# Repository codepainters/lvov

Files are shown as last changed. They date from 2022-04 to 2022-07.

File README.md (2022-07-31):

# ПК-01 Львoв

This repository contains all the documentation and notes about ПК-01 Львoв personal computer - probably the ugliest computer I've ever ~~attempted to repair~~ repaired :)

Judge yourself:

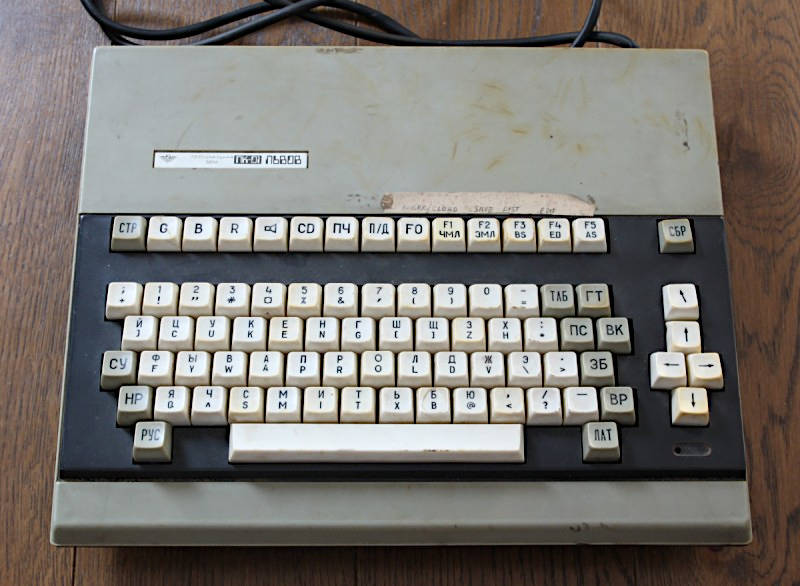
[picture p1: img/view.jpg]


Inside this repository:

* [original](orig) documentation collected from the Internet
* mainboard [schematics](sch)  redrawn into (hopefully) more readable form (KiCAD project + [PDFs](sch/pdf))
* some [datasheets](datasheets) of the chips used
* [ROM](roms) files, both from the Internet, as well as dumped from the desoldered EPROMs
* various notes and [docs](docs), including my design analysis  (look there for details)

And, last but not least, my [repair log](repair).

Enjoy!

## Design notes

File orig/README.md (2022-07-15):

# Original docs

The best quality scans of the original documentation I was able to find.

## Hardware docs

 * main PCB: [schematics](mainboard_schematics.djvu), [layout](mainboard_pcb.jpg)
 * keyboard PCB: [schematics](keyboard_schematics.djvu), [layout](keyboard_pcb.jpg)
 * power supply: [schematics](psu_schematics.djvu), [layout](psu_pcb.jpg), [overview](psu_overview.djvu)
 * [partlist](partlist.djvu)

## Manuals (russian)

* [User's manual](manual_rus.pdf)

* [BASIC reference](basic_manual_rus.pdf)

* [Programmers reference (PDF)](programmers_book_rus.pdf)

* [Programmers reference (UTF-8 TXT)](programmers_book_rus.txt)

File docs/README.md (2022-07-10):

# Docs and notes

Basic docs:

* [list of chips](chips.md) with both Russian and equivalent western symbols
* [map of the board](pcb_map.pdf) , also in [SVG](pcb_map.svg)
* [connectors pinout](connectors.md)
* [SCART cable](scart.md)

Below are my block-by-block analysis of the hardware:

* [CPU and PIO](cpu_pio.md)
* [Timing generator](timing.md)
* [RAM and ROM blocks](memories.md)
* [Video generator](video.md)

Note: I didn't bother with keyboard PCB, nothing interesting there. It's just yet another 8255...

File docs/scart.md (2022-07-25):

# Connecting to TV via SCART

It is possible to connect video output to SCART TV input, however some modifications are necessary:

* 12V rail should be connected via 330R resistor to unused pin 1 of the `X5` video output socket.
  Used to drive:

    * SCART Slow Blank (pin 8) to force the TV to switch to SCART with 4:3 aspect ratio
  
    * SCART Fast Blank (pin 16) to force the TV to switch to RGB signals (as opposed to CVBS default)

* `R`,`G` and `B` signals have to be inverted (it seems there was a different standard in the Soviet Union). This can be done by soldering `7402` quad NOR chip on top of `D62` chip (`К155ЛЛ1`/`7432`, quad 2-input OR gate) as follows.
  
  * solder pins 3, 6, 7, 8 and 14 of the `7402` chip to same numbered pins of `D62`
  * bend pins 2, 5 and 9 and solder to pins 3, 6 and 8, respectively 
  * bend pins 1, 4, 10, 11, 12 and 13 up
  * remove `C53`, `C54` and `C55` output capacitors
  * connect pins 1, 4 and 10 to "minus" pads of `C54`,  `C53` and `C55`, respectively

## Cable

Once the mod is in place, use the following cable:

| DIN-7 | SCART | Signal |
| ----- | --- | --- |
| 1 | 8 | Slow Blank |
| - | 16 | Fast Blank, connect to pin 8 via 330R resistor inside the plug |
| 2 | 20 | CVBS / Sync In |
| 3 | 7 | Blue |
| 4 | 11 | Green |
| 5 | 15 | Red |
| 6 | 4, 5, 9, 13 | GND |

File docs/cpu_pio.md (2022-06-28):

# CPU block

CPU block is a typical 8080 application:

* `D6` - CPU (`8080`)
* `D4` - clock generator and reset signal generator (`8224`)
* `D8` - data bus buffer / control signal latch (`8228`)

* `D2` and `D3` - address bus buffers (`8286`) - these buffers, controlled by `HLDA` signal, allow for DMA operation (not used by on-board hardware, exclusive bus access can be requested by external hardware connected to X1 connector, however).

Note:

* most signals are TTL level, but clock signals `Φ1` and `Φ2` go above 5V level.

* `D5B` flip-flop is used to synchronize CPU and RAM cycles

  * `~STSTB` goes low at the beginning of each CPU cycle, when CPU status is available on the data bus

  *  `ROM_OE` is high for EPROM access, as well as PIO I/O requests, thus `Q` output goes low for RAM access only

  * this in turn causes `READY` line to go low for each RAM request, CPU executes wait states

  * once RAM cycle is completed (see RAM controller description), `VIDEO_CPU` signal is pulsed low, `READY` goes high and CPU completes the RAM read/write cycle.

# PIO block

PIO block is a regular 8255 chip application.

* `D28` demux (`74155`) generates chip select signals:
  * `~CS0` (addresses `0xC0..CF`) selects `D30` PIO chip
  * `~CS1` (addresses `0xD0..DF`) selects second `8255` chip on the keyboard PCB
  * `~CS2` (addresses `0xE0..EF`) and `~CS3` (addresses `0xF0..FF`) signals are routed to `X1` connector (not used otherwise). 
  
* a little trick is used in the address decoder:
  * `~ROM_OE` goes low when `A15` and `A14` lines are high
  
  * however, during I/O cycles, 8080 CPU outputs 8-bit I/O address on both lower and higher byte of the address buss
  
  * it's therefore equivalent to decoding `A7` and `A6` lines, without any extra gates - neat! 

PIO lines are used as follows:

* Port A: `PA[7..0]` lines are routed to `X2` connector via `D31` buffer (`8286`), outputs only

* Port B:

  * `PB[7..0]` signals are routed directly to `X2`
  *  `PB[6..0]` also controls video color palette
  * `PB7` controls a speaker

* Port C:

  * `~PC0` is an output to a tape recorder

  * `~PC1` is used to alter RAM address mapping (see memory block description)

  * `PC4` is tape recorder input

  * `~PC2`, `~PC3`, `PC5`, `PC6`, `PC7` are routed to `X2` connector

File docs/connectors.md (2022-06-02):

# Connectors

## X1 - system bus

Pin 1 is bottom left, 2 is top left (as seen from the outside). 

| Signal | Bottom pin | Top pin | Signal |
| --- | --- | --- | --- |
| RESET  | 1 | 2 | ~CS3 |
| ~I/OR  | 3 | 4 | ~CS2 |
| ~INTA  | 5 | 6 | ~CS1 |
| A13 | 7 | 8 | - |
| A11 | 9 | 10 | +5V |
| A12 | 11 | 12 | - |
| ~MEMW  | 13 | 14 | - |
| A8 | 15 | 16 | - |
| A1 | 17 | 18 | GND |
| A0 | 19 | 20 | - |
| A9 | 21 | 22 | - |
| A2 | 23 | 24 | - |
| A7 | 25 | 26 | - |
| A15 | 27 | 28 | - |
| A14 | 29 | 30 | - |
| A3 | 31 | 32 | - |
| D3 | 33 | 34 | - |
| D2 | 35 | 36 | - |
| D4 | 37 | 38 | - |
| D1 | 39 | 40 | - |
| D5 | 41 | 42 | - |
| D0 | 43 | 44 | - |
| D6 | 45 | 46 | - |
| D7 | 47 | 48 | - |
| A10 | 49 | 50 | HLDA |
| ~MEMR  | 51 | 52 | A4 |
| ~I/OW  | 53 | 54 | A5 |
| INTE | 55 | 56 | A6 |
| INT | 57 | 58 | ~RESIN |
| HOLD | 59 | 60 | φ2TTL  |

## X2 - PIO

Pin 1 is bottom left, 2 is top left (as seen from the outside).

| Signal | Bottom pin | Top pin | Signal |
| --- | --- | --- | --- |
| PB2 | 1 | 2 | - |
| PB1 | 3 | 4 | - |
| PB0 | 5 | 6 | ~PC2 |
| PB3 | 7 | 8 | ~PC3 |
| PB4 | 9 | 10 | - |
| PB5 | 11 | 12 | - |
| PB6 | 13 | 14 | - |
| PB7 | 15 | 16 | - |
| - | 17 | 18 | - |
| PC5 | 19 | 20 | - |
| PC6 | 21 | 22 | - |
| PC7 | 23 | 24 | - |
| PA7 | 25 | 26 | - |
| PA6 | 27 | 28 | - |
| PA5 | 29 | 30 | - |
| PA4 | 31 | 32 | - |
| PA3 | 33 | 34 | - |
| PA2 | 35 | 36 | - |
| PA1 | 37 | 38 | - |
| PA0 | 39 | 40 | GND |

## X3 - tape recorder

| Pin  | Signal |
| ---- | --- |
| 1 | Output (to tape)  |
| 2 | GND |
| 3 | Input (from tape) |

## X4 - power supply

| Pin  | Signal |
| ---- | --- |
| 1 | +12V |
| 2 | +5V |
| 3 | GND |
| 4 | -5V |
| 5 | GND |

## X5 - video output

| Pin  | Signal |
| ---- | --- |
| 1 | - |
| 2 | VIDEO (CVBS mono) |
| 3 | B |
| 4 | G |
| 5 | R |
| 6 | GND |

## Keyboard

Keyboard is connected using wires soldered to numbered pads. Unfortunately, numbers do not match.

| Signal | Mainboard pad | Keyboard PCB pad |
| --- | --- | --- |
| D0 | 8 | 34 |
| D1 | 7 | 33 |
| D2 | 6 | 32 |
| D3 | 5 | 31 |
| D4 | 4 | 30 |
| D5 | 3 | 29 |
| D6 | 2 | 28 |
| D7 | 1 | 27 |
| A0 | 11 | 9 |
| A1 | 12 | 8 |
| ~I/OR  | 14 | 5 |
| ~I/OW  | 15 | 36 |
| RESET  | 13 | 35 |
| ~CS1 | 9 | 6 |
| ~RESIN | 10 | 10 |
| BUZZER | 16 | 16 |

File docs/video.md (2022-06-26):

# Video generator

Note:

* all video timing generation is based on `T[..]` signals from timing block
* additionally, `T_RST1` and `T_RST2` signals act as horizontal and vertical blanking, respectively
  * `T_RST1` is low for 256 horizontal pixels, it then goes 1 for 64 pixel times
  * `T_RST2` is low for 256 lines, it then goes high for 64 line periods
* `PB[0..7]` from `PIO` block is used to control color palette (see below)
* data is pulled directly from RAM data outputs - `RD[0..7]` bus

### Synchronization signals generator

Horizontal synchronization pulse (`~CCU`):

* is generated using `D38C` NAND gate (used as inverter) and `D44A` 4-input NAND gate
* pulse is active when `T[7] == 0 && T[6] == 1 && T_RST1 == 1`
* given that `T_RST1` is high for `T[10..4] == 100_xxxx`, sync pulse is high when `T[10..4] == 100_01xx`
* i.e. it goes high for `T[10..4]` in range 68..71, giving 4 cycles / 1.25 MHz = 3.2 μs width pulse

Vertical synchronization pulses (`~KCU`):

* is generated using `D41A` NAND gate (used as inverter) and `D44B` 4-input NAND gate

* pulse is active when `T[9] == 1 && T[15] == 1 && T[16] == 0 && T_RST2 == 1`

* given that `T_RST2` is high for `T[19..11] == 1_00xx_xxxx`, sync pulse is high when `T[19..11] == 1_0001_xxxx`and `T[9] == 1`

  * 16 pulses are generated for equivalent of 16 scan lines - 16 * 1/15625 Hz = 1024 μs 
  * for each scan line period `T[9]` is low for 32 clocks of modulo 80 counter, then high for 32 cycles and low again for 16 cycles. 
  * this gives 32 / 1.25 MHz = 25.6 μs low,  then 25.6 μs high, then 12.8 μs low

Horizontal and vertical sync pulses are combined using `D41B`NAND gate.

### Pixel shift register

Parallel load shift register `74198` is used to convert RAM contents into consecutive pixels. Data is loaded from RAM directly (`RD[7..0]`bus), load and shift signals are timed by the `T[3..0]` signals from the timing blocks, using `D33B` , `D37A` and `D37B` gates. 

Video SR timing

During a single RAM cycle (see RAM controller description) one byte is loaded from RAM and 4 shift operations are performed - each byte describes 4 pixels, 2 colors per pixel. Byte layout is as follows, where `P<n>.1`and `P<n>.0` denote, respectively, higher and lower color bit of `n-th` pixel in byte:

| 7 | 6 | 5 | 4 | 3 | 2 | 1 | 0 |
| ---- | ---- | ---- | ---- | ---- | ---- | ---- | ---- |
| P0.1 | P1.1 | P2.1 | P3.1 | P0.0 | P1.0 | P2.0 | P3.0 |

### Composite signal generator

Generation of the composite video signal works as follows:

* shift register outputs are converted into 4 brightness levels using `R27` and `R28` resistors
* `D62D` and `D29A` gates are responsible for blanking the output when `T_RST1` or `T_RST2` is high, i.e. during horizontal or vertical retrace, respectively.
* `D61D` and `D29B` gates, together with `R19`, `R20` and `R23` resistors generate proper synchronization levels.

Note: CVBS output is also used as synchronization signal for color monitor.

### RGB signal generation

* 2 color bits from shift register are used as `D56` demux select inputs. 
  * demultiplexer outputs are used to select one of the 4 colors
  * active-low enable inputs of the demultiplexer are controlled by `T_RST1` and `T_RST2` signals, effectively blanking the video when `T_RST1` or `T_RST2` is high
* selected color is  converted into R, G and B signals by combining with `PB[6..0]` signals (effectively limited color palette control)

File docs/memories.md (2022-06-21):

# Memories

## ROM

* 8 chips, 2716 equivalent
* `D5A` flip-flop is responsible for ROM remapping
  * at reset,  `~Q` of `D5A` is low, thus `~ROM_OE` is always low and ROM is effectively mapped 4 times in the CPU address space
  * when CPU writes any I/O port for the first time,  `~Q` goes high, and ROM is mapped into last 16 KB of CPU address space (`0xC000..0xFFFF`)
* this mapping trick is necessary for the CPU to boot from ROM at address 0, the code then perform dummy I/O write to map ROM into its target location 

## RAM

* 8 chips, 4164 DRAM equivalent, one per bit, 64kB total.
* memory refreshing done while generating video.
* RAM output data bus `RD[7..0]` is separated from CPU data bus `D[7..0]` by 8282 latch (`D27`). Latch is strobed by `RAM_RD_STB` signal from RAM controller (see below), output enable is active for every memory read that is not EPROM read (`ROM_OE == 0 && ~MEMR == 0`).
* Quad 74153 multiplexers select row / column address and address source (CPU or timing counters for video output).

### Addressing 

* for video generator access:
  * 2 MSB bits are set to 1, bits `13..0` are formed from `T[18..11]`,  `T[9..4]`
  * video is thus generated from 256 x 64 bytes = 16 kB, 4 pixels each, located at `0xC000..0xFFFF` in the CPU address space
* for CPU access `A[14..0]` signals are used as is, while most significant bit is combined with `~PC1` 
  * if `PC1 == 1`, the `A[15]` is used as MSB
  * if `PC1 == 0`, MSB is forced to 1, effectively higher 32kB of RAM are mapped twice in the CPU address space

This mapping is necessary to manipulate video buffer from ROM code, as ROM is also mapped to the last 16 kB of address space. This mapping is explained as follows in the programmer's manual:

> In normal mode, the on-screen RAM is disconnected from the MP buses and cannot be accessed by software. For the MP to work with this RAM area, it can be connected instead of the main RAM section at addresses 4000H-7FFFH ( 16384-32767 ) using bit 1 of the C2H port ( 194 ) ( 0 - Open Video RAM, 1 - Close Video RAM ). However, it should be remembered that with such a switch, the main RAM area 0000H-7FFFH ( 00000-32767 ) is disconnected from the MP buses, so procedures that work with open video memory cannot be placed below 8000H ( 32768 ). All the main ROM routines that work with the screen "do not forget" to close the video memory before returning and there is no such problem with them.

## RAM controller

RAM controller is responsible for generating all RAM-related signals - `~RAS`, `~CAS`, `~WE`, etc.

* controller is driven by `T[3..0]` signals from timing counter, i.e. the whole sequence (let's call it *RAM cycle*) takes 16 periods of 20 MHz `OSC` clock.
  * it is further divided into *video RAM cycle* (cycles 0 - 7), when video controller reads next byte from RAM, and *CPU RAM cycle* when CPU can read or write a RAM byte.
  * the *CPU RAM cycle* is optional, it happens only if the CPU actually requested memory access
* signals `K0` and `K1` control RAM address multiplexer:
  * `K0` selects row (when 0) or column (when 1) address
  * `K1` selects source of RAM address - timing/video circuitry (when 0), or CPU (when 1)

Following diagram shows a full RAM cycle.

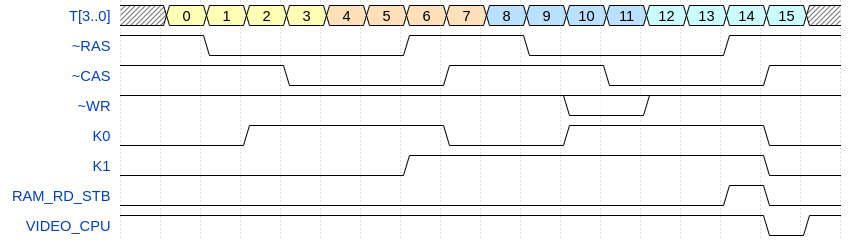
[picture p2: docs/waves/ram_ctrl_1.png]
ram_ctrl_1


Note:

* `K1` goes high only if there is actual CPU RAM cycle
  * when `~MEMR` or `~MEMW` goes low, `D42A` flip-flop catches `ROM_OE` state, which is high during EPROM access. Thus, its `~Q` output goes high only at the beginning of the RAM read or write cycle;
  * at the beginning of period 6, this state is copied to `D42B`, thus `K1` goes high if and only if the CPU requested RAM read/write;
  * `K1` them remains high until a pulse of `VIDEO_CPU` signal (which happens only if `K1` was high)
  * CPU enters wait states until `VIDEO_CPU` pulse signals end of cycle (see CPU block description)
* signals `~WR` only goes low for memory write, obviously
* signal `RAM_RD_STB` is used to control the D27, which latches the byte from RAM data bus `RD[7..0]` and outputs it to CPU data bus `D[7..0]` (data is latched on the falling edge)
* signals `~RAS`, `~CAS` remain inactive (i.e. high) for periods 8..15 when there is no CPU RAM access happening  

* the `D47C` is somewhat peculiar, my understanding: this gate ensures, that there is at least one `VIDEO_CPU` pulse during reset, to make sure CPU doesn't get stuck in wait state.

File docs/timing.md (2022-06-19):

# Timing block

The timing block consist of  3 cascaded counters, driven by `OSC` 20 MHz clock. 

### Modulo 16 counter

* uses a single `74LS193` counter (`D34`)

* it overflows with 20 / 16 = 1.25 MHz frequency

* it drives signals `t[0..3]`, which:
  * control RAM access timing
    * when `T[3] == 0` video controller reads a next byte (4 pixels) to be displayed
    * when `T[3] == 1` CPU can issue a RAM read/write
  * control pixel shift register in the video block

### Modulo 80 counter

* uses `74LS193` counter (`D35`) and `74LS93` counter (`D36`) cascade
* drives `T[4..10]` signals, which:
  * provide part of RAM address for the video generator
  * are used to generate horizontal synchronization signal in the video block
* modulo counting is done in a somewhat peculiar way:
  * `D37C` AND gate output (`T_RST1` signal) goes high when counter gets to 64 (`T[10..4] == 100_0000`)
  * when it reaches 80 (`101_0000`), `D37C` output goes low
  * this triggers `D43A` monostable multivibrator, which outputs short (~500-600 ns) pulse, resetting the counter
* `D37C` output (`T_RST1` signal) is also used by the video block (it is high for counts in `64..79` range), i.e. 16 cycles of `T[3]` which gives `12.8 µs`
* this counter block overflows with 15625 Hz frequency (which happens to be the horizontal deflection frequency)

### Modulo 320 counter

* uses `74LS93` counters (`D39` and `D40`), followed by `7474` flip-flop (`D45A`)
* drives `T[11..19]`signals (used as part of RAM address in the video block, and to generate vertical sync pulses)
* modulo counting is done in the same manner as in modulo 80 counter block
* `D37D` output (`T_RST2` signal) goes high when `T[19..11]` is `1_0000_0000` and goes back low when `1_0100_0000` is reached, triggering reset, the pulse width is `64 * 1/15625 Hz = 4.096 ms`
* this counter wraps every 15625 / 320 = ~48.82 Hz (which is the screen refresh rate) 

### Counter synchronization

Note: reset signals from both `74123` multivibrators (i.e. `D43A` and `D43B`) are combined using `D38B` NAND gate, combined signal is sued to reset modulo 80 counter.  My understanding is that this is for modulo 80 counter to start in sync with  modulo 320 counter.

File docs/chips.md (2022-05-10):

# Chip list

| Designator | Orig. type | Equivalent | Desciption |
| --- | --- | --- | --- |
| D1 | К155ЛА4 | 7410 | Triple 3-input NAND gates |
| D2 | КР580ВА86  | i8286 | Octal bus trasceiver |
| D3 | КР580ВА86  | i8286 | Octal bus trasceiver |
| D4 | КР580ГФ24  | i8224 | Clock generator/driver for 8080A CPU |
| D5 | К155ТМ2 | 7474 | Dual D-type flip-flops |
| D6 | КР580ВМ80  | i8080 | 8080A CPU |
| D7 | К155ЛИ1 | 7408 | Quadruple 2-input AND gates |
| D8 | КР580ВК28  | i8228 | System controller and bus driver for 8080A CPU |
| D9 | К555ИД7 | 74LS138 | 1-of-8 decoder/demultiplexer |
| D10-D17 | К573РФ5 | 2716 | 8x 2kB EPROM |
| D18 | К155ЛЛ1 | 7432 | Quad 2-input positive-OR gates |
| D19-D26 | КР565РУ5Д  | 4164 | 8x 64k x 1 DRAM |
| D27 | КР580ИР82  | i8282 | Octal latch |
| D28 | К155ИД4 | 74155 | Dual 2-line to 4-line decoders/demultiplexers |
| D29 | К155ЛА8 | 7401 | Quad 2-input NAND gates with open-collector outputs  |
| D30 | КР580ВВ55А | i8255 | Programmable peripheral interface |
| D31 | КР580ВА86  | i8286 | Octal bus trasceiver |
| D32 | КР589АП26  | i8226 | Bidirectional bus driver |
| D33 | КР531ЛН1 | 74S04 | Six inverters |
| D34 | К555ИЕ7 | 74LS193 | Synchronous 4-bit up/down counter |
| D35 | К555ИЕ7 | 74LS193 | Synchronous 4-bit up/down counter |
| D36 | К555ИЕ5 | 74LS93 | 4-bit binary counter |
| D37 | К155ЛИ1 | 7408 | Quadruple 2-input AND gate |
| D38 | К155ЛА3 | 7400 | Quad 2-input NAND gates |
| D39 | К555ИЕ5 | 74LS93 | 4-bit binary counter |
| D40 | К555ИЕ5 | 74LS93 | 4-bit binary counter |
| D41 | К155ЛА3 | 7400 | Quad 2-input NAND gates |
| D42 | К155ТМ2 | 7474 | Dual D-type flip-flops |
| D43 | К155АГ3 | 74121 | Monostable multivibrator with Schmitt-trigger inputs |
| D44 | К155ЛА1 | 7420 | Dual 4-Input positive-NAND gates |
| D45 | К155ТМ2 | 7474 | Dual D-type flip-flops |
| D46 | К155ТМ2 | 7474 | Dual D-type flip-flops |
| D47 | К155ЛИ1 | 7408 | Quadruple 2-input AND gates |
| D48 | К155ТМ2 | 7474 | Dual D-type flip-flops |
| D49 | К155ИД7 | 74LS138 | 3-line to 8-line decoders/demultiplexers |
| D50 | К155ИД7 | 74LS138 | 3-line to 8-line decoders/demultiplexers |
| D51 | К155КП2 | 74153 | Dual 4-line to 1-line data selectors/multiplexers |
| D52 | К155КП2 | 74153 | Dual 4-line to 1-line data selectors/multiplexers |
| D53 | К155КП2 | 74153 | Dual 4-line to 1-line data selectors/multiplexers |
| D54 | К155КП2 | 74153 | Dual 4-line to 1-line data selectors/multiplexers |
| D55 | К155ИР13 | 74198 | 8-bit shift register |
| D56 | К155ИД4 | 74155 | Dual 2-line to 4-line decoders/demultiplexers |
| D58 | УД708 | LM741 | Op-amp |
| D59 | К155ЛЛ1 | 7432 | Quad 2-input positive-OR gates |
| D60 | К155ЛИ1 | 7408 | Quadruple 2-input AND gates |
| D61 | К155ЛП5 | 7486 | Quad 2-input EX-OR gates |
| D62 | К155ЛЛ1 | 7432 | Quad 2-input positive-OR gates |

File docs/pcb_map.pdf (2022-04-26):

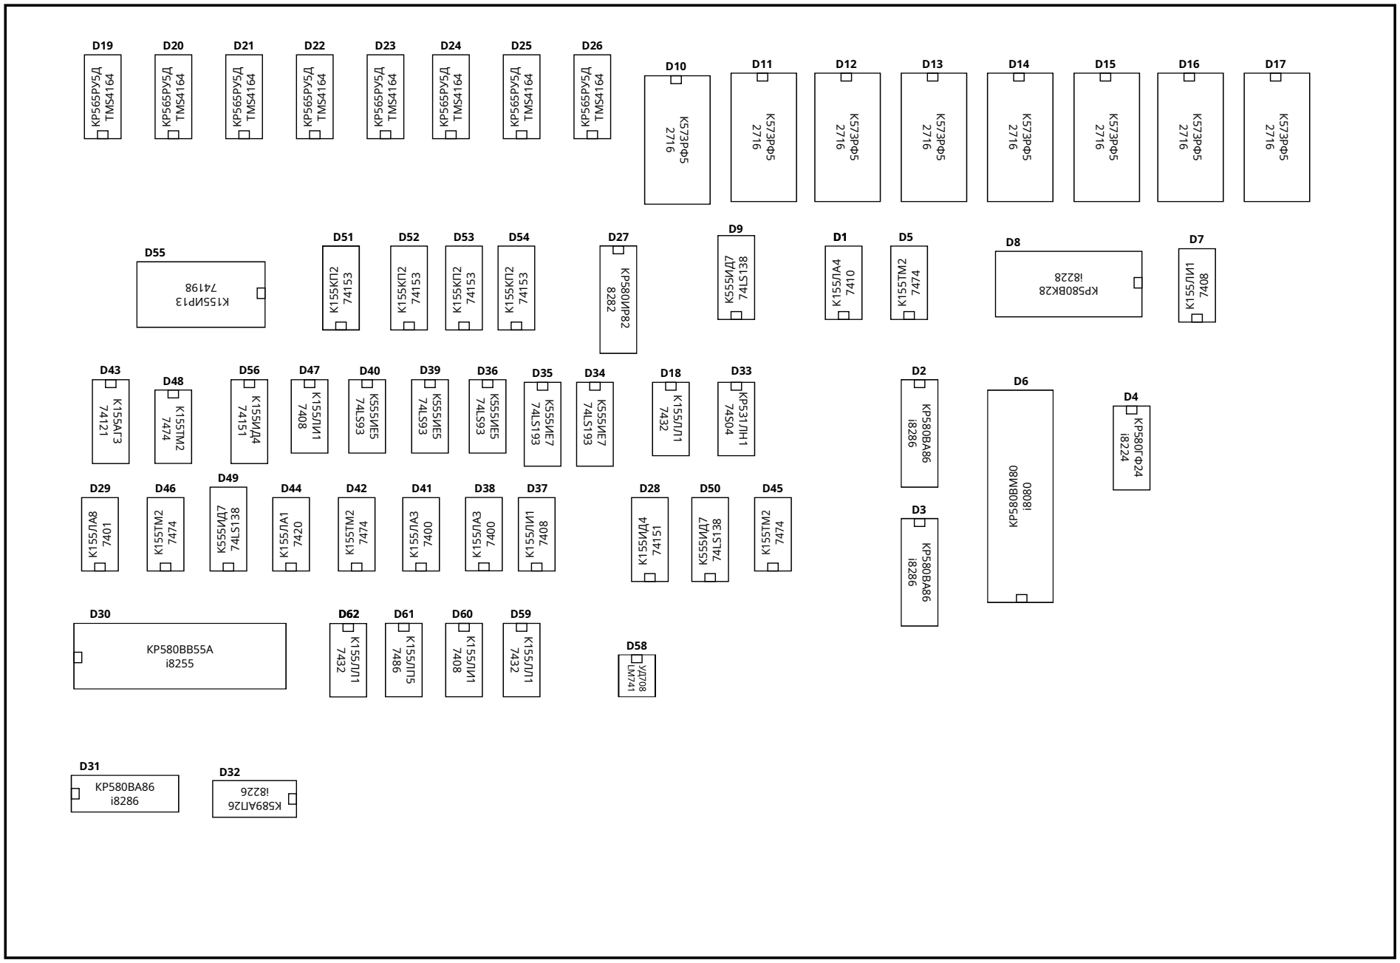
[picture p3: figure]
KP565РУ5Д TMS4164

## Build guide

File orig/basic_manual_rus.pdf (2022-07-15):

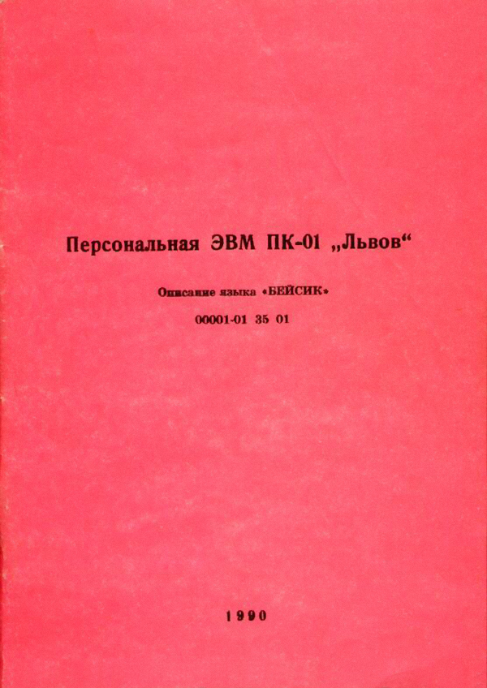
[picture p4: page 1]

ПЕРСОНАЛЬНАЯ ЭВМ ПК-01 "ЛЬВОВ" Описание языка БЕЙСИК 589.0196339.OOOO1-O1 35 01

УТВЕРЖДЕН
589.0196339.OOOO1-O1 35 O1-ДУ

ПЕРСОНАЛЬНАЯ ЭВМ ПК-01 "ЛЬВОВ"
Описание языка БЕЙСИК 589.0196339.OOOO1-O1 35 01

СОДЕРЖАНИЕ

Аннотация
1. Общие сведения и способ описания языка
1.1. Назначение языка
1.2. Способ описания языка
2. Элементы и основные конструкции языка
2.1. Набор символов
2.2. Структура программы и комментарии к программе
2.3. Стандартные функции
3. Элементы данных
3.1. Числовые и символьные данные
3.2. Переменные с индексами
4. Выражения и оператор присваивания 4 1. Арифметические выражения
4.2. Символьные функции и выражения
4.3. Логические выражения
4.4. Оператор присваивания
5. Операторы управления
5.1. Операторы перехода и оператор STOP
5.2. Условные операторы
6. Оператор цикла FOR-NEXT
7. Функции
8. Подпрограммы
8.1. Операторы GOSUB и RETURN
8.2. Оператор ON - GOSUB
9. Средства машинной графики и средства управления звуком
9.1. Формирование изображения на экране терминала
9.2. Графические операторы
9.3. Средства управления звуком
10. Средства работы на уровне машинных команд
11. Работа в режиме непосредственного исполнения
11.1. Режим калькулятора
11.2. Использование режима непосредственного исполнения при отладке программ
12. Операторы ввода - вывода
12.1. Операторы READ, DATA, RESTORE
12.2.Оператор INPUT
12.3.Оператор PRINT
12.4. Дополнительные возможности оператора PRINT
12.5. Управление курсором
13. Средства подготовки и отладки программ
13.1. Директивы интерпретатора и средства отладки программы
13.2. Диагностические сообщения интерпретатора
13.3. Средства редактирования
Приложение: Дополнительные операторы БЕЙСИКа

АННОТАЦИЯ

В настоящем документе содержится описание языке БЕЙСИК, правила составления и выполнения программ на языке бейсик.
В документе описаны основные элементы языка БЕЙСИК: константы, переменные, массивы. Представлены операторы, функции, которые содержит интерпретатор БЕЙСИК, а также способ написания функций, составленных самим пользователем.
Описаны операторы для работы с массивами. Представлены команды для отладки и запуска программных файлов.
Описана система ввода-вывода.

### 1. ОБЩИЕ СВЕДЕНИЯ И СПОСОБ ОПИСАНИЯ ЯЗЫКА

### 1.1. Назначение языка

Язык БЕЙСИК является одним из простых в изучении языков программирования.
Предназначен | для | решения | вычислительных | и | планово-экономических | задач,
проведения инженерных расчетов, разработки тестовых, игровых, учебных программ. Программа на языке БЕЙСИК представляет собой набор операторов, объединенных в логические блоки.
Диалоговый режим интерпретатора БЕЙСИК облегчает отладку программ. Возможна работа в режиме непосредственного исполнения.

### 1.2. Способ описания языка

При описании форматов предложений (синтаксиса предложений) языка применяются следующие условные обозначения: заглавные буквы, знаки пунктуации и другие специальные знаки (за исключением угловых, квадратных и фигурных скобок), изображающие конструкции, которые должны быть записаны в таком же виде, как показано в приводимом формате.
Последовательности слов, записанные строчными буквами и заключенные в угловые скобки <и>, определяют синтаксические конструкции, которые записаны где-либо в другой части данного документа. Эти слова в какой-то мере отражают природу и смысл таких конструкций. Если последовательность конструкций заключена в квадратные скобки [и], то это означает, что данная последовательность является необязательной и может быть опущена. Варианты последовательностей конструкций, заключенные в фигурные скобки {и}, являются альтернативными и должен быть выбран один из этих вариантов.

### 2. ЭЛЕМЕНТЫ И ОСНОВНЫЕ КОНСТРУКЦИИ ЯЗЫКА

### 2.1. Набор символов

В языке БЕЙСИК ПК-01 используются следующие символы:
1) 26 букв латинского алфавита (А, В, С, D, Е, F, G, Н, I, J , К, L, М, N, 0, P, Q, R, S, Т, U, V, W, X, У , Z).
2) 31 буква русского алфавита (А, Б, В, Г, Д, Е, Ж, 3, И, Й, К, Л, М, Н, О, П, Р, С, Т, У, Ф, X, Ц, Ч, Ш, Щ, Э, Ы, Ю, Я, Ь), твердый знак (Ъ) в тексте отображается символом "_".
3) 10 десятичных: цифр (0, I, 2, 3, 4, 5, 6, 7, 8, 9).
4) знаки арифметических операций:
+ - плюс;
- - минус;
* - звездочка;
/ - наклонная черта (знак деления);
^ - стрелочка (знак возведения в степень).

5) знаки операций отношения: < - знак меньше;
> - знак больше;
= - знак равенства.
6) синтаксические знаки;
( - открывающая круглая скобка; ) - закрывающая круглая скобка; , - запятая;
. - точка;
" - кавычки;
; - точка с запятой;
: - двоеточие.
7) специальные знаки:
$ - знак денежной единицы (признак символьных данных);
? - вопросительный знак;
" " - пробел.

Некоторые комбинации символов имеют специальное значение: <= - меньше или равно;
>= - больше или равно;
<> - не равно.

Употребление слов русского алфавита ограничено по сравнению с английскими буквами (как правило, буквы русского алфавита употребляются только как элементы символьных констант и в операторах комментария).

### 2.2. Структура программы и комментарии в программе

В языке программирования БЕЙСИК программа состоит из строк операторов. Каждая строка начинается с номера строки. Номер строки - это целое десятичное число в диапазоне от 0 до 65629. За номером строки располагается служебное слово, определяющее характер действия и текст оператора.
Номера строк служат метками операторов, а также указывают порядок выполнения программы.
При составлении программы рекомендуется нумеровать строки с определенным шагом (например: 10,20,30 и т.д.). Это позволит при отладке вставлять пропущенные или дополнительные строки.
Программа завершается оператором END. Программа также может выполняться без наличия оператора END.
В одной строке может быть записан один или несколько операторов. При записи в одной строке нескольких операторов их следует разделять двоеточием (:). Однако длина строки не должна превышать 254 знаков.
При вводе программы с клавиатуры терминала каждую строку заканчивают нажатием клавиши ВК (возврат каретки).
При вводе или написании программы возникает необходимость в дополнительных пояснениях к программе, предназначенных для объяснения назначения программы, описания назначения ее переменных данных, описания алгоритма и т.п. Для этих целей используется оператор REM. Формат оператора:

<номер строки> REM <сообщение>

где сообщение может содержать любые печатные знаки клавиатуры.
Сообщение, следующее за словом REM, никаких действий интерпретатора не вызывает.

### 2.3. Стандартные функции

Для вычисления наиболее встречающихся математических функций в БЕЙСИК включены следующие стандартные функции:
ABS (X) - модуль
SGN (X) - знак Х (-1 при Х<0; 1 при Х>0; 0 при Х=0)
INT (X) - наибольшее целое число, которое меньше или равно Х COS (X) - косинус Х (cos X)
SIN (X) - синус X (sin x)
TAN (X) - тангенс Х (tg X)
ATN (X) - арктангенс Х (arctg X)
SQR (X) - корень квадратный от Х (sqrt X)
ЕХР (X) - экспонента Х (e^X)
LOG (X) - натуральный логарифм (ln X)
RND (X) - выборка случайного числа в интервале (0,1) (обращение к генератору случайных чисел).
Аргументом функции может быть любое арифметическое выражение.
Аргументы тригонометрических функций SIN, COS, TAN должны задаваться в радианах. В функции RND (X) необходимо указать фиктивный аргумент, например X.

### 3. ЭЛЕМЕНТЫ ДАННЫХ

### 3.1. Числовые и символьные данные

Для того чтобы интерпретатор мог обеспечивать формирование соответствующих команд для обработки информации, ему должен быть известен тип данных, которые подлежат обработке. В языке БЕЙСИК ПК-01 используются данные двух типов:
1) числовые данные;
2) символьные данные.
Числовые | данные | представляются | десятичными | числами | - | целыми | и
действительными.
Целое число - это конечная последовательность цифр с возможным знаком плюс или минус перед ней, например: 1986, -36, +125.
Действительные | десятичные | числа | записываются | двумя | способами | - | с
использованием десятичной точки (в естественной форме) или с использованием латинской буквы E (в нормализованной форме), например: +14.6, -3.75, 2.5, 1E-10, -36.7Е5, +25Е-4.
Диапазон числовых данных от 0,94.10^-38 до 1,7.10^38. Разрядность - 6 десятичных цифр.
Символьная константа (строка) - это последовательность символов из набора символов БЕЙСИК ПК-01, заключенных в кавычки, например: "BASIC", "2+3", "ЛЬВОВ", "АТЫ БАТЫ".
Символьная строка может содержать от 0 до 255 символов. Объем памяти, выделенной под символьные константы можно определить при помощи функции FRE (см. раздел 11).

Величины, значения которых в процессе выполнения программ могут меняться, называются переменными. В БЕЙСИКе ПК-01 употребляются два типа переменных -числовые и символьные. Числовая переменная обозначает место в памяти компьютера, в которое будет записано числовое значение. Символьная переменная резервирует место для символьных значений. В БЕЙСИКе употребляются простые переменные и переменные с индексами. Переменные с индексами предназначены для обозначения элементов массивов и описываются дальше.

Числовая переменная обозначается в БЕЙСИКе ПК-01 идентификатором, который состоит из одной или двух латинских букв или латинской буквы и последующей цифры, например: X, P1, RD, A2.
Переменным присваиваются значения с помощью оператора присваивания LET, операторов INPUT, READ, которые будут описаны далее. Перед выполнением всем переменным присваивается значение 0.

Наряду с числовыми переменными в языке БЕЙСИК ПК-01 используются символьные переменные, которые могут принимать значения символьных констант. Любое имя переменной, за которой следует знак $ (знак денежной единицы), указывает символьную переменную, например: A$, A2$, DM$, RG$.
Над символьными переменными и (или) константами могут выполняться следующие операции отношения: =, <>, <, <=, >, >=.
При выполнении перечисленных операций сравнения каждая символьная строка представляется в виде целых чисел. Каждому символу отвечает целое число (в соответствии с кодом КОИ-7). При сравнении строк их длины предварительно выравниваются путем приписывания справа к более короткой недостающего числа пробелов.

### 3.2. Переменные с индексами

Массивом называется конечная совокупность величин, обозначенных одним и тем же идентификатором и поставленных в соответствие упорядоченным набором значений некоторой системы целочисленных параметров, каждый из которых может принимать любое значение, начиная с нуля и кончая некоторым своим наибольшим значением. Элемент массива называется переменной с индексами. В одном массиве могут содержаться величины только одного типа. Поэтому различают массивы числовых данных и массивы символьных данных.
Общий идентификатор всех величин, входящих в состав массива, называется идентификатором массива. Им может быть любое принятое в БЕЙСИКе ПК-01 имя переменной. При этом идентификаторы массивов символьных величин оканчиваются знаком денежной единицы ($).
Индексная переменная обозначается записью, состоящей из идентификатора массива и следующего за ним в круглых скобках списка индексов. Число индексов не должно превышать два и в списке они разделяются запятой. Индекс в общем случае является арифметическим выражением. В момент использования индекс должен иметь положительное целое значение. Индексы элементов массивов принимают значения целых чисел, начиная с 0, т.е. для одномерного массива элементы нумеруются A(0), А(1), А(2) и т.д.; соответственно элементы двумерного массива - В(0,0), В(0,1), В(0,2) ... В(1,0), В(1,2) и т.д.
Для каждого массива в программе должен быть указан его максимальный размер, т.е. максимальные значения, которые могут принимать индексы. Это нужно для того, чтобы интерпретатор мог зарезервировать соответствующий объем памяти. Информацию об идентификаторах массивов и их размерностях указывают в операторе DIM, который имеет следующий формат:

<номер строки> DIM V1(M1), V2(M2) ... Vn(Mn)

где V1 - идентификатор массива;
M1 - размерность массивов V1 (одно или два целых числа, разделенных запятыми).
Пример:
10 DIMA(10),MT(3,4),S$(6)
Под массив A отводится 11 элементов, под матрицу MT - 4х5 = 20 элементов и под символьный массив S$ - 7 элементов. Описание массивов должно предшествовать использованию их элементов в других операторах.
Если в программе размерность индексной переменной не указывается с помощью оператора DIM, то по умолчанию принимается размерность 10 в каждом измерении. Оператор DIM относится к невыполняемым операторам.
Первоначально все элементы описанных массивов имеют нулевые значения. Для изменения значений индексных переменных используют те же операторы БЕЙСИК ПК-01, что и в случае простых переменных: оператор присваивания READ и INPUT.

### 4. ВЫРАЖЕНИЯ И ОПЕРАТОР ПРИСВАИВАНИЯ

### 4.1. Арифметические выражения

Арифметические | выражения | представляют | собой | произвольную | комбинацию
идентификаторов, констант и функций, разделенных знаками операций и круглым скобками так, чтобы образовать имеющее смысл математическое выражение. Допустимы следующие знаки операций:
+ - сложение;
- - вычитание;
* - умножение;
/ - деление;
^ - возведение в степень.

Если в выражении отсутствуют круглые скобки, определяющие порядок выполнения операций, то они выполняются в следующей последовательности:
- вычисление функций;
- возведение в степень;
- умножение и деление;
- сложение и вычитание.

Операции одного ранга выполняются последовательно слева направо (включая и операции возведения в степень).
Над целыми числами могут выполняться логические операции AND, OR, NOT. Эти операции выполняются поразрядно над двоичными представлениями целых чисел в дополнительном коде. Результатом логической операции является целое число, состоящее из последовательности битов, образованных в результате применения данной логической операции к битам заданных операндов.
Пример:
2OR3=3
2AND3=2
NOT3=-4

Чтобы понять эти результаты, необходимо помнить, что целые десятичные числа в ПК-01 представляются как двоичные числа в дополнительном коде (при этом старший разряд отводится под знак числа).
Если в арифметических выражениях употребляется и арифметические, и логические операции, то при отсутствии скобок логические операции выполняются после арифметических, причем в таком порядке старшинства между собой: NOT, AND, OR. Логические операнды одного ранга выполняются слева направо.

### 4.2. Символьные функции и выражения

Под символьным выражением понимается любая последовательность символьных констант, переменных и функций, соединенных с помощью операции конкатенации (+). Операция конкатенации определяет, что два операнда соединяются вместе и образуют новую строку символов, где за последним символом левого операнда сразу же следует первый символ правого операнда. Длина строки, полученной в результате, равна сумме длин операндов, например: "ТРАМ" + "ТАРАРАМ" = "ТРАМТАРАРАМ".
В БЕЙСИКе ПК-01 могут использоваться следующие функции над символьными строками:
LEFT$(<строка>, N) - выделяет из "строки" подстроку с первого до N-го знака. Здесь и далее над аргументом <строка> будем понимать символьное выражение, а аргумент N (в других функциях N1, N2) должен быть целым числом или выражением, принимающим целочисленное значение. Если N равно или больше длины отроки, выдается вся строка. Если N=0, выдается пустая строка. Например: функция LEFT$("ABCD", 3) дает результат "АВС".
RIGHT$(<строка>, N) - выделяет наиболее правые символы "строки". Если N равно или превышает длину строки, выдается вся строка. Если N=0, выдается пустая строка. Например: функция RIGHT$("ABODE", 2) дает строку "DE".

MID$(<строка>, N1, N2) - проверяет "строку" и возвращает N2 символов, начиная с позиции N1. Если N1 больше, чем строка, MID$ возвращает пустую строку. Например: функция MID$("ABCDE", 2, 3) дает результат "BCD".
LEN(<строка>) - функция определяет длину строки, то есть возвращает целое число, равное количеству символов в строке. Например: функция LEN("ABCDE") дает результат 5.
VAL(<строка>) - функция преобразует цифровую строку в числовое значение. Строка может включать цифры, знаки "+", "-", "." и "Е". Если строка содержит другие знаки, то значение функции равно нулю. Например: функция VAL("1E3") дает числовое значение 1000.
STR$(<выражение>) - действие функции противоположно действию функции VAL -
она | преобразует | числовое | значение | в | цифровую | строку. | Например: | функция
STR$(9372) дает строку "9372".
ASC(<строка>) - функция возвращает код КОИ-7 первого символа указанной строки. Например: функция ASG("ABCD") дает значение 65.
CHR$(<выражение>) - функция возвращает символ КОИ-7, код которого равен значению выражения. Выражение должно приводиться к целому числу между 0 и 255. Например: функция CHR$(65) дает символ "А".
HEX$(<выражение>) - функция возвращает строку, значение которой эквивалентно шестнадцатеричному представлению выражения. Например: функция HEX$(32) дает строку "20".
INKEY$ - функция (без аргумента), предназначенная для опроса клавиатуры. Функция возвращает пустую строку, если не нажата ни одна клавиша, или строку с символом, соответствующим нажатой клавише.

### 4.3. Логические выражения

Логическим выражением называют некоторую комбинацию констант и переменных (числовых или символьных), соединенных знаками операции отношения, логических и арифметических операций и скобками, и принимающие только два значения - "истина" или "ложь" (0 или 1).
Для логических выражений установлен следующий порядок выполнения действий:
1) сначала действует правило скобок;
2) вычисляются значения функций;
3) выполняются арифметические операции в следующем порядке:
- возведение в степень;
- умножение и деление;
- сложение и вычитание.
4) выполняются операции отношения: = - равно;
< - меньше;
<= - меньше или равно;
> - больше;
>= - больше или равно;
<> - не равно.
5) логические операции в следующем порядке: NOT - логическое отрицание;
AND - конъюнкция;
OR - дизъюнкция.

Операция отношения устанавливает определенные отношения между числовыми или символьными величинами. Отношение имеет формат:

<выражение 1 (арифметическое или символьное)> <знак операции отношения> <выражение 2 (арифметическое или символьное>

Символьное отношение означает последовательное попарное сравнение слева направо символов строк операндов в соответствии с упорядоченностью символов кода КОИ-7.
Результат выполнения операций отношения есть "истина", если выражения удовлетворяют отношению, и "ложь" в противном случае.

### 4.4. Оператор присваивания

Оператор присваивания LET имеет формат:

< номер строки> LET <переменная> = <выражение>

Действие этого оператора состоит в вычислении значения выражения, записанного справа от знака равенства, и присвоении этого значения переменной, указанной слева от знака равенства.
Пример:
10 LETA=6.3
20 LETB=B+2
30 LETA$="BASIC"
В | операторе | присваивания | могут | употребляться | переменные | числового | и
символьного типа, простые и с индексами. Необходимо, чтобы тип переменной совпадал с типом выражения (т.е. числовая переменная и арифметическое выражение, символьная переменная и символьное выражение).
БЕЙСИК ПК-01 позволяет опускать слово LET в операторе.
Пример:
10 A=6.3
20 B=B+2
30 A$="BASIC"

### 5. ОПЕРАТОРЫ УПРАВЛЕНИЯ

### 5.1. Операторы перехода и оператор STOP

В программе на языке БЕЙСИК ПК-01 операторы выполняются в порядке возрастания номеров строк. Изменение порядка выполнения оператора производятся с помощью операторов управления. К этой группе операторов относятся операторы перехода, оператор STOP, условные операторы и оператор цикла.
В языке БЕЙСИК ПК-01 существует два вида операторов перехода - оператор безусловного перехода GOTO и оператор перехода по вычислению ON - GOTO. Оператор безусловного перехода GOTO используется в том случае, когда в программе требуется осуществить безусловный переход к какой-либо другой строке с нарушением естественного порядка выполнения операторов программы, задаваемого номерами строк. Формат оператора GOTO:

<номер строки> GOTO <номер строки 1>

где <номер строки> - это номер строки, к которой осуществляется переход. Номер строки, к которой осуществляется переход в программе, может быть либо больше, либо меньше текущего номера строки.

Оператор ON - GOTO позволяет осуществить переход к одной из нескольких указанных строк в зависимости от того, какое значение имеет выражение во время выполнения оператора. Этот оператор имеет следующий формат:

<номер строки> ON <арифметическое выражение> GOTO <список номеров строк>

Во время выполнения оператора вычисляется выражение, и целая часть его используется в качестве указателя перехода на один из перечисленных номеров строк.
Пример:
50 ONPGOTO100,140,180
Здесь оператор передает управление строке 100, если P=1, строке 140, если P=2, или строке 180, если P=3. Любые другие значения P (не выходящие за пределы 0-255) приводят к передаче управления на следующий оператор.

Оператор | STOP | вызывает | прекращение | вычислений | по | программе | (останов
программы) и выдачу об этом сообщения на терминал. Формат оператора STOP:

<номер строки> STOP

### 5.2. Условные операторы

Условные операторы позволяют, в зависимости от результата проверки некоторого условия, выполнить или не выполнить некоторый оператор, а также передать управление другой строке. Формат оператора следующий:

<номер строки> IF <условие> THEN <номер строки>
<номер строки> IF <условие> THEN <оператор>

Условие представляет собой логическое выражение. В случае выполнения условия, т.е., когда оно принимает истинное значение, управление передается на оператор с указанным номером строки (варианты "ТНЕN <номер строки>") или выполняется
оператор, | записанный | после | THEN | (вариант | "THEN | <оператор>"); | в | случае
невыполнения условия управление передается оператору с последующим номером строки.
Поскольку любой оператор может следовать за словом THEN, то возможно вложение условных операторов до любого требуемого уровня.
Пример:
20 IF Х>Y THEN IF Y>Z THEN PRINT "X>Y>Z"
Этот оператор эквивалентен следующему:
20 IF Х>Y AND Y>Z THEN PRINT "X>Y>Z"

### 6. ОПЕРАТОР ЦИКЛА FOR-NEXT

Циклические | программы | (участки | программ) | можно | записывать, | используя
операторы IF и GOТО. Но для упрощения процедуры составления циклов и с целью их четкого выделения в программе могут быть использованы специальные операторы FOR
и | NEXT. | Оператор | FOR, | называемый | заголовком | цикла, | всегда | предшествует
повторяющейся группе операторов, составляющих так называемое тело цикла. Формат оператора FOR:

<номер строка> FOR <имя переменной>=<выражение 1> ТО <выражение 2> [STEP <выражение 3>]

Имя переменной в операторе FOR называют управляющей переменной или параметром цикла, а <выражение 1>, <выражение 2> и <выражение 3> представляют собой начальное значение параметра цикла, конечное значение параметра цикла и шаг изменения параметра цикла соответственно. Если "STEP <выражение 3>" опущено, то шаг изменения параметра цикла полагается равным 1.
Во время выполнения оператора FOR вычисляются параметры цикла (начальное и
конечное | значения | управляющей | переменной, | величина | шага | изменения) | и
присваивается начальное значение управляющей переменной. Тело цикла начинается вслед за оператором FOR и завершается оператором NEXT, который имеет следующий формат:

<номер строки> NEXT [имя переменной]

Здесь [имя переменной] соответствует управляющей переменной в заголовке цикла. При выполнении оператора NEXT производится изменение значения управляющей переменной на величину шага и производится анализ на конец цикла. Цикл повторяется до тех пор, пока значение управляющей переменной не станет строго больше (при положительном шаге изменения) или строго меньше (при отрицательное шаге изменения) конечного значения. Можно выйти из цикла и в том случае, если параметр цикла не достигает конечного значения. Для этого используют операторы условного и безусловного перехода.

При использовании вложенных циклов (циклов в цикле) требуется, чтобы область действия внутреннего цикла полностью находилась в области действия внешнего цикла.
Операторы FOR и NEXT не могут выполняться в операторе IF.

### 7. ФУНКЦИИ

Кроме стандартных функций, предназначенных для вычисления математических выражений, в языке БЕЙСИК ПК-01 допускается употребление функций, определяемых пользователем. Если в программе необходимо несколько раз вычислить одно и то же выражение при различных значениях некоторого параметра, то целесообразно создать "свою" функцию.
Описать функцию можно с помощью определяющего оператора DEF, формат которого следующий:

<номер строки> DEF FN<переменная> (<аргумент>)=<выражение>

где FN<переменная> - имя функции, состоящее из обязательных букв FN и имени произвольной переменной.
Пример:
10 DEFFNA(X)=SIN(X)^2-COS(X)^2
Аргумент, употребляемый в описании функции (в операторе DEF), называют
формальным | параметром | функции. | Выражение, | записываемое | в | правой | части
определения | функции, | может | быть | произвольным | арифметическим | выражением,
зависящим, как правило, от формального параметра. Однако оно не обязательно должно зависеть от аргумента и может содержать также другие переменные, определенные в программе, которые не являются аргументом.
Пример:
30 DEFFNA(Х)=(X-A)*В+TAN(C/X)
Если в программе введено описание функции, то можно обращаться к нему, т.е. употреблять обозначение этой функции (иначе – указатель функции) в различных операторах, выражениях и т.п. В указателе функции все формальные параметры должны быть заменены на фактические.
Пример:
10 DEFFNA(Х)=Х^2+SIN(Х)
20 A=FNA(2.5)+2*FNA(3)
Формальный параметр вначале заменяется на 2.5, а затем на 3. Фактические параметры могут быть любыми арифметическими выражениями. При обращении к функции сначала вычисляется значение фактического параметра, далее он подставляется вместо формального параметра в описание функции, и вычисляется значение выражения, записанного в правой части определения функции. Это значение является значением указателя функции при данных фактических параметрах.
Наконец, отметим, что оператор DEF является неисполнимым оператором и поэтому может размещаться в любой части программы, например, в начале.

### 8. ПОДПРОГРАММЫ

### 8.1. Операторы GOSUB и RETURN

Последовательность повторяющихся в программе операторов может быть оформлена в виде подпрограммы. Подпрограмма на языке БЕЙСИК ПК-01 - это часть программы, которая реализует операции, выполнения которых требуется в нескольких точках программы.
Для перехода к подпрограмме используется оператор GOSUB, имеющий следующий формат:

<номер строки> GOSUB <номер строки подпрограммы>

где <номер строки подпрограммы> - номер строки подпрограммы, содержащий оператор подпрограммы, с которого начинается ее выполнение (точка входа). При выполнении оператора GOSUB управление передается в точку входа в подпрограмму.

Первая | строка | подпрограммы | может | начинаться | оператором | комментария
(оператором REM) или любым выполняемым оператором.
Подпрограмма обрабатывается интерпретатором до тех пор, пока не встретится оператор RETURN, формат которого следующий:

<номер строки> RETURN

Оператор RETURN обуславливает возврат управления на оператор, следующий за оператором GOSUB.
БЕЙСИК | ПК-01 | допускает | использование | в | одной | программе | нескольких
подпрограмм. Подпрограммы могут быть вложенными, то есть одна подпрограмма может
осуществить | вызов | другой | подпрограммы. | Если | при | выполнении | подпрограммы
встречается оператор RETURN, то он вызывает передачу управления тому оператору,
который | следует | после | операторе | GOSUB, | произведшего | обращение | к | этой
подпрограмме (в точку возврата).
Программа может содержать несколько точек входа, кроме того, подпрограмма может иметь более одного оператора RETURN, причем, как только встречается первый из них, осуществляется выход из подпрограммы.

### 8.2. Оператор ON - GOSUB

Оператор ON - GOSUB используется (аналогично оператору ON - GOTO) для условной передачи управления одной из нескольких подпрограмм или к одной из нескольких входных точек одной (или нескольких) подпрограмм. Формат оператора:

<номер строки> ON <арифметическое выражение> GOSUB <список номеров строк подпрограммы>

Во время выполнения оператора ON - GOSUB вычисляется значение арифметического выражения (N), целая часть которого используется в качестве указателя на один из
перечисленных | номеров | строк | в | списке. | В | результате | происходит | передача
управления подпрограмме, которая начинается номером строки, находящимся в списке на N-ом месте. Оператор RETURN возвращает управление оператору, следующему за оператором ON - GOSUB.

### 9. СРЕДСТВА МАШИННОЙ ГРАФИКИ И УПРАВЛЕНИЯ ЗВУКОМ

### 9.1. Формирование изображения на экране терминала

Используя средства машинной графики языка БЕЙСИК версии 2.0 ПK-01, на экране
терминала | можно | создавать | произвольные | цветные | графические | изображения,
элементами которых являются точки, линии и прямоугольники. Выводимое на экран изображение обрамлено рамкой (окантовкой), которая, как правило, включает часть телевизионной развертки со значительными нелинейными искажениями. Внутри этой рамки находится поле изображения размеров 200х222 элемента (пикселя).
После очистки экрана это поле окрашено в цвет фона. Элементы изображения выводятся одним из трех цветов переднего плана из палитры 8 цветов.
Очистка экрана, т.е. закрашивание всех пикселей поля изображения в цвет фона, осуществляется оператором CLS. Его формат:

<номер строки> CLS

Задание конкретного цвета переднего плана, цвета фона и необходимой палитры цветов осуществляется оператором COLOR. Формат этого оператора:

<номер строки> COLOR [<цвет>] [,<фон>] [,<палитра>]

где <цвет> - номер цвета переднего плана. Параметр должен принимать значения от 0 до 3 (значение 0 задает цвет фона). Этот параметр задает цвет, которым будет выводиться текстовая информация, а также графическая информация, если в графических операторах цвет переднего плана не был установлен;

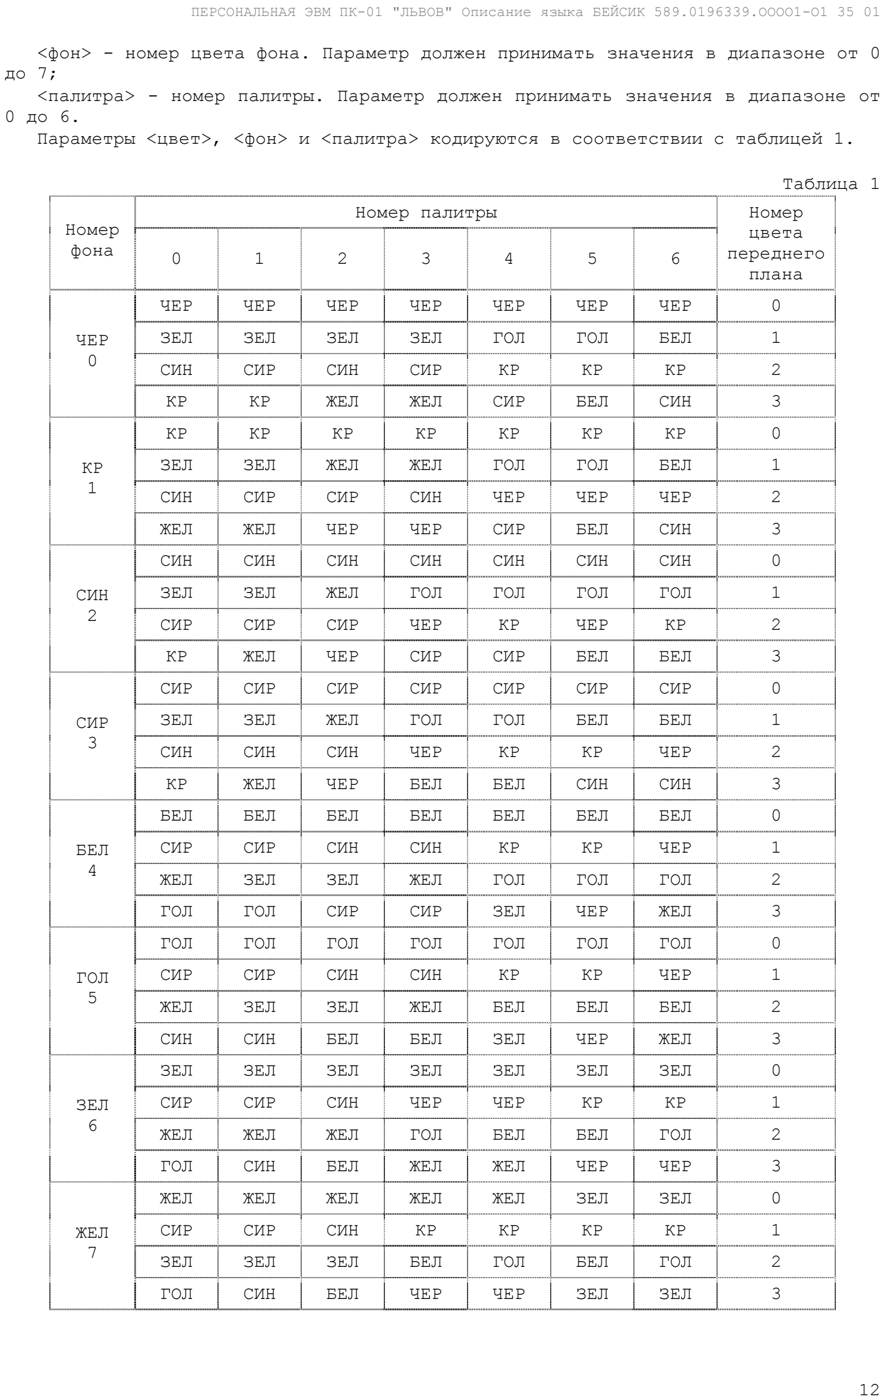
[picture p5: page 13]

<фон> - номер цвета фона. Параметр должен принимать значения в диапазоне от 0 до 7;
<палитра> - номер палитры. Параметр должен принимать значения в диапазоне от 0 до 6.
Параметры <цвет>, <фон> и <палитра> кодируются в соответствии с таблицей 1.

Таблица 1
Номер палитры
Номер
фона | 0 | 1 | 2 | 3 | 4 | 5 | 6

Номер
цвета
переднего
плана
ЧЕР | ЧЕР | ЧЕР | ЧЕР | ЧЕР | ЧЕР | ЧЕР | 0
ЗЕЛ | ЗЕЛ | ЗЕЛ | ЗЕЛ | ГОЛ | ГОЛ | БЕЛ | 1
СИН | СИР | СИН | СИР | КР | КР | КР | 2

ЧЕР
0
КР | КР | ЖЕЛ | ЖЕЛ | СИР | БЕЛ | СИН | 3
КР | КР | КР | КР | КР | КР | КР | 0
ЗЕЛ | ЗЕЛ | ЖЕЛ | ЖЕЛ | ГОЛ | ГОЛ | БЕЛ | 1
СИН | СИР | СИР | СИН | ЧЕР | ЧЕР | ЧЕР | 2

КР
1
ЖЕЛ | ЖЕЛ | ЧЕР | ЧЕР | СИР | БЕЛ | СИН | 3
СИН | СИН | СИН | СИН | СИН | СИН | СИН | 0
ЗЕЛ | ЗЕЛ | ЖЕЛ | ГОЛ | ГОЛ | ГОЛ | ГОЛ | 1
СИР | СИР | СИР | ЧЕР | КР | ЧЕР | КР | 2

СИН
2
КР | ЖЕЛ | ЧЕР | СИР | СИР | БЕЛ | БЕЛ | 3
СИР | СИР | СИР | СИР | СИР | СИР | СИР | 0
ЗЕЛ | ЗЕЛ | ЖЕЛ | ГОЛ | ГОЛ | БЕЛ | БЕЛ | 1
СИН | СИН | СИН | ЧЕР | КР | КР | ЧЕР | 2

СИР
3
КР | ЖЕЛ | ЧЕР | БЕЛ | БЕЛ | СИН | СИН | 3
БЕЛ | БЕЛ | БЕЛ | БЕЛ | БЕЛ | БЕЛ | БЕЛ | 0
СИР | СИР | СИН | СИН | КР | КР | ЧЕР | 1
ЖЕЛ | ЗЕЛ | ЗЕЛ | ЖЕЛ | ГОЛ | ГОЛ | ГОЛ | 2

БЕЛ
4
ГОЛ | ГОЛ | СИР | СИР | ЗЕЛ | ЧЕР | ЖЕЛ | 3
ГОЛ | ГОЛ | ГОЛ | ГОЛ | ГОЛ | ГОЛ | ГОЛ | 0
СИР | СИР | СИН | СИН | КР | КР | ЧЕР | 1
ЖЕЛ | ЗЕЛ | ЗЕЛ | ЖЕЛ | БЕЛ | БЕЛ | БЕЛ | 2

ГОЛ
5
СИН | СИН | БЕЛ | БЕЛ | ЗЕЛ | ЧЕР | ЖЕЛ | 3
ЗЕЛ | ЗЕЛ | ЗЕЛ | ЗЕЛ | ЗЕЛ | ЗЕЛ | ЗЕЛ | 0
СИР | СИР | СИН | ЧЕР | ЧЕР | КР | КР | 1
ЖЕЛ | ЖЕЛ | ЖЕЛ | ГОЛ | БЕЛ | БЕЛ | ГОЛ | 2

ЗЕЛ
6
ГОЛ | СИН | БЕЛ | ЖЕЛ | ЖЕЛ | ЧЕР | ЧЕР | 3
ЖЕЛ | ЖЕЛ | ЖЕЛ | ЖЕЛ | ЖЕЛ | ЗЕЛ | ЗЕЛ | 0
СИР | СИР | СИН | КР | КР | КР | КР | 1
ЗЕЛ | ЗЕЛ | ЗЕЛ | БЕЛ | ГОЛ | БЕЛ | ГОЛ | 2

ЖЕЛ
7
ГОЛ | СИН | БЕЛ | ЧЕР | ЧЕР | ЗЕЛ | ЗЕЛ | 3

Примечания:
1. Для фона номер 7 и палитр 5 и 6 фон будет зеленого цвета.
2. Цвет окантовки назначается по умолчанию для каждой конкретной комбинации цвета фона и номера палитры и соответствует второму номеру цвета переднего плана.
3. В таблице применяются такие сокращения:
ЧЕР - черный
БЕЛ - белый
КР - красный
ГОЛ - голубой
СИН - синий
ЗЕЛ - зеленый
СИР - сиреневый
ЖЕЛ - желтый

Все параметры должны быть выражениями числового типа, если значение выражения нецелое, то используется только целая часть значения. Неуказанные параметры по умолчанию принимают ранее заданные значения. Если значения параметров выходят за указанные пределы, то для задания параметров используются младшие разряды их двоичных представлений.
Цвет окантовки экрана соответствует второму номеру цвета переднего плана. Примеры:
10 COLOR1,0,0 - устанавливает зеленый цвет переднего плана для вывода текстовой и графической информация, черный цвет фона и синий цвет окантовки.
50 COLOR3,2,4 - задает сиреневый цвет переднего плана, синий цвет фона и красный цвет окантовки.
95 COLOR1 - меняет только номер цвета переднего плана фона, цвет фона и номер палитры остаются прежними.

### 9.2. Графические операторы

Графические операторы языка БЕЙСИК-2.0 ПК-01 включают операторы PSET, PRESET, LINE. При выводе изображений с помощью этих операторов адреса пикселей задаются координатами Х и Y. Пиксель, находящийся в левом верхнем углу поля изображения, имеет координаты (0, 0), в левом нижнем углу координаты (0, 221), в правом верхнем углу координаты (199, 0) и т.д.
Оператор PSET позволяет вывести точку определенного цвета в заданную точку экрана. Формат оператора:

<номер строки> PSET (<X - координата>, <Y - координата>) [,<цвет>]

где <X - координата> и <Y - координата> - соответственно координата X и координата Y выводимой точки;
<цвет> - номер цвета переднего плана, который в совокупности с ранее определенными номером фона и номером палитры определяет цвет выводимой точки. Все параметры - это выражения числового типа. Если параметр <цвет> опущен, то
принимается | значение, | заданное | оператором | COLOR | или | заданное | одним | из
графических операторов, выполненных раньше.
Примеры:
100 PSET(50,100),1
250 PSET(X,Y+1)

Оператор PRESET закрашивает заданную точку экрана в цвет фона, т.е. стирает точку. Формат оператора:

<номер строки> PRESET (<Х – координата>, <Y - координата>)

Назначение и формат параметров <Х - координата> , <Y - координата> такое же, как и у оператора PSET.

Оператор LINE дает возможность выводить на экран отрезки прямых линий. С его помощью можно чертить и закрашивать прямоугольники, стороны которых параллельны сторонам рамки экрана. Формат оператора:

<номер строки> LINE [(<Х - нач>, <Y - нач>)] - (<X - кон>, <Y - кон>) [,<цвет>] [,B][F]

где <Х - нач>, <Y - нач> - соответственно координата Х и координата Y начала отрезка;
<Х - кон>, <Y - кон> - соответственно координата Х и координата Y конца отрезка;
<цвет> - номер цвета переднего плана, которым чертится линия,
B - необязательный параметр, позволяющий вывести на экран не отрезок прямой линии, а прямоугольник, стороны которого параллельны сторонам окантовки экрана, а координаты крайних точек любой из диагоналей равны <Х - нач>, <Y - нач> и <Х -кон>, <Y - кон>.
F | - | необязательный | параметр, | предписывающий | вывод | закрашенного
прямоугольника.
Формат параметров <Х - нач>, <Y - нач>, <X - кон>, <Y - кон> и цвета такой же, как и в операторе PSET.
Если параметр (<X - нач>, <Y - нач>) опущен, то в качестве координат
начальной | точки | берутся | координаты | последней, | выведенной | предыдущими
графическими операторами, точки.
Примеры:
100 LINE(10,10)-(30,30),3
110 LINE-(10,30)
200 LINE(50,10)-(70,20),,В
210 LINE(X1,Y1)-(X2,Y2),2,ВF

Если понадобится какая-либо обработка графического изображения, то номер цвета конкретной точки можно узнать при помощи функции POINT. Формат функции:

POINT (<Х - координата>, <Y - координата>)

Здесь параметры <Х - координата> и <Y - координата> имеют то же назначение и формат, что и в операторах описанных выше.
Для | обеспечения | преемственности | с | ранее | написанными | программами, | в
интерпретатор БЕЙСИК 2.0 ПК-01 включены также операторы PLOT и DRAW предыдущей версии интерпретатора. Для этих операторов точка начала координат расположена в левом нижнем углу и расположение осей координат соответствует первому квадранту декартовой системы координат.
Оператор PLOT позволяет вывести точку определенного цвета в заданную точку экрана. Формат оператора:

<номер строки> PLOT <X - координата>, <Y - координата>, <цвет>

Назначение и формат параметров оператора PLOT такой же, как и у оператора PSET.
Оператор DRAW позволяет вывести на экран отрезок прямой линии, который соединяет последний, выведенный предыдущим оператором PLOT или DRAW, пиксель и точку с координатами Х и Y, заданными в данном операторе. Цвет пикселей этого отрезка такой же, как и у пикселя, являющегося началом отрезка. Формат оператора:

<номер строки> DRAW <X - координата>, <Y - координата>

Операторы PLOT и DRAW не рекомендуется применять при разработке новых программ, так как из последующих версий они будут исключены.

### 9.3. Средства управления звуком

Средства воспроизведения звука включают операторы ВЕЕР и SOUND.
Оператор ВЕЕР позволяет выдать короткий звуковой сигнал из динамика или капсуля. Формат оператора:

<номер отроки> ВЕЕР

Оператор | SOUND | позволяет | воспроизвести | при | помощи | динамика | (капсуля)
несложную мелодию. Формат оператора для воспроизводства отдельного звука:

<номер строки> SOUND <код частоты>, <код длительности>

Формат для последовательности звуков:

<номер строки> SOUND <код частоты>, <код длительности>; ... ; <код частоты>, <код длительности>

где <код частоты> и <код длительности> - числовые выражения. Коды частоты для нот гармонического звукоряда приведены в таблице 2.
Длительность одной единицы значения параметра <код длительности> равна приблизительно 7 мс. Если код частоты равен 0, то задается пауза.
Пример: В ниже приведенных операторах закодированы первые два такта мелодии популярной детской песни "Пусть всегда будет солнце".

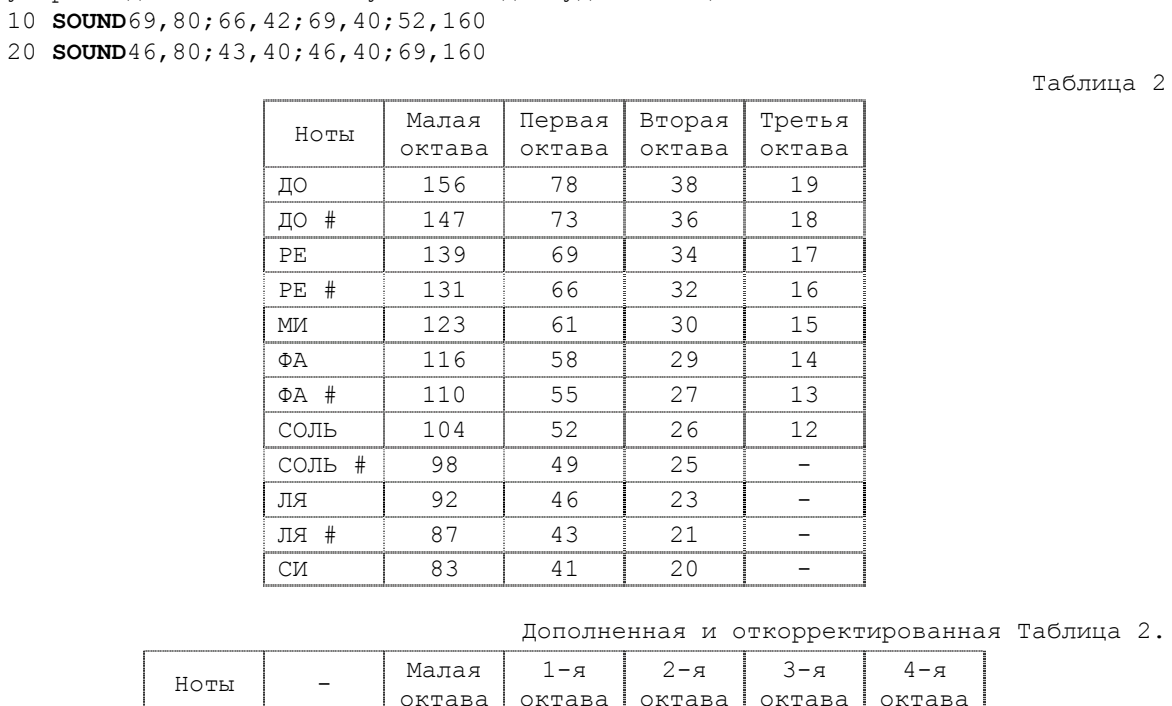
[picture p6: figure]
10 SOUND69,80;66,42;69,40;52,160 20 SOUND46,80;43,40;46,40;69,160; Таблица 2; Ноты; Малая; октава; Первая октава; Вторая октава; Третья октава; СОЛЬ; СОЛЬ #; Дополненная и откорректированная Таблица 2.
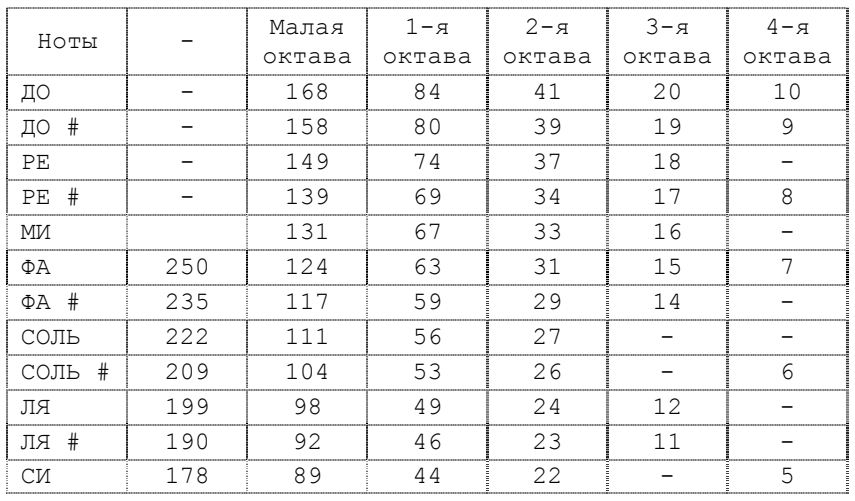
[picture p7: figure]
октава; СОЛЬ; СОЛЬ #

### 10. СРЕДСТВА РАБОТЫ НА УРОВНЕ МАШИННЫХ КОМАНД

Для квалифицированных пользователей, знакомых с программированием в кодах микропроцессора К580ИК80, в состав интерпретатора включены средства, позволяющие из БЕЙСИК-программы вызывать подпрограммы, составленные в кодах машины, читать и записывать информацию в конкретные ячейки памяти. К этим средствам относятся операторы POKE, VPOKE, OUT, WAIT и функции PEEK; VPEEK, INP, USR и VARPTR. Оператор POKE помещает указанное значение в указанную ячейку памяти. Формат оператора:

<номер строки> POKE <адрес памяти>, <значение>

где <адрес памяти> - это арифметическое выражение, целая часть которого определяет адрес ячейки памяти, в которую производится запись;
<значение> - арифметическое выражение в диапазоне от 0 до
255, целая часть которого записывается в указанную ячейку.
Пример:
10 POKE12247,35

Функция PEEK читает 1 байт из указанной ячейки памяти. Формат функции:

PEEK (<адрес памяти>)

где <адрес памяти> - это арифметическое выражение, целая часть которого определяет адрес ячейки памяти, из которой производится чтение информации. Пример:
20 PRINT PEEK(12247)

Функция USR вызывает подпрограмму, написанную в кодах машины. Адрес точки входа в программу в кодах машины должен быть перед использованием функции USR помещен в фиксированные ячейки памяти. В ячейку с адресом 73 помещается младший байт адреса подпрограммы, в ячейку с адресом 74 - старший байт. Если выполнение подпрограммы в кодах машины завершается командой возврат (RET, RZ и т.п.), то происходит возврат в интерпретатор и возобновится выполнение БЕЙСИК-программы. Формат функции USR:

USR (фиктивный аргумент)

где фиктивный аргумент - это произвольная числовая переменная.
Функция USR возвращает значение 0.
Пример: Пусть необходимо выполнить подпрограмму в кодах машины, размещенную в памяти, начиная с адреса 12288. Число 12288 в шестнадцатеричной системе счисления представляется как 3000. Старший байт адреса равен 30 (48 в десятеричной), младший байт - 00. Вызов этой подпрограммы можно осуществить при помощи следующих операторов:
10 POKE73,00
20 POKE74,48
30 X=USR(X)

Оператор VPOKE помещает указанное значение в указанную ячейку видеопамяти. Формат оператора:

<номер строки> VPOKE <адрес>, <значение>

где <адрес> - это арифметическое выражение, целая часть которого определяет адрес ячейки видеопамяти, в которую производится запись. Значение адреса должно находиться в пределах от 0 до 16383;
<значение> - арифметическое выражение в диапазоне от 0 до 255, целая часть которого записывается в указанную ячейку и кодирует цвет 4-х рядом расположенных пикселей экрана.

Функция VPEEK читает один байт из указанной ячейки видеопамяти. Формат функции:

VPEEK (<адрес>)

Параметр <адрес> задается так же, как и в операторе VPOKE.

Функция VARPTR возвращает адрес памяти, по которому хранится значение указанной переменной. Формат функции:

VARPTR (<переменная>)

где <переменная> - идентификатор переменной.

Оператор OUT позволяет вывести байт данных на заданный порт вывода. Формат оператора:

<номер строки> OUT <порт>, <данные>

где <порт> - это адрес порта вывода, на которые выводятся данные. Параметры <порт> и <данные> - это выражение, которое должно находиться в пределах от 192 до 255.

Оператор WAIT устанавливает состояние ожидания до тех пор, пока вводимые с порта данные не достигнут определенного значения. Формат оператора:

<номер строки> WAIT <порт>, <маска AND>, [<маска XOR>]

где <порт> - см. оператор OUT;
<маска AND> и <маска XOR> - выражения, значения которых должно находиться в пределах от 0 до 255. Этот оператор вводит байт данных из указанного порта ввода. С введенными данными и параметром <маска AND> выполняется поразрядная операция "И", а с полученным результатом и параметром <маска XOR> поразрядная операция "исключающее ИЛИ" Процесс ввода и обработки байта данных повторяется до тех пор, пока полученное значение не станет нулевым.

Функция INP позволяет вводить данные с заданного порта ввода. Формат Функции:

INP (<порт>)

где <порт> см. оператор OUT.

### 11. РАБОТА В РЕЖИМЕ НЕПОСРЕДСТВЕННОГО ИСПОЛНЕНИЯ

### 11.1. Режим калькулятора

Если в операторе БЕЙСИК ПК-01 опустить номер строки, то такой оператор выполняется немедленно. Это свойство можно использовать для выполнения несложных вычислений.
Пример: Ввод с терминала строки PRINT 2.5*LOG(3.5) вызовет вывод на экран числа 3.13191
Вместо служебного слова PRINT разрешается использовать вопросительный знак (?). В режиме непосредственного исполнения можно также использовать ряд других операторов (LET, POKE, PLOT, DRAW и др.). Например, при непосредственном выполнении операторов:
Х=25
Y=SQR(X)
PRINT Y
будет напечатано: "5"

Логически не имеет смысла непосредственное исполнение операторов DIM, DATA, RESTORE, FOR, NEXT, END, REM, RETURN, STOP; недопустимо использование в режиме непосредственного использования операторов DEF, INPUT, DATA.

### 11.2. Использование режима непосредственного исполнения при отладке программ

Для облегчения отладки программ программист может разместить в программе операторы STOP. Каждый оператор STOP вызывает останов в выполнении программы, печать номера строки, на которой произошла остановка. В это время программист
может | проверить | различные | значения, | возможно, | изменить | их | в | режиме
непосредственного исполнения.
Для продолжения выполнения программы следует ввести директиву CONT (см. раздел 13).
Во время отладки, используя функцию FRE, можно определить объём свободной памяти, не занятой программой или объём свободной памяти, отведенной под размещение строковых данных. Формат функции:

FRE (<фиктивный аргумент>)

Если задан фиктивный аргумент числового типа, то выдаётся оставшееся количество байт памяти, отводящейся под программу, а если строкового, то под размещение строк.
Пример:
PRINT FRE(X)

### 12. ОПЕРАТОРЫ ВВОДА – ВЫВОДА

### 12.1. Операторы READ, DATA и RESTORE

Для ввода данных в программу используются операторы READ и DATA. Оператор DATA содержит значения, которые присваиваются переменным, записанным в операторе READ. Формат оператора DATA:

<номер строки> DATA <список значений>

Список значений может включать в себя числовые и символьные данные. Элементы данных в списке должны разделяться запятыми.
Пример:
10 DATA1,-2,63,1.5E-6
20 DATAABCDE,3.5,-26
Элементы символьных данных необходимо заключить в кавычки тогда, когда символьная строка включает запятую или пробел.
Пример:
10 DATA"АAB, CD"
В одной программе может быть один или несколько операторов DATA. Списки всех операторов рассматриваются как один блок данных. За время выполнения программы информация из блока данных извлекается для присвоения значения переменным с помощью оператора READ. Оператор READ имеет следующий формат:

<номер строки> READ <список переменных>

Список переменных представляет собой перечень имен переменных (числовых и символьных, простых и с индексом). Имена переменных в списке разделяются запятыми.
Пример:
30 READM,A,K,BK,S$,A2
Если при выполнении программы встречается оператор READ, то первой переменной списка оператора READ присваивается первое значение из блока данных, второй переменной - второе значение и т.д.

При этом интерпретатор запоминает последнее значение, присвоенное переменкой из списка операторе READ. Поэтому, когда в программе встречается ещё один оператор READ, то переменной присваивается следующее имеющееся значение из блока данных.
Если список значений в блоке данных исчерпался раньше списка переменных в операторе READ, то происходит программное прерывание, а на печать выдается сообщение об ошибке.
Если одни и те же данные необходимо использовать несколько раз, то используется оператор RESTORE (восстановить). Оператор RESTORE в программе должен размещаться перед каждым следующем считыванием данных. Формат оператора RESTORE:

<номер строки> RESTORE
<номер строки> RESTORE <номер строки 1>

После его выполнения выборка значений операторами READ начнётся повторно с самого первого значения элемента блока данных, в случае первого формата оператора RESTORE, или со значения элемента блока данных, помещенного в операторе DATA с <номером строки>, во втором случае. Оператор RESTORE можно употреблять в любой момент рабочей программы, не дожидаясь полного исчерпания блока данных.

### 12.2. Оператор INPUT

При выполнении некоторых задач исследовательского или игрового характера
возникает | необходимость | корректировать | входные | данные | по | ходу | счета | в
зависимости от получающихся результатов. Для этой цели используют оператор INPUT, формат которого следующий:

<номер строки> INPUT <список>

Список включает в себя имена переменных (численных и символьных). Выполняя оператор INPUT, компьютер делает паузу во время выполнения программы, печатает на терминале знак вопроса "?". Пользователь должен набрать на клавиатуре значения переменных, разделяя их запятыми. Количество и тип значений должны соответствовать количеству и типу переменных в списке. Для ввода набранных значений следует нажать клавишу ВК. Если вводимые символьные данные содержат запятую, то их нужно заключить в кавычки.
Выдача на терминал вопросительного знака (?), при наличии в программе нескольких операторов INPUT, не даёт возможности определить, значения каких именно переменных должен ввести пользователь. Для устранения этого недостатка используют оператор INPUT следующего формата:

<номер строки> INPUT "<сообщение>"; <список>

где <сообщение> - произвольная последовательность печатных символов. Пример:
10 INPUT"МАССА";M
При выполнении этого оператора на терминал выводится:
МАССА ?
Пользователь должен набрать значение переменной М и нажать клавишу ВК.

### 12.3. Оператор PRINT

Вывод | на | терминал | результатов | вычислений | и | пояснительных | текстов
осуществляется с помощью оператора PRINT. Формат оператора:

<номер строки> PRINT [<список>]

Элементами списка могут быть числа, переменные, выражения и символьные строки. Оператор PRINT без списка используется для перевода строки.

Длина строки терминала ПК-01 составляет 32 позиции. Эта строка разбита на 2 зоны по 16 позиций. При выводе на печатающее устройство печатная строка разбивается на соответствующее число зон по 16 позиций (5 зон при длине 80 позиций, 8 зон при длине 128 позиций и т.п.). Если за элементом из списка оператора PRINT следует запятая (,), то значение следующего элемента списка будет напечатано в первой свободной зоне данной или следующей строки.
Если за последним элементом оператора PRINT следует запятая, следующее значение которого должно выводиться на печать последующим оператором PRINT, будет печататься в следующей зоне печати. Две запятые, стоящие рядом в операторе PRINT, обуславливают пропуск зоны печати.
При необходимости более тесного размещения напечатанных значений, вместо запятой следует использовать точку с запятой (;). При наличии точки с запятой следующее значение печатается через одну позицию справа от предыдущего. Если за последним элементом оператора PRINT следует точка с запятой, следующее значение, которое должно выводиться на печать последующим оператором PRINT, будет печататься через одну позицию справа от предыдущей - на той же строке (если в строке есть место для печати).

### 12.4. Дополнительные возможности оператора PRINT

Дополнительные возможности для размещения выводимой информации могут быть получены при использовании в операторе PRINT функций ТАВ(Х) и SPC(X). Функция ТАВ(Х) вызывает перемещение курсора (указывающего позицию вывода очередных данных) к позиции с номером X. Позиции в строке нумеруются, начиная с 0. Формат функции TAB:

TAB (<выражение>)

Пример:
10 PRINT TAB(5);X;TAB(25);Y
Функция | SPC(X) | возвращает | строку | пробелов | длиной | INT(X), | которая
"вставляется" в выводимую строку. Формат функции SPC:

SPC (<выражение>)

Пример:
10 PRINT TAB(5);X;SPC(11);Y

Иногда при выводе некоторых результатов на печать возникает необходимость в уточнении положения курсора в выводимой строке. Для этого можно воспользоваться функцией POS(X), где Х - фиктивный аргумент. Эта функция возвращает позицию курсора после последнего оператора PRINT.
Пример:
10 PRINT"####";
15 P=POS(0)
Переменная P примет значение, равное 4.

Номер строки, в которой находится курсор, можно определить при помощи функции CSRLIN. Эта функция не имеет аргумента и возвращает значение текущей строки курсора в пределах от 0 до 23 (0 - для верхней строки, 23 - для нижней строки экрана).

### 12.5. Управление курсором

Для позиционирования выводимого на экран терминала текста в БЕЙСИКе 2.0 ПК-01 используется оператор LOCATE, позволяющий переместить курсор в определенное место экрана. Формат оператора LOCATE:

<номер строки> LOCАТЕ [<номер столбца>], [<номер строки>] [, <видимость>]

где <номер столбца> - указывает номер позиции в строке, в которую помещается курсор (может принимать значение от 0 до 31);
<номер строки> - указывает номер строки, в которую помещается курсор (может принимать значение от 0 до 23);
<видимость> - указывает режим вывода курсора. Значение 1 указывает, что курсор выводится, 0 - не выводится.
Если какой-либо параметр не указан, то по умолчанию принимается его предыдущее значение.

### 13. СРЕДСТВА ПОДГОТОВКИ И ОТЛАДКИ ПРОГРАММ

### 13.1. Директивы интерпретатора и средства отладки программы

Директивы интерпретатора предназначены для управления его работой. При вводе директивы, в отличие от оператора, номер строки не ставится (исключение составляют случаи отладки программы). Все директивы выполняются немедленно. Директива NEW используется перед вводом новой программы. Если в памяти находится старая программа, то она стирается. При выполнении директивы NEW инициализируется ряд системных переменных интерпретатора. Формат директивы:

NEW

Директива LIST предназначена для вывода на экран терминала текста всей длины программы, находящейся в оперативной памяти. Формат директивы:

LIST [N1] [-N2]

где N1 - номер строки с меньшим номером;
N2 - номер строки с большим номером.
При вводе директивы LIST без параметров, выдается листинг всей программы; с параметром N1 - текст от оператора с номером N1 до конца программы; а в случае указания N1 и N2 - текст программы от оператора с номером строки N1 до оператора с номером строки N2.
При выдаче на экран листинга программы возможна его приостановка, для этого необходимо нажать функциональную клавишу <F5/AS>. Повторное начатие на клавишу <F5/AS> вызывает выдачу следующей строки программы.
После этого возможно либо продолжение выдачи листинга в автоматическом режиме (путем наития на клавишу "пробел"), либо прекращение выдачи листинга и выход в режим диалога (путем нажатия функциональной клавиши <F0> - клавиши в верхнем ряду).

Директива RUN предназначена для запуска программы на выполнение. Формат директивы:

RUN [N]

где N - номер строки оператора, с которого начинается интерпретация программы. При отсутствии параметра N интерпретация начинается с оператора с наименьшим номером строки.
После запуска программы на выполнение возможна ее приостановка путем нажатия на клавишу <F5/AS>. Повторное нажатие на клавишу <F5/AS> вызывает выполнение
очередного | оператора | БЕЙСИК-программы, | т.е. | пошаговое | ее | выполнение.
Возобновление выполнения программы осуществляется путем нажатия на клавишу "пробел". После приостановки программы возможно также прекращение ее выполнения и выход в режим диалога. Такой останов осуществляется путем нажатия на функциональную клавишу F0 (в верхнем ряду клавиш).

Директива CONT предназначена для возобновления программы, остановленной при выполнении оператора STOP, оператора END или при нажатии на функциональную клавишу F0. Выполнение программы возобновляется с оператора, следующего за оператором, в котором произошел останов. Формат директивы:

CONT

Директива CLEAR предназначена для очистки всех переменных и массивов в БЕЙСИК-программе и для изменения размеров памяти, предназначенной для хранения строковых переменных. Формат директивы:

CLEAR [N]

где N - целое число, определяющее количество байт памяти, отводимое под переменные символьного типа (строковые переменные).

Для записи информации на магнитную ленту в интерпретаторе БЕЙСИК 2.0 ПК-01 используются директивы CSAVE, BSAVE, SAVE, а для ввода информации с магнитной
ленты-директивы | CLOAD, | BLOAD, | LOAD, | MERGE. | Способ | записи | информации,
использующийся | указанными | директивами, | совместим | со | способом | записи
применяющимися в персональных компьютерах серии MSX.
Директива CSAVE позволяет сохранить на магнитной ленте БЕЙСИК-программу во внутреннем представлении. Формат директивы:

CSAVE "<имя файла>"

где <имя файла> - это последовательность от одного до шести символов. Не рекомендуется в качестве имени файла использовать все пробелы (см. директиву CLOAD).

Директива CLOAD дает возможность загрузить с ленты в память ЭВМ программу, записанную при помощи директивы CSAVE. Формат директивы:

CLOAD ["<имя файла>"]

Параметр <имя файла> записывается так же, как и в директиве CSAVE.
Если <имя файла> в директиве присутствует, то поиск на ленте будет вестись до тех пор, пока не будет обнаружен файл с указанным именем. Если же параметр в директиве CLOAD отсутствует, или заданы только кавычки, или в качестве имени файла используются пробелы, то будет прочитан первый по порядку файл, записанный с помощью директивы CSAVE. Прекратить поиск файла можно путем нажатия на клавишу "стрелка вниз". Сказанное выше относится и к поиску файлов в директивах BLOAD, LOAD и MERGE за исключением того, что ведется поиск BSAVE-файлов или SAVE-файлов.

По директиве SAVE текст БЕЙСИК-программы записывается на магнитную ленту во внешнем представлении (в коде КОИ-7). Запись ведется блоками по 256 байт. Такую программу можно ввести и выполнить (если совпадут форматы операторов и функций) на других компьютерах, использующих формат записи MSX ("Корвет", "Ямаха" и др.). Формат директивы:

SAVE "<имя файла>"

Правила записи параметра <имя файла> такие же, как и в директиве CSAVE.

Директива | LOAD | предписывает | загрузить | в | память | программу, | записанную
директивой SAVE. Формат директивы:

LOAD ["[<имя файла>]"]

Директива MERGE дает возможность объединять две программы: программу в памяти с программой, вводимой с магнитной ленты, причем вторая должна быть записана на ленту директивой SAVE. Если в программе, находящейся в памяти, и в программе, вводимой с магнитной ленты, будут встречаться операторы с одинаковыми номерами строки, то они будут замещаться теми операторами, что вводятся с ленты. Формат директивы:

MERGE ["[<имя файла>]"]

Директива BSAVE позволяет записать на магнитную ленту двоичный образ памяти. Это может быть программа в машинном коде или какие-либо данные. Формат директивы:

BSAVE "<имя файла>", <нач.адрес>, <кон.адрес> [, <адрес запуска>]

где <имя файла> - см. директиву CSAVE;
<нач.адрес> и <кон.адрес> - это адреса соответственно начала и конца области памяти, которая выводится на ленту;
<адрес запуска> - точка входа в программу в машинном коде. Если этот параметр опущен, то точка запуска устанавливается равной параметру <нач.адрес>. Параметры <нач.адрес>, <кон.адрес> и <адрес запуска> должны быть числовыми выражениями.

Директива BLOAD предназначена для загрузки в память информации записанной директивой BSAVE. Формат директивы:

BLOAD "[<имя файла>]" [, R] [,<смещение>]

где <имя файла> - см. директиву CLOAD;
R - необязательный параметр указывающий, что после загрузки управление долено
быть | передано | на | пусковой | адрес | загруженной | программы | в | кодах | машины
(автозапуск). Если эта программа завершается командой возврата (RET), то управление возвращается интерпретатору;
<смещение> - необязательный параметр, который позволяет загрузить данные в область памяти, отличающуюся от той, из которой они записывались на ленту. Значение параметра <смещение> прибавляется (по модулю 2^16) к адресам начала и конца области данных, которые были заданы в директиве BSAVE и сохранены на ленте вместе с данными.
Директивы BSAVE и BLOAD, так же, как и директива RUN, могут использоваться в качестве операторов.

Для загрузки с ленты БЕЙСИК - программы, созданной в предыдущей версии интерпретатора предусмотрена директива SLOAD. Ее формат:

SLOAD

### 13.2. Диагностические сообщения интерпретатора

В состав интерпретатора включена система контроля, позволяющая выявить большинство ошибок, связанных с недопустимым использованием конструкций БЕЙСИКА. При обнаружении ошибки интерпретатор выдает диагностическое сообщение, которое в случае интерпретации директивы и в режиме непосредственного исполнения содержит код ошибки, а при выполнении БЕЙСИК-программы содержит код ошибки и номер строки оператора, в котором произошла ошибка. Коды ошибок, выдаваемых интерпретатором, приведены в таблице 3.

Таблица 3
Код
ошибки | Значение | Пояснение
NF | NEXT без FOR | Программа не содержит соответствующего FOR для
| | NEXT.
SN | Синтаксис | Неправильное использование ограничителей, символов
| | и т.д.
RG | RETURN без GOSUB | Оператор RETURN встретился прежде, чем был
| | использован оператор GOSUB.
OD | Выход за пределы
| DATA | В программе исчерпаны все элементы списка DATA, а
| | оператор READ пытается еще прочитать данные.
FC | Недопустимый
| вызов | Параметры, передаваемые функции, не соответствуют
| | их пределам. Возможные причины:
1. Отрицательный индекс в элементе массива.
2. А^В, где A - отрицательное, а B не является
| | целым.
3. Недопустимый аргумент при обращении к функциям
| | LOG, SQR, MID$, LEFT$, RIGHT$, TAB, SPC.
4. Недопустимые аргументы операторов POKE, PLOT,
| | DRAW, ON.
OV | Переполнение | Значение выражения превышает 1,7.10^38
OM | Превышение памяти | Программа слишком большая, содержит очень много
| | циклов, подпрограмм, переменных или сложных
| | выражений.
US | Неопределенный
| номер | Не существует строки, указанной в ссылке.
BS | Превышение границ | Обращение к переменной с индексами, которая вне
| | описанной размерности массива, или в операторе ON
| | выход за пределы списка меток, или неправильное
| | число размерностей в переменной с индексами.
DD | Повторное
| определение | Повторное описание массива.
/0 | Деление на 0 | Была предпринята попытка деления на 0.
ID | Недопустимое
| непосредственное
| исполнение | В режиме непосредственного исполнения оператор
| | использован неправильно.
TM | Смешивание типов | Для функции был задан неправильный тип данных;
| | любое неправильное смешивание типов данных.
OS | Превышение памяти
| для строк | Для переменных символьного типа требуется больше
| | памяти, чем назначено. Можно увеличить память с
| | помощью директивы CLEAR.
LS | Недопустимая
| длина строки | Длина строки больше 255 символов.
ST | Сложная строка | Строка очень длинная или сложная; ее следует
| | разделить на две части.
CN | Не может быть
| CONT | Была произведена попытка продолжить программу,
| | которая не допускает продолжения (ни после
| | останова по STOP, ни после останова по END, ни
| | после останова по функциональной клавиши F0, или
| | при отсутствии следующих операторов программы).
VF | Неопределенная
| функция
| пользователя | Ссылка на неопределенную функцию пользователя.

### 13.3. Средства редактирования

Средства редактирования интерпретатора позволяют модифицировать программу, исправлять ошибки, допущенные при наборе программы.
Если при выводе строки последний набранный символ неверный, то его можно уничтожить путем нажатия на клавишу ЗБ; для уничтожения двух последних символов необходимо дважды нажать на клавишу ЗБ и т.д.

Для уничтожения всей набранной строки необходимо нажать на функциональную клавишу <F5/AS>
Указанными средствами можно пользоваться до окончания ввода строки, т.е. до нажатия на клавишу ВК.
С целью облегчения ввода наиболее часто встречающихся ключевых слов БЕЙСИКа в интерпретаторе версии 2.0 предусмотрено использование некоторых функциональных клавиш, специальных клавиш и комбинации клавиш СУ и алфавитно-цифровых клавиш. Так, нажатие функциональной клавиши <F1/ЧМЛ> вызывает ввод ключевого слова CLOAD, функциональной клавиши <F2/ЗМЛ> - CSAVE; функциональной клавиши <F3/BS> -LIST; функциональной клавиши <F4/ED> - EDIT; путем нажатая на клавишу TAB инициируем ввод символов TAB (, а нажатием на клавишу ПС - ввод директивы RUN и символа ВК, т.е. запуск программы на выполнение. Одновременное нажатие на клавишу СУ и одну из алфавитно-цифровых клавиш вызывает ввод еще одного из 32 ключевых слов БЕЙСИКа (см. табл. 4). Например, комбинация клавиш СУ и C дает слово COLOR, СУ и P - PRINT, СУ и L - LOCATE, СУ и Т - THEN и т.д. В ряде случаев первая буква ключевого слова и алфавитно-цифровой символ не совпадают, однако можно составить некоторые мнемонические правила: СУ и Z - SOUND (звук), СУ и Х - PSET, CУ и Y - LINE (графика, которая связана с системой координат XY) и т.д.

Таблица 4 "Ключевые слова"

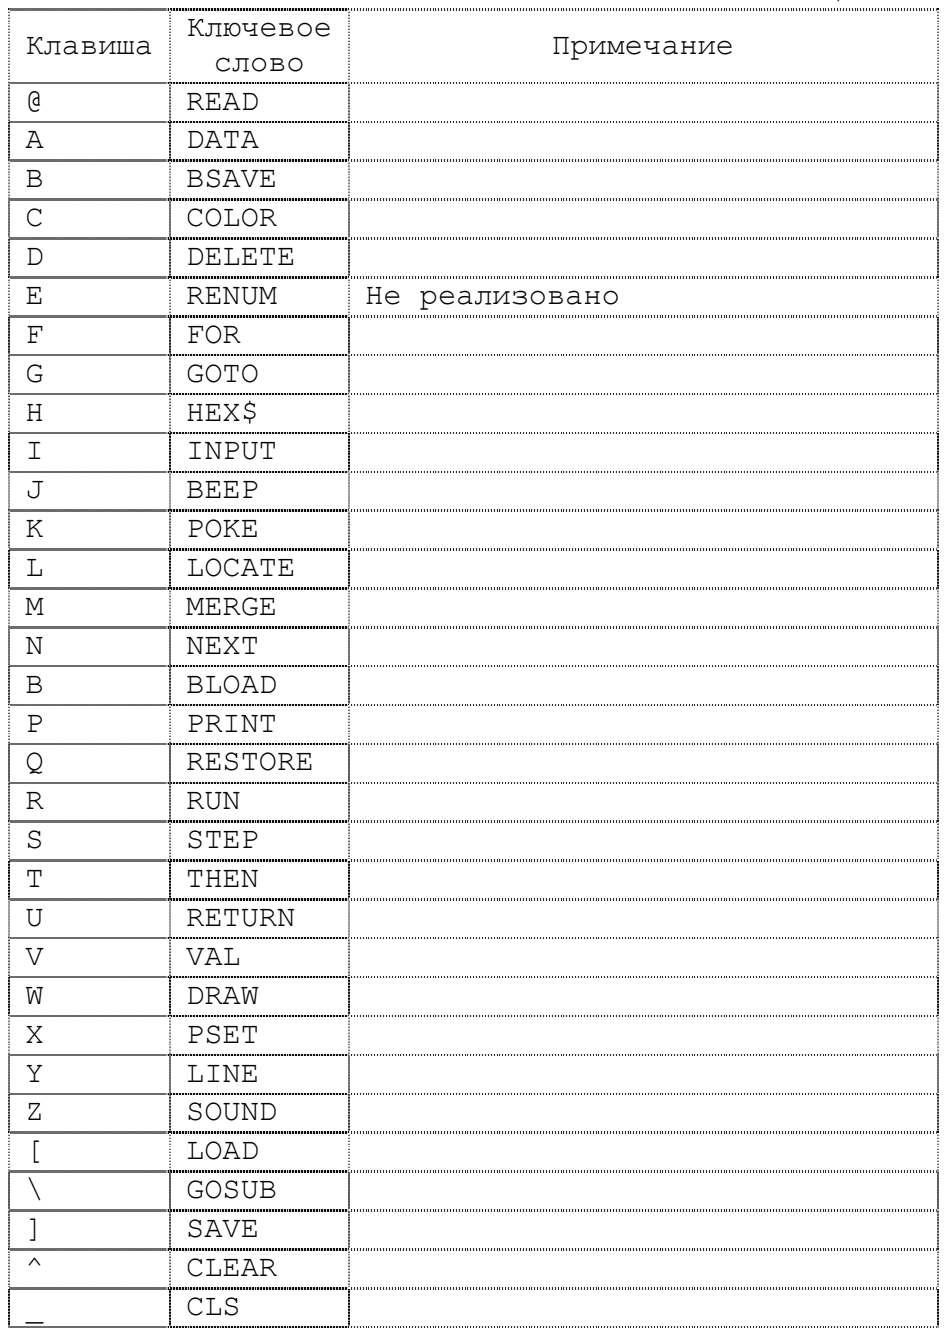
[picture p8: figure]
Клавиша Ключевое; слово; Примечание; READ; DATA; BSAVE; COLOR; DELETE; RENUM; Не реализовано; FOR; GOTO; HEX$; INPUT; ВЕЕР; POKE; LOCATE; MERGE; NEXT; BLOAD; PRINT; RESTORE; RUN; STEP; THEN; RETURN; VAL; DRAW; PSET; LINE; SOUND; LOAD; GOSUB; SAVE; CLEAR; CLS

Для корректировки (замены или исправления) ранее введенной строки необходимо набрать номер корректируемой строки и ее новое содержание, старое содержимое заменяется новым.

Более мощными средствами редактирования являются средства, предоставляемые директивной EDIT. Формат директивы:

EDIT <номер строки>

После ввода этой директивы оператор (операторы) с указанным номером строки
выводятся | в | специальный | буфер | редактирования, | содержимое | которого
"высвечивается" в нижней части экрана. При помощи клавиш управления курсором, курсор устанавливается в нужное место буфера, путем нажатия на алфавитно-цифровые клавиши осуществляется замена (исправление) текста редактируемого оператора, клавишей ГТ освобождается место для вставки, клавишей ЗБ уничтожаются ненужные символы. Выход из режима редактирования осуществляется путем нажатия на клавишу ВК; при этом курсор может находиться в произвольной части буфера.
Для удаления какой либо из ранее набранных строк, достаточно набрать номер удаляемой строки и нажать клавишу ВК, - строка с указанным номером удаляется. Для удаления группы строк программы можно использовать директиву:

DELETE <начальная строка>-<конечная строка>

где <начальная строка> и <конечная строка> - это номера строк операторов того участка программы, который подлежит удалению.

ПРИЛОЖЕНИЕ: ДОПОЛНИТЕЛЬНЫЕ ОПЕРАТОРЫ БЕЙСИКА

К дополнительным операторам БЕЙСИКа версии 2.0 относятся операторы CIRCLE, PAINT и оператор DEF USR.
В графических операторах CIRCLE, PAINT координаты точек задаются так же, как и в операторах PSET, PRESET и LINE, т.е. точка с координатами (0,0) находится в левом верхнем углу экрана.
Оператор CIRCLE позволяет выводить на экран видеотерминала окружности, овалы, сектор круга, дуги. Формат оператора:

<номер строки> CIRCLE (<Х - координата>, <Y - координата>), <радиус> [,<цвет>] [,<нач.угол>] [,<кон.угол>] [,<отношение>]

где Х - координата и Y - координата - выражения, задающие значения соответственно координаты Х и Y центра окружности;
<радиус> - значение радиуса окружности (дуги окружности);
<цвет> - номер цвета переднего плана, которым чертится окружность (дуга); <нач.угол>- начало дуги (в радианах), по умолчанию равно нулю;
<кон.угол>- конец дуги (в радианах), по умолчанию равно 2pr;
<отношение> | - | характеристический | коэффициент, | задающий | отношение
горизонтальной и вертикальной осей и позволяющий рисовать овалы, по умолчанию равен 1.
Если заданы параметры <нач.угол>, <кон.угол>, то рисуется дуга окружности. Если любой из этих параметров отрицательный, то используется его абсолютное значение, при этом соответствующий конец дуги соединяется с центром линии радиуса. Значение углов должно находиться в пределах от 0 до 6.28318.
При указании параметра <отношение> рисуется овал, у которого отношение вертикальной оси к горизонтальной равно значению параметра.
Если значение параметра меньше 1, то размер горизонтальной оси равен диаметру (двум значениям параметра <радиус>), а при значении большем 1 - вертикальная ось равна диаметру.

Оператор PAINT используется для закрашивания области экрана видеотерминала сплошным цветом. Формат оператора:

<номер строки> PAINT (<Х - координата>, <Y - координата> ), <цвет> [,<граница>]

где <Х - координата>, <Y - координата> - выражения, значения которых равны соответственно координате Х и координате Y - точки, с которой начинается закрашивание области;
<цвет> - выражение, задающее значение номера цвета закраски (если опущено, то используется цвет переднего плана, определенный ранее);
<граница> - выражение, определяющее номер цвета границы области закраски (если опущено, то номер цвета границы совпадает с номером цвета закраски). Параметр <граница> указывается в том случае, если цвет закрашивания не совпадает с цветом границы закрашиваемой области. Точка начала закраски области может быть любой точкой внутри области (но не на границе). Оператор PAINT проверяет наличие границ только по вертикали и горизонтали - и объект признается ограниченным, если ограничены вертикаль и горизонталь. Но малейшая прореха в границе позволяет оператору PAINT "пролезть" наружу и там закрасить область экрана (в том числе и всего).
Следующий пример иллюстрирует применение операторов CIRCLE и PAINT:
10 CLS
20 CIRCLE(100,100),90,1,,,3
30 CIRCLE(100,100),70,,,0.5
40 LINE(100,40)-(100,160),0
50 LINE(40,100)-(160,100)
60 PAINT(100,100),3,1

Оператор DEF USR определяет адрес точки входа в определенную пользователем подпрограмму в машинном коде. Формат оператора:

<номер строки> DEF USR = <выражение>

где <выражение> - это арифметическое выражение, определяющее адрес точки входа в подпрограмму.
Параметр <выражение> должен иметь положительное значение в диапазоне от 0 до 65535; при нецелом значении дробная часть отбрасывается, а при значении большем, чем 65535 берется остаток от деления на 65556. Полученное значение адреса (2 байта) заносится в ячейки памяти с адресом 73 или 74. Определенный оператором DEF USR адрес действителен только во время выполнения БЕЙСИК-программы (или программой строки в режиме непосредственного исполнения) и при выходе в режим диалога стирается.
Напомним, | что | запуск | подпрограммы | в | машинном | коде | на | выполнение,
осуществляется с помощью функции USR.

Тип. ЛПО им. В.И. Ленина. Зак. 2077-1500

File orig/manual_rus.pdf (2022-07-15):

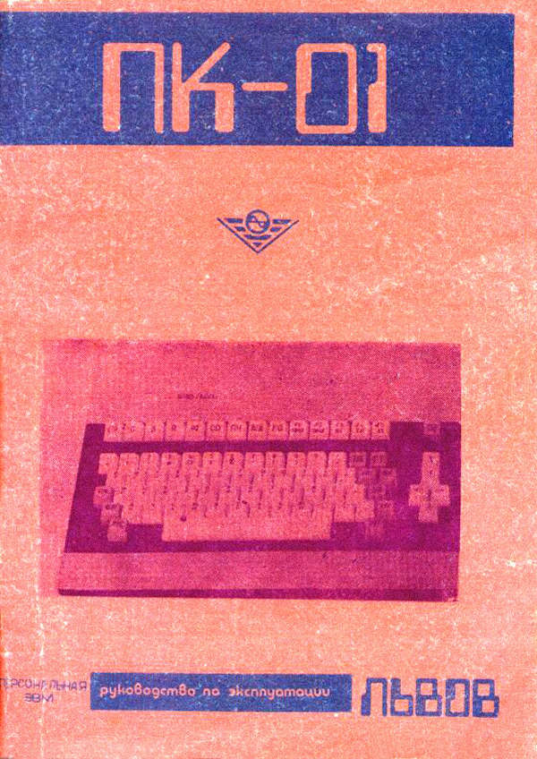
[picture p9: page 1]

## ПЕРСОНАЛЬНАЯ ЭВМ ПК-01 "Львов" Руководство по эксплуатации ЯП1.790.002 РЭ

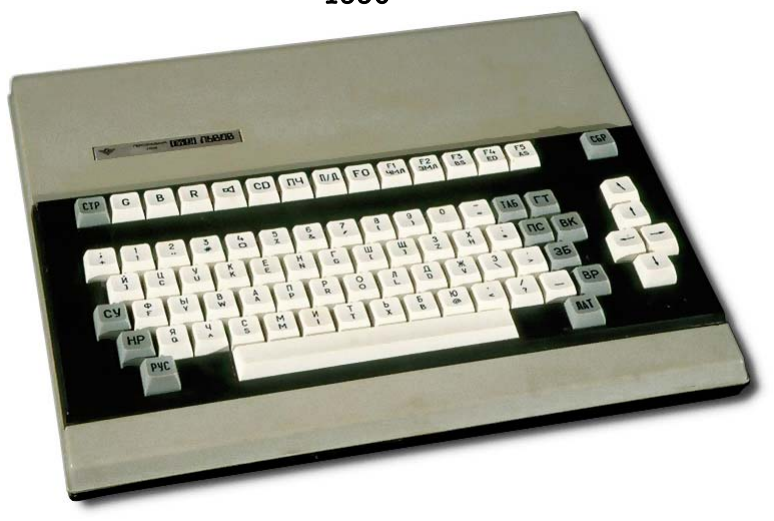
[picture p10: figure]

1990

СОДЕРЖАНИЕ
1. ОБЩИЕ УКАЗАНИЯ
2. КОМПЛЕКТ ПОСТАВКИ
3. ОСНОВНЫЕ ТЕХНИЧЕСКИЕ ХАРАКТЕРИСТИКИ
4. УКАЗАНИЯ ПО ТЕХНИКЕ БЕЗОПАСНОСТИ
5. КРАТКОЕ ОПИСАНИЕ ПЭВМ
5.1. Назначение
5.2. Конструкция
5.3. Подключение магнитофона к ПК-01 "Львов"
5.4. Подключение ПК-01 "Львов" к телевизору
5.4.1. Доработка телевизоров "Электрон 280". "Электрон 380" и их модификаций
5.5. Программное обеспечение
5.6. Функционирование ПЭВМ
6. ПОДГОТОВКА К РАБОТЕ И ПОРЯДОК РАБОТЫ С ПЭВМ
6.1. Подготовка к работе
6.1.1. Порядок установки
6.1.2. Порядок включения
6.1.3. Начальная установка
6.1.4. Проверка ввода информации с клавиатуры
6.1.5. Проверка количества символов в строке, количества строк
6.1.6. Тестирование ОЗУ, ПЗУ
6.1.7. Проверка вызова интерпретатора БЕЙСИК
6.1.8. Проверка обеспечения чтения информации с магнитофона
6.1.9. Проверка обеспечения записи информации с ПК-01 на магнитофон
6.1.10. Проверка вывода графической информации и размера поля
6.2. Порядок работы с ПЭВМ
6.2.1. Основные положения
6.2.2. Режим работы
6.2.3. Порядок работы
6.2.4. Выполнение работ по подготовке, вводу и выполнению программ на языке БЕЙСИК
6.2.5. Работа ПЭВМ в режиме калькулятора
6.2.6. Работа с устройствами пользователя
6.3. Порядок выключения ПЭВМ
7. ТЕХНИЧЕСКОЕ ОБСЛУЖИВАНИЕ ПЭВМ
7.1. Перечень и содержание работ по техническому обслуживанию
7.2. Периодичность и порядок работ по техническому обслуживанию
7.3. Порядок замены предохранителей
7.4. Возможные неисправности и методы их устранения
8. ГАРАНТИЙНЫЕ ОБЯЗАТЕЛЬСТВА
9. ГАРАНТИЙНЫЙ ТАЛОН
10. ОТРЫВНОЙ ТАЛОН
ПРИЛОЖЕНИЕ 1. Перечень применяемых в тексте сокращений, условных обозначений, терминов и определений
ПРИЛОЖЕНИЕ 2. Адреса ремонтных предприятий
ПРИЛОЖЕНИЕ 3. Схемы электрические принципиальные
ПРИЛОЖЕНИЕ 4. Электромонтажные чертежи печатных плат

1. ОБЩИЕ УКАЗАНИЯ
При покупке персональной ЭВМ ПК-01 "Львов" (далее по тексту ПЭВМ) требуйте проверки ее работоспособности совместно с бытовым магнитофоном и телевизором согласно разделу 6.1 настоящей инструкции.
Проверьте комплектность ПЭВМ и сохранность пломб (на системном блоке и блоке питания (БП)). Убедитесь в наличии гарантийного и отрывного талонов в руководстве по эксплуатации и простановки на талонах разборчивой подписи, даты продали и штампа магазина. Помните, что при утрате гарантийного талона и нарушения пломб Вы лишаетесь права на гарантийный ремонт. Устранение неисправностей в ПЭВМ производится только специалистами ремонтных организаций (см. приложение 2).
Отрывной талон (талоны) на гарантийный ремонт отрезается работниками обслуживающей организации только после фактического выполнения работ.
Прежде, чем приступить к установке ПЭВМ на рабочее место и включению ПЭВМ в сеть, необходимо ознакомиться с настоящим руководством по эксплуатации (РЭ), органами включения, клавиатурой и надписями на ней, схемой соединения с бытовым магнитофоном и телевизором.
После хранения ПЭВМ в холодном помещении или ее перевозки в зимних условиях необходимо перед включением в сеть дать ей прогреться при комнатной температуре в течение 2-3 часов.
ПЭВМ эксплуатируется в помещениях при температуре воздуха от 5°С до 40°С, относительной влажности воздуха от 40 % до 80 % при температуре 25°С, атмосферном давлении от 630 мм рт.ст. до 800 мм рт.ст.
2. КОМПЛЕКТ ПОСТАВКИ
В комплект поставки ПЭВМ входят:
1. Системный блок | 1 шт.
2. Блок питания | 1 шт.
3. Кабель для подключения телевизора | 1 шт.
4. Кабель для подключения магнитофона | 1 шт.
5. Кассета МК-60-2 (МК-60-5) с программами: | 1 шт.
- тестовой;
- учебной;
- игровой.
6. Персональная ЭВМ ПК-01 "Львов"
Руководство по эксплуатации ЯП1.790.002 РЭ | 1 шт.
7. Персональная ЭВМ ПК-01 "Львов" Описание языка БЕЙСИК
589.0196339.OOOO1-O1 35 01 | 1 шт.
8. Комплект запасных частей:
- вставка плавкая ВП1-1 1A 250 В | 2 шт.
- вилка ЯПЗ.645.057 | 1 шт.
- вилка ЯПЗ.645.058 | 1 шт.
- лампа СMH9-60 | 4 шт.
- переключатель ПКН41-1-2 | 1 шт.
- соединитель ОНЦ-ВГ-11-7/16-Р | 1 шт.
9. Упаковочная тара:
- коробка верхняя | 1 шт.
- коробка нижняя | 1 шт.

3. ОСНОВНЫЕ ТЕХНИЧЕСКИЕ ХАРАКТЕРИСТИКИ
Элементная база | микросхемы серий KP155 КР580 в др.
Объем памяти, кБайт | 80
в том числе 03У, кБайт | 64
видеопамять, кБайт | 16
ПЗУ. КБайт | 16
Быстродействие тыс.oп./с типа "регистр-регистр" | 500
Максимальное количество символов в строке на экране телевизора | 32
Максимальное количество информационных строк | 24
Количество программно-адресуемых точек 256х256
Количество цветов одновременно отображаемых на экране | 4
Количество цветов палитр | 7
Количество цветов фона | 8
Программное обеспечение:
встроенное | БЕЙСИК
на кассете | три программы
Потребляемая мощность, Вт | не более 30
Габаритные размеры, мм.
системного блока | 338х268х65
блок питания | 200х157х94
Масса, кг, не более
системного блока | 1,9
блока питания | 3,0

Питание осуществляется от сети переменного тока напряжением 220 В частотой 50 Гц.

Содержание цветных металлов:
алюминий и его сплавы | 0,026633 кг
медь и ее сплавы | 0,04549 кг
Содержание драгоценных металлов:
золота | 2,059583 г
серебра | 1,1855 г
палладия | 0,00000589 г

4. УКАЗАНИЯ ПО ТЕХНИКЕ БЕЗОПАСНОСТИ ПЭВМ устанавливается в месте, удобном для работы, на расстоянии не менее 1 м от отопительной системы.
Запрещается устанавливать ПЭВМ в сырых помещениях, закрывать вентиляционные отверстия блока питания и системного блока, использование других источников питания, кроме блока питания, входящего в комплект поставки.
Во избежание несчастных случаев и выхода из строя ПЭВМ запрещается:
включать в сеть блок питания со снятой крышкой;
производить замену предохранителя при включенном в сеть шнуре;
применять самодельные предохранители;
оставлять ПЭВМ во включенном состоянии без наблюдения.
При длительных перерывах в работе ПЭВМ рекомендуется вынимать вилку шнура питания из розетки электросети.
Для соблюдения мер пожарной безопасности запрещается установка ПЭВМ вблизи нагревательных приборов или других нагревательных систем, способных вызвать возгорание пластмассового корпуса ПЭВМ.
5. КРАТКОЕ ОПИСАНИЕ ПЭВМ
5.1. Назначение
Персональная ЭВМ ПК-01 "Львов" соответствует требованиям ГОСТ 21552-84 и техническим условиям ЯП1.790.002 ТУ и предназначена для индивидуального пользования в домашних условиях с целью:
- обучения программированию на алгоритмическом или машиноориентированном языках;
- выполнения научно-технических расчетов малой и средней сложности, решения вычислительных задач в режиме программируемого калькулятора;
- использования различных обучающих программ для самостоятельного изучения;
- организации досуга с помощью игровых программ и других применений, определяемых пользователем.
ПЭВМ может использоваться для создания индивидуальных информационно-поисковых и советующих систем типа каталогов фонотеки и библиотеки, хранения рецептов ведения домашнего хозяйства, организации семейного бюджета и личного времени, то есть персонального банка данных, формируемого пользователем и хранящегося на магнитофонных кассетах.
5.2. Конструкция
ПЭВМ состоит из системного блока с встроенной клавиатурой, автономного блока питания и комплекта соединительных кабелей.
Системный блок выполнен в малогабаритном корпусе, состоящем из двух пластмассовых полукрышек, соединенных между собой винтами. На верхней крышке расположена клавиатура. На нижней крышке установлены ножки-амортизаторы и откидная подставка для установки системного блока в наклонном положении.
На задней стенке системного блока расположены присоединительные разъемы.
Блок питания выполнен в пластмассовом корпусе. На задней стенке блока питания закреплен мощный транзистор на радиаторе. На корпусе расположены также кнопка включения питания, держатель предохранителя и лампа индикации включения блока питании.
Внешний вид ПЭВМ приведен на рис.1. Расположение присоединительных разъемов приведено на рис.2. Схема распайки присоединительных кабелей к магнитофону и телевизору, входящих в комплект поставки, приведена на рис.3. Распайка разъемов ВНЕШ 1 и ВНЕШ 2 приведена на рис.4.

ПЭВМ позволяет решать упомянутые выше задачи при подключении к ней бытового телевизионного приемника черно-белого или цветного изображения (ТВ) и бытового кассетного магнитофона (МАГ). Телевизионный приемник применяется для индикации вводимой с помощью клавиатуры алфавитно-цифровой или графической информации в ПЭВМ и индикации выводимой из ПЭВМ информации (алфавитно-цифровой или графической) для пользователя. Бытовой магнитофон используется для записи и считывания программ.
5.3. Подключение магнитофона к ПК-01 "Львов" Подключение магнитофона к ПЭВМ осуществляется с помощью кабеля (см. рис.3). При этом необходимо обратить внимание на правильность подключения разъемов магнитофона. Следует помнить, что при записи программы из ПЭВМ на магнитную ленту информация поступает на разъем магнитофона для подключения радиотрансляционной сети и высокочастотного устройства, при считывании программы из магнитофона в ПЭВМ информация принимается по другой линии кабеля, подключенной к линейному выходу магнитофона.
При наличии у Вас магнитофона, распайка используемых разъемов которого отличается от стандартных, Вам необходимо изменить распайку разъемов магнитофона, ориентируясь на назначение выводов по схеме рис.3 и табл.1.
5.4. Подключение ПК-01 "Львов" к телевизору Цветной телевизор предназначен для вывода алфавитно-цифровой и графической информации. Для работы с цветным телевизором ПК-01 вырабатывает сигналы строчной и кадровой синхронизации, а также сигналы R, G, B, управляющие выходными сигналами блока цветности ТВ. Обычные цветные телевизоры требуют доработки для подключения к ПК-01.
Для доработки телевизоров используют разъем видеовхода. При отсутствии видеовхода используют один из имеющихся разъемов типа ОПЦ-ВГ-11-7/16-Р, на контакты которого необходимо вывести следующие сигналы:

Примечание:

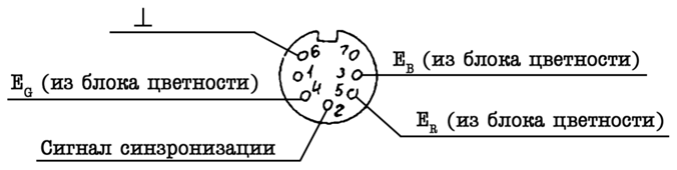
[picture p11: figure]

1. За доработку телевизора завод-изготовитель ПЭВМ ответственности не несет.
2. При выходе из строя ПК-01 в результате несоблюдения изложенных в пп. 5.3, 5.4 рекомендаций по подключению ТВ и МАГ Вы лишаетесь права на гарантийный ремонт.
При неверном считывании информации с магнитной ленты необходимо провести подстройку магнитной головки магнитофона до получения максимальной громкости считываемого сигнала
3. При необходимости доработки Вашего телевизора рекомендуется воспользоваться услугами телеателье.
4. На модуле цветности МЦ-2 телевизоров "Электрон 280", "Электрон 380" должны быть установлены резисторы R84+R86 сопротивлением 470 Ом.

5.4.1. Доработка телевизоров "Электрон 280". "Электрон 380" и их модификаций.

X6 (A2)
I | Видео
2 | Корпус

Модуль

рад

ио-

канала

МРК-2-5

X5
Цепь
| I
Сигнал синхронизации | 2

конт.

X2 (A20)
EB | 3 | I | EB внеш.
EG | 4 | 2 | EG внеш.
ER | 5 | 3 | ER внеш.
Корпус | 6 | 6 | Корпус

Модуль

цветности МЦ-2

7

8

ПК-01

При использовании телевизора "Электрон 380" в качестве цветного дисплея необходимо отключать субмодуль радиоканала, для чего заземлить вход блокировки (ХЗ/6).

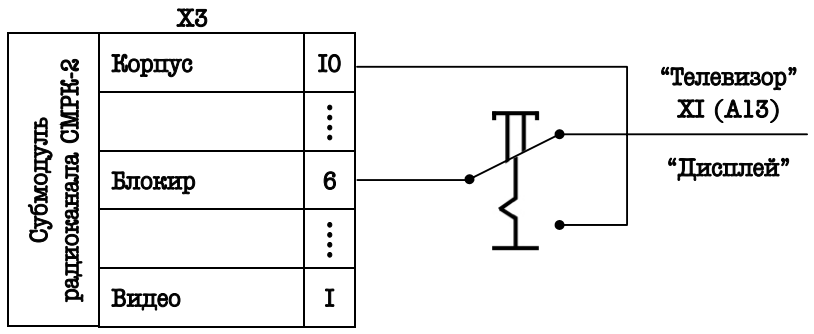
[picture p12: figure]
Корпус; “Телевизор”; Блокир; “Дисплей”; бмодуль; радиоканала СМРК-2 Видео I

Сопряжение ПК-01 с монитором МС6105

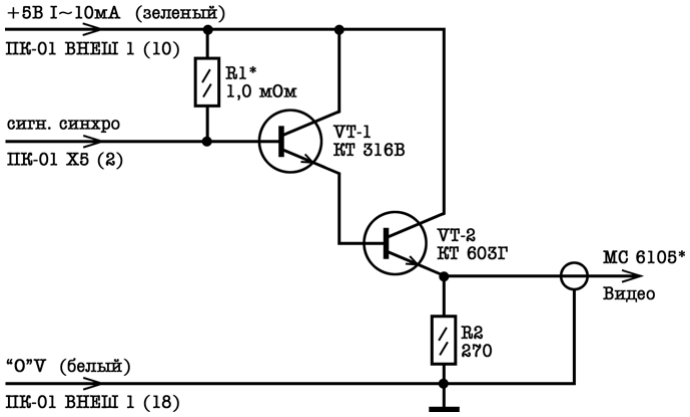
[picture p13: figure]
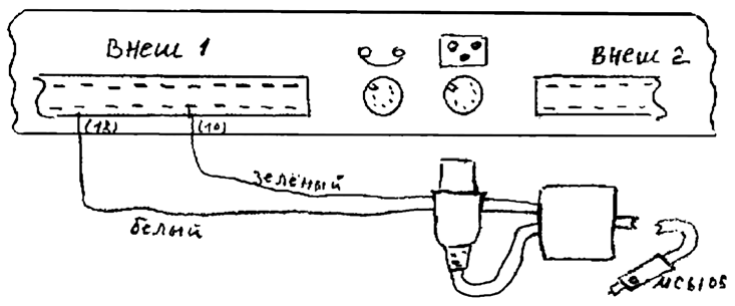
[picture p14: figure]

5.5. Программное обеспечение Программное обеспечение (ПО) ПЭВМ делится на два вида:
1) системное;
2) прикладное - БЕЙСИК-ТЕСТ - тестовая, учебная, игровая программы.
Системное ПО включает интерпретатор БЕЙСИК (в ПЗУ).
После включения ПЭВМ и нажатия клавиши СБР осуществляется вызов интерпретатора языка БЕЙСИК.
Прикладное программное обеспечение включает файлы данных и программные файлы, подготовленные на БЕЙСИКе. Указанные файлы могут быть записаны и введены с помощью магнитофона посредством директив интерпретатора БЕЙСИК.
5.6. Функционирование ПЭВМ Персональная ЭВМ выполняет программы, написанные на языке высокого уровня. Для изучения
языка | предлагаем | Вам | ознакомиться | с | "Описанием | языка | БЕЙСИК | ПК-01 | "Львов"
589.0196339.003001-01 35 01" (далее по тексту "Описание языка БЕЙСИК").
Перечень принятых в тексте сокращений, условных обозначений и определений приведен в приложении 1.

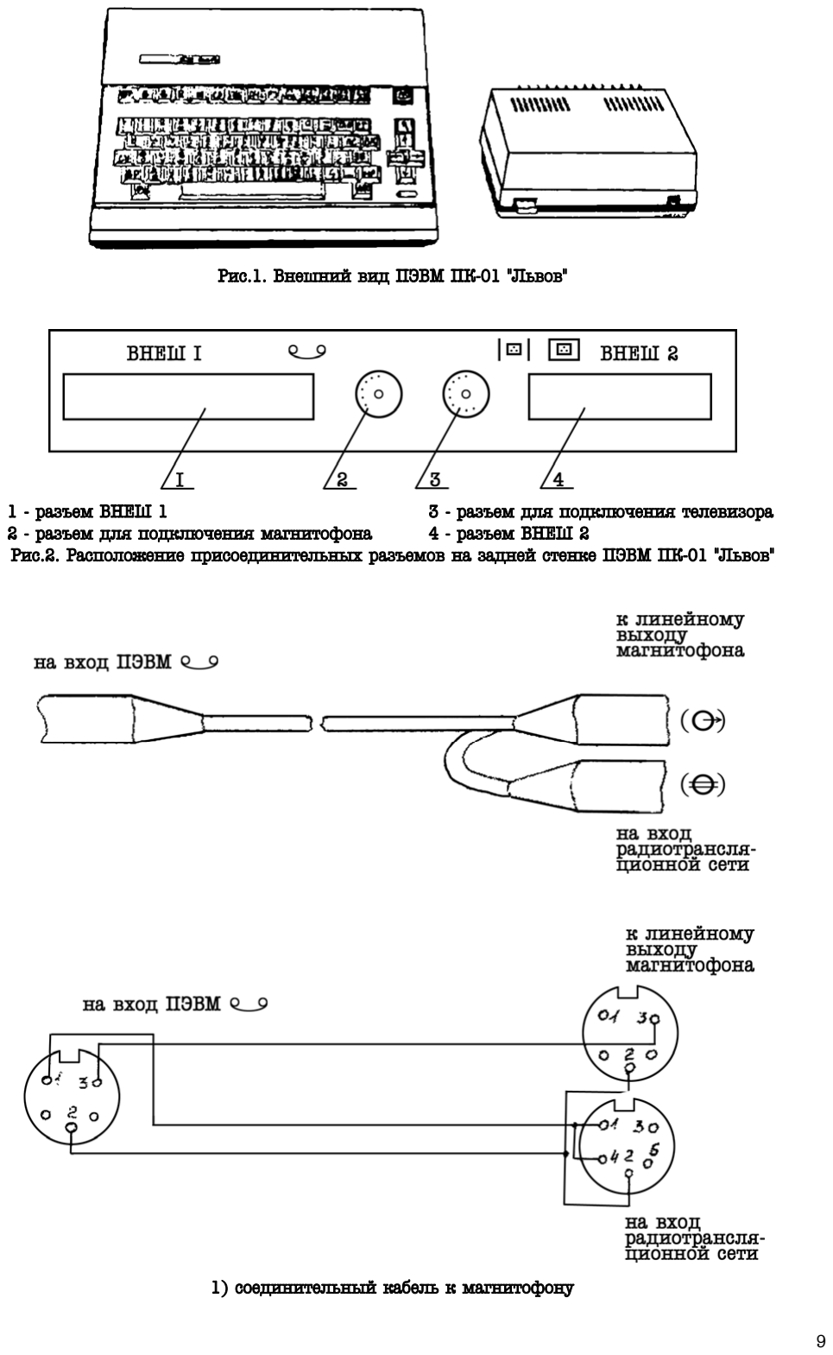
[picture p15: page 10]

Рис.1. Внешний вид ПЭВМ ПК-01 "Львов"

1 - разъем ВНЕШ 1 | 3 - разъем для подключения телевизора
2 - разъем для подключения магнитофона | 4 - разъем ВНЕШ 2
Рис.2. Расположение присоединительных разъемов на задней стенке ПЭВМ ПК-01 "Львов"
1) соединительный кабель к магнитофону

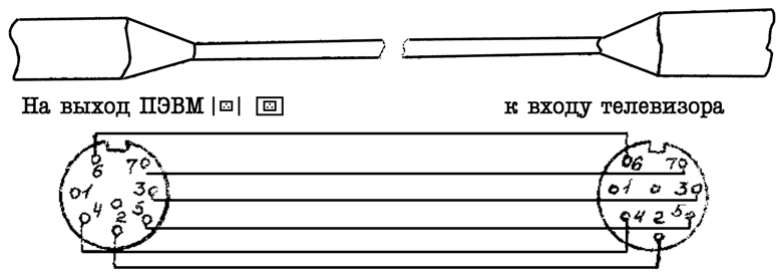
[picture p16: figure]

2) соединительный кабель к телевизору Рис.3. Соединительные кабели (схема распайки)
ВНЕШ 1 | ВНЕШ 2
Наименование сигнала | Номер контакта | Наименование сигнала | Номер контакта
А0 | 19 | Порт А0 | 39
А1 | 17 | Порт А1 | 37
А2 | 23 | Порт А2 | 35
А3 | 31 | Порт А3 | 33
А4 | 52 | Порт А4 | 31
А5 | 54 | Порт А5 | 29
А6 | 56 | Порт А6 | 27
А7 | 25 | Порт А7 | 25
А8 | 15 | Порт В0 | 5
А9 | 21 | Порт В1 | 3
А10 | 49 | Порт В2 | 1
А11 | 9 | Порт В3 | 7
А12 | 11 | Порт В4 | 9
А13 | 7 | Порт В5 | 11
А14 | 29 | Порт В6 | 13
А15 | 27 | Порт В7 | 15
A11 | 6 | Порт С2 | 6
A12 | 4 | Порт С3 | 8
A13 | 2 | Порт С5 | 19
D0 | 43 | Порт С6 | 21
D1 | 39 | Порт С7 | 23
D2 | 35
D3 | 33
D4 | 37
D5 | 41
D6 | 45

ВНЕШ 1 (продолжение)
Наименование сигнала | Номер контакта
D7 | 47
RESIN | 58
RESET | 1
W2 TTL | 51
HOLD | 59
INTE | 55
INTA | 5
I/OR | 3
I/OW | 53
MEMR | 51
MEMW | 13
HLDA | 50
0V | 18
+5V | 10
Рис.4. Распайка разъемов ВНЕШ 1 и ВНЕШ 2.

Таблица 1

контактов | Область применения | Номера контактов и их распайка Расположение
1 | 2 | 3 | 4 | 5
| Вход и выход магнитофона при записи и воспроизведении с магнитофона | МОНО | Сигнал записи | Экран | Сигнал воспроиз-ведения | Соединен с контактом 1
| | СТЕРЕО | Сигнал записи левого канала | Экран | Сигнал воспроиз-ведения левого канала | Сигнал записи правого канала | Сигнал воспроиз-ведения правого канала

6. ПОДГОТОВКА К РАБОТЕ И ПОРЯДОК РАБОТЫ С ПЭВМ
6.1. Подготовка к работе
6.1.1. Порядок установки
Установите ПЭВМ на место эксплуатации. Соедините с помощью кабелей ПЭВМ согласно рис.5 с
блоком | питания, | видеоконтрольным | устройством | (бытовым | телевизором) | и | бытовым
магнитофоном.

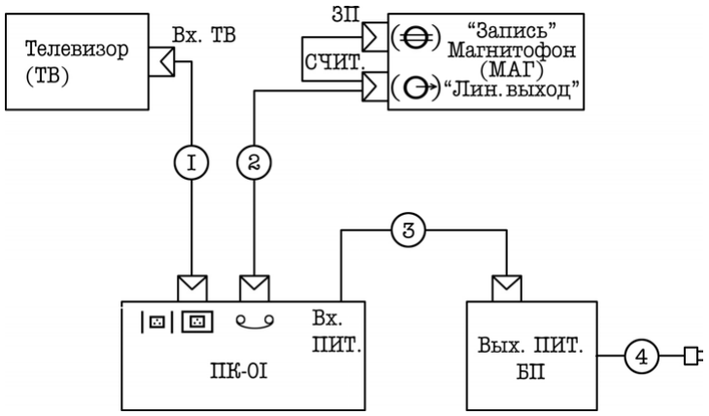
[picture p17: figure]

1 - Кабель соединительный к телевизору 2 - Кабель соединительный к магнитофону 3 - Кабель к БП
4 - Шнур питания сети
Рис.5

Проверьте положение кнопки СЕТЬ на БП и установите ее в отжатое положение. Включите вилку шнура питания БП в штепсельную розетку сети.
6.1.2. Порядок включения
В процессе эксплуатации необходимо соблюдать следующий порядок включения и выключения ПЭВМ и внешних устройств:
При включении
1) включить телевизор;
2) включить магнитофон;
3) включить ПЭВМ;
При выключении
1) выключить ПЭВМ:
2) выключить телевизор;
3) выключить магнитофон.
Примечание: Включение и подрегулировка телевизора и магнитофона производится в соответствии с руководствами по их эксплуатации.
Переведите кнопку СЕТЬ на БП в нажатое положение, при этом на экране устройства отображения (телевизора) должно появиться цветное изображение в виде случайного набора точек.

6.1.3. Начальная установка Начальная установка выполняется после включения ПЭВМ и периферийных устройств (ТВ, МАГ) и нажатия клавиши СБР на клавиатуре системного блока. После прохождения стартовой заставки на экране телевизора должно появиться сообщение:
BASIC 2.0 ПК-01 'ЛЬВIВ'
GO
т.е. ПЭВМ перешла в режим интерпретатора языка БЕЙСИК.
6.1.4. Проверка ввода информации с клавиатуры. Для проверки ввода информации с клавиатуры необходимо:
1) перевести ПЭВМ в режим БЕЙСИК согласно п. 6.1.3;
2) нажать клавишу РУС;
3) нажимая клавиши в соответствии с табл.2 символы верхнего регистра контролировать соответствие символа нажатой клавиши и символа, появляющегося на экране телевизора;
4) нажать клавишу ЛАТ;
5) проконтролировать появление на экране телевизора символов нижнего регистра в соответствии с табл.2; для ввода специальных символов необходимо перед нажатием соответствующей клавиши нажать и удерживать в нажатой состоянии клавишу HP;
6) нажать клавишу СТР, при этом на экране телевизора должно остаться рабочее поле в синей рамке; все символы должны стереться, кроме курсора в левом верхнем углу;
7) нажать клавишу G и несколько раз А - после каждого нажатия на экране должны появиться буква А зеленого цвета и курсор красного цвета; рамка отсутствует;
8) нажать клавишу В и несколько раз клавишу А - после каждого нажатия на экрана появится буква А белого цвета и курсор синего цвета; рамка отсутствует;
9) нажать клавишу R и несколько раз клавишу А - после каждого нажатия на экране появится буква А черного цвета и курсор красного цвета; рамка отсутствует;
10) нажать клавишу пробела и наблюдать на экране перемещение курсора на одно знакоместо (после каждого нажатия клавиши пробела наблюдается перемещение курсора на одно знакоместо);
11) нажать клавишу СТР - курсор переместится в верхний левый угол поля, а информация ранее выведенная на экран, исчезает;
12) нажать клавишу А три раза - на экране появятся три буквы А, затем нажать клавишу ЗБ два раза; при этом после каждого нажатия клавиши исчезает буква А, а курсор перемещается на одно знакоместо к началу строки;
13) нажать на любую алфавитно-цифровую клавишу и, удерживая ее в нажатом положении наблюдать повторный вывод соответствующего символа на экран;
14) нажать одновременно на 2-4 алфавитно-цифровые клавиши, удерживая их в нажатом положения, наблюдать на экране повторный вывод символов одновременно нажатых клавиш;
15) нажать клавишу СБР, затем клавишу <F2/ЗМЛ> - на экране должно появиться сообщение: CSAVE
6.1.5. Проверка количества символов в строке, количества строк Нажать клавишу СБР, затем нажимать многократно клавишу А до появления символа А на экране телевизора во второй строке и подсчитать количество символов (знакомест) в первой строке.
Число символов должно быть 32. Строка должна иметь вид:
А ... А
32 символа
Нажать клавишу СБР, CTР, затем удерживать клавиш А и <F5/AS> подсчитать число букв в столбце. Число букв должно быть 24.

6.1.6. Тестирование ОЗУ, ПЗУ
1) нажать клавишу СУ (удерживать);
2) нажать и отпустить клавишу СБР.
При неисправности выдается звуковой сигнал.
Если ПЭВМ исправна, то на экране стирается изображение и появляется сообщение: BASIC 2.0 ПК-01 'ЛЬВIВ'
GO
6.1.7. Проверка вызова интерпретатора языка бейсик Для вызова интерпретатора языка БЕЙСИК необходимо нажать клавишу СБР. На экране телевизора должно появиться сообщение:
BASIC 2.0 ПК-01 'ЛЬВIВ'
GO
6.1.8. Проверка обеспечения чтения информации с магнитофона Для проверки обеспечения чтения с магнитофона необходимо:
1) вызвать интерпретатор языка БЕЙСИК в соответствия с п. 6.1.7;
2) установить в магнитофон кассету с БЕЙСИК-ТЕСТОМ;
3) перемотать, если это необходимо, кассету на начало ленты и установить счетчик длины ленты в состояние 000;
4) нажать клавишу ЛАТ;
5) с помощью клавиш вывести на экран телевизора директиву CLOAD;
6) на магнитофоне нажать клавишу (ВОСПРОИЗВЕДЕНИЕ);
7) при показании счетчика длины ленты 002 нажать клавишу ВК и ждать появления на экране телевизора сообщения:
ФАЙЛ: BSTECT
KС: 02EBB0
GO
8) на магнитофоне нажать клавишу (СТОП);
9) для проверки введенной с магнитофона программы нажать клавишу ПС.
Тест проходит в диалоговом режиме: после появления заголовка BASIC-TECT необходимо выполнить действия предлагаемые на экране телевизора и ждать завершения теста.
Появление на экране телевизора алфавитно-цифровой и графической информации в соответствии с рис.6 свидетельствует о правильном считывании информации с магнитофона и исправном функционировании интерпретатора языка БЕЙСИК.

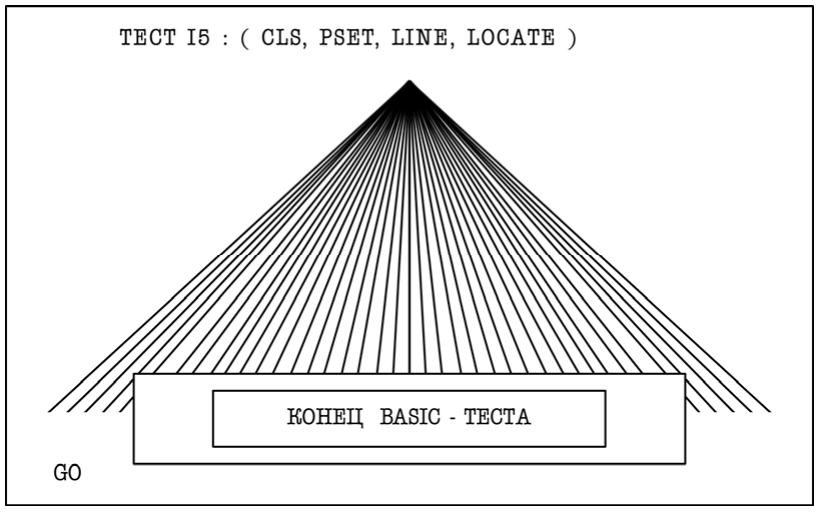
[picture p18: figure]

Рис.6
Общее количество линий сходящихся в точку - 38, цвета линии имеют следующее чередование при отсчете слева направо: зеленый - синий - красный - ... - синий.
6.1.9. Проверка обеспечения записи информации с ПК-01 на магнитофон Для проверки обеспечения записи информации с ПК-01 на магнитофон необходимо:
1) заменить в магнитофоне кассету с БЕЙСИК-ТЕСТОМ, на любую другую, пригодную для записи;
2) вывести с помощью клавиатуры на экран телевизора директиву:
СSАVE "BSTECT"
3) перевести магнитофон в режим ручной регулировки уровня записи и установить средний уровень, отключав при этом внутренний микрофон. Затем перевести магнитофон в состояние записи в начало рабочего участка ленты;
4) при установке счетчика длины ленты в состояние 005 нажать клавишу ВК;
5) ждать появления на экране телевизора сообщения:
КС: 02EBB0
GO
6) нажать на магнитофоне клавишу (СТОП).
Произвести проверку обеспечения записи контрольной программы на кассету путем чтения ее согласно п. 6.1.8.
При работе со стереофоническим магнитофоном устанавливать режим МОНО.

6.1.10. Проверка вывода графической информации и размера поля Проверка вывода графической информации и размера поля производится в следующем порядке:
1) набрать на клавиатуре, наблюдая вывод на экран телевизора графического оператора: LINE(0,0)-(199,221),3,В
и нажать клавишу ВК.
При этом синяя рамка с внутренней стороны должна быть окантована красным цветом (оператор выводит на экран красный прямоугольник).
Нажимать клавишу А - до появления символа А в следующей строке, при этом красная вертикальная линия должна быть правее ближайшего крайнего символа А.
Безошибочное выполнение всех требовании п. 6.1 свидетельствует об исправности ПЭВМ и готовности ее к работе.
6.2. Порядок работы с ПЭВМ
6.2.1. Основные положения
Вы подготовили к работе ПЭВМ (а также телевизор и магнитофон) согласно п. 6.1 настоящего РЭ. Перед эксплуатацией необходимо изучить документ "Описание языка БЕЙСИК"
С помощью вышеуказанного документа Вы можете загрузить программы, написанные на языке высокого уровня, и работать с ними.
Если у Вас появится желание разработать собственную программу (программу пользователя), то Вам необходимо изучить описание языка БЕЙСИК, а также порядок работы в диалоговом режиме под управлением программы языка высокого уровня.
Интерпретатор языка высокого уровня БЕЙСИК хранится в ПЗУ и готов к работе сразу же после включения питания ПЭВМ. Под его управлением выполняются прикладные программы и программы пользователя.
При разработке новой программы ее текст вводится в ПЭВМ с помощью клавиатуры.
С выключением питания ПЭВМ, находящаяся в ней разработанная Вами программа старается. Если разработанную программу предлагается использовать неоднократно, то ее необходимо записать на магнитофонную кассету. Таким образом, с течением времени Вы сможете составить и хранить библиотеку разного назначения.
6.2.2. Режим работы
После включения ПЭВМ и начальной установки (нажать клавишу СБР) управление передаётся БЕЙСИКу.
Состояние БЕЙСИК позволяет выполнять подготовку, корректировку, запись и чтение с магнитофона файла данных, а также подготовку, отладку, выполнение программ. Некоторые директивы запускаются на выполнение путем нажатия функциональной клавиши:
<F1/ЧМЛ> - режим чтения файла;
<F2/ЗМЛ> - режим записи;
и др.
Назначение функциональных клавиш ПЭВМ приведено в табл.3.

6.2.3. Порядок работы
ПЭВМ обслуживается одним пользователем. Последовательность операций при работе с ПЭВМ следующая:
1) порядок установка согласно п. 6.1.1;
2) порядок включения согласно п. 6.1.2;
3) начальная установка согласно п. 6.1.3;
4) выполнение работ по подготовке, вводу и выполнению программ на языке БЕЙСИК.
6.2.4. Выполнение работ по подготовке, вводу и выполнению программ на языке БЕЙСИК:
1) для вызова интерпретатора БЕЙСИК необходимо нажать клавишу СБР на системном блоке; при этом на экране появится сообщение:
BASIC 2.0 ПК-01 'ЛЬВIВ'
GО
2) программа, подготовленная на языке БЕЙСИК в соответствии с документом "Описание языка БЕЙСИК" может быть введена в ПЭВМ с помощью клавиатуры или с ранее подготовленной кассеты с помощью магнитофона:
ввод и корректировка программы с клавиатуры осуществляется в соответствии с документом "Описание языка БЕЙСИК";
для ввода программы с кассеты необходимо: установить кассету в магнитофон, перемотать кассету на начало программы по счетчику в соответствии с документом "Описание языка БЕЙСИК", перевести магнитофон в режим "ВОСТРОИЗВЕДЕНИЕ", нажать клавишу ВК.
В процессе ввода программы через динамик магнитофона прослушивается характерный звук. Для надежного ввода программы желательно чтение программы запустить (нажать клавишу ВК) на чистом участке ленты магнитофона. После успешного ввода программы на экране появится имя считанной программы и приглашение к диалогу GO. Введенная программа может быть исправлена, запущена для выполнения, записана на кассету.
В процессе исправления или отладки программы при выполнении директив IIST (RUN) возможны следующие режимы:
приостановка распечатки (выполнение программы) путем нажатия клавиши <F5/AS> в конце выдачи (выполнения) текущей строки программы;
после приостановки возможна распечатка (выполнение программы) по одному оператору путем повторного нажатия клавиши <F5/AS>;
продолжение непрерывной распечатки (выполнение программы) путем нажатия клавиши пропуск; окончание распечатки или выполнения программы (выход на приглашение к диалогу G0) после приостановки путем нажатия клавиши <F5/AS> или в случае непрерывного выполнения путем двукратного нажатия клавиши FO;
редактирование программы по операторам при выполнении директивы EDIT (см. "Описание языка БЕЙСИК"), при этом клавиши со стрелками управляют перемещением курсора, клавиша ГT раздвигает текст, а клавиша ЗБ уничтожает текст по символам;
выход с EDIT - после нажатия клавиши ВК;
3) введенная с клавиатуры или кассеты и отлаженная программа может быть записана на кассету. Для этого необходимо:
перевести магнитофон в режим ручной регулировки уровня записи и установить средний уровень записи;
отключить (при наличии) встроенный микрофон;
установить ленту по счетчику магнитофона на необходимую позицию;
набрать директиву CSAVE в соответствии с документом "Описание языка БЕЙСИК";
перевести магнитофон в режим "ЗАПИСЬ" и с некоторой задержкой (4-5 с) нажать клавишу ВК.

В процессе записи через динамик магнитофона будет прослушиваться характерный звук. После окончания записи на экране устройства отображения появится приглашение к диалогу GO. Введенная программа может быть запущена на выполнение с помощью директивы RUN после нажатия клавиши ВК, отлажена и снова записана на кассету с помощью директивы CSAVE, SAVE.
6.2.5. Работа ПЭВМ в режиме калькулятора Перед началом работы в режиме калькулятора выполнить начальную установку ПЭВМ путем нажатия клавиши СБР.
Произвести вызов интерпретатора языка БЕЙСИК (нажать клавишу СБР).
Если при программировании на языке БЕЙСИК в служебном слове опустить номер строки, то такая директива выполняется немедленно. Это свойство используется для работы ПЭВМ в режиме калькулятора.
Пример
Выполнить следующее вычисление:
(2,55 + 1,45)^2 х 6.48 / 3,24 =
Для этого необходимо вывести на экран телевизора при помощи клавиатуры (в соответствии с руководством пользователя) оператор PRINT и последовательный набор числовых и символьных данных, соответствующий решаемому примеру:
(2.55 + 1.45)^2 * 6.48 / 3.24
Нажать клавишу ВК и прочитать на экране телевизора результат вычисления приведенного примера: 32
6.2.6.Работа с устройствами пользователя Устройством пользователя может быть любой прибор, электрически сопрягаемый с цепями разъемов BHEШ 1, ВНЕШ 2 ПК-01 и управляемый с помощью программ составленных Вами.
Пример сопряжения ПЭВМ с бытовыми приборами и устройствами:
1) датчики (температуры, влажности, освещенности, времени и т.д.) подключаются через аналого-цифровой преобразователь (АЦП) к разъему BНЕШ 1;
2) к разъему ВНЕШ 2 через цифро-аналоговый преобразователь (ЦАП) подключаются исполнительные устройства (нагреватели, осветительные приборы, телефон, телевизор, магнитофон, печатающая машинка и т.д.).
Программа, составленная Вами, анализирует состояние линий ввода и изменяет состояние линий вывода.
Так могут поддерживаться требуемый микроклимат в помещении и его освещенность, включение и выключение в определенный момент на заданный промежуток времени телевизора, магнитофона, осуществление записи транслируемых в Вашем отсутствии музыкальных программ, телефонных разговоров и т.д.
Примечание: На кассете МК-60-2 (МК-60-5) после программы БЕЙСИК-ТЕСТ записаны игровая и учебная программы, "РАКЕТА" и "КЛАВИАТУРА" соответственно. Запись программ в ПЭВМ и их запуск производится согласно п. 6. При этом контрольные суммы учебной и игровой программ указаны на кассете. Правила пользования программами оговорены в тексте, выводимом на экран устройства отображения информации (телевизора) после запуска программ (нажатия клавиши ПС). Начало программ по счетчику расхода ленты указано на кассете. Частота воспроизведения смешанных цветов зависят от качества регулировки конкретного устройства (телевизора), при этом возможны оттенки смешанных цветов, в том числе цветные оттенка белого.

6.3. Порядок выключения ПЭВМ Перевести кнопку СЕТЬ на БП в отжатое положение, при этом лампочка индикации должна погаснуть. Выключить магнитофон.
Выключить телевизор.
Дополнительные программы (игровые, учебные, инженерные и др.) могут быть приобретены за отдельную плату. Имеется более 100 программ, которые постоянно уточняются и развиваются по мере приобщения различных групп пользователей.
Таблица 2
Символы верхнего регистра | Символы нижнего регистра
Символ | Символ | Символ | Символ
; | Ф | + | F
1 | Ы | ! | E
2 | В | " | W
3 | А | # | A
4 | П | $ | P
5 | Р | % | R
6 | О | & | O
7 | Л | ‘ | L
8 | Д | ( | D
9 | Ж | ) | V
0 | Э | | \
_ | . | = | >
Й | Я | J | Q
Ц | Ч | C | ^
У | С | U | S
К | М | K | M
Е | И | E | I
Н | Т | N | T
Г | Ь | G | X
Ш | Б | [ | B
Щ | Ю | ] | @
З | , | Z | <
Х | / | H | ?
: | | * | _

Примечание: Большая клавиша на клавиатуре ПЭВМ - клавиша пропуска, с помощью которой получают пробелы в тексте.

Таблица 3
НАЗНАЧЕНИЕ ФУНКЦИОНАЛЬНЫХ КЛАВИШ
Клавиша | Назначение | Примечание
СТР | Стирание экрана
G | Переключение на вывод текста в зеленом цвете без рамки
В | Переключение на вывод текста в белом цвете без рамки
R | Переключение на вывод текста в черном цвете без рамки
F0 | Прекращение выполнения директивы и программы (после двойного нажатия) и выход на приглашение к диалогу
<F3/BS> | Ввод директивы LIST
<F4/ED> | Ввод директивы EDIT построчного | Использование смотри в документе "Описание языка БЕЙСИК"
<F5/AS> | Приостановка программы и аннулирование строки
<F1/ЧМЛ> | Ввод директивы CLOAD
<F2/ЗМЛ> | Ввод директивы CSAVE
П/Д | Вкл/выкл вывода информации на дисплей и на экран
ПЧ | Вкл/выкл вывода информации на печать
CD | Вкл/выкл вывода информации на экран по страницам
(ДИНАМИК) | Вкл/выкл звукового сигнала. Назначение клавиш управления
СБР* | Начальная установка ПЭВМ | Стирание информации ОЗУ см."Описание языка БЕЙСИК"
СУ | Управляющий символ
ПС | Перевод строки
ВК | Возврат каретки
ГТ | Вывод на экран изображения
HP | Нижний регистр
ВР | Верхний регистр
ЗБ | Стирание информации
РУС | Русский алфавит
ЛАТ | Латинский алфавит
(HOME) | Установка курсора в верхний левый угол экрана
(СТРЕЛКИ) | Управляющие положение курсора
ТАБ | Табуляция

* Если при нажатой клавише Ц нажать и отпустить клавишу СБР содержимое ОЗУ не стирается.

7. ТЕХНИЧЕСКОЕ ОБСЛУЖИВАНИЕ ПЭВМ
7.1. Перечень и содержание работ по техническому обслуживанию Перечень и содержанке работ по техническому обслуживанию, которые владелец может совершить самостоятельно, без нарушения пломб, приведены в табл.4.
7.2. Периодичность и порядок работ по техническому обслуживанию В случае длительного перерыва в работе (более 1 месяца) необходимо произвести перепроверку ПЭШ по разделу 6 настоящего документа.
7.3. Порядок замены предохранителей
1. Выключить изделие согласно п. 6.3.
2. Вынуть сетевой шнур из розетки.
3. Нажать и повернуть против часовой стрелки головку держателя предохранителя.
4. Извлечь из головки вышедший из строя предохранитель.
5. Вставить в головку новый предохранитель.
6. Вставить головку в держатель. Нажать и повернуть по часовой стрелке до фиксации головки в держателе.
7.4. Возможные неисправности и методы их устранения Перечень неисправностей и методы их устранения, которые владелец может выполнить самостоятельно при помощи внешних органов управления ПЭВМ приведены в табл.5.
В случае если владелец не может самостоятельно устранить неисправность, следует обратиться в ремонтное предприятие (см. приложение 2).
Таблица 4
Что проверяется | Технические требования | Метод проверки | Периодичность проверки
ПЭВМ ПК-01 | Проверка проводится после включения ПЭВМ | После выполнения начальной установки по п. 6.1.3 провести тестирование ОЗУ, ПЗУ согласно п. 6.1.6 | В процессе работы не менее 1 раза в день

Таблица 5
Наименование неисправности | Вероятная причина | Метод устранения | Примечание
1.На включенном исправном устройстве отображения не появляется изображение | 1) перепутаны кабели соединения с устройством 2) перегорел предохранитель блока питания ПЭВМ 3) неисправна ПЭВМ | 1) устранить 2) заменить предохранитель 3) вызвать техника по ремонту
2.Не выполняется начальная установка по п.6.1.3 | 1) сбой по питанию 2) неисправна ПЭВМ | 1) выключить блок питания ПЭВМ и через 30 сек. повторить включение и начальную установку 2) вызвать техника по ремонту
З.Не читается информация с кассеты при включенном и исправном магнитофоне | 1) перепутаны кабели "считывания-записи" 2) грязная головка магнитофона 3) неисправна ПЭВМ | 1) устранить 2) протереть головку в соответствии с инструкцией к магнитофону 3) вызвать техника по ремонту

8. ГАРАНТИЙНЫЕ ОБЯЗАТЕЛЬСТВА Персональная ЭВМ ПК-01 "Львов" соответствует утвержденному образцу.
Изготовитель гарантирует соответствие изделия требованиям ГОСТ 21552-84, техническим условиям ЯП1.790.002 ТУ при соблюдении владельцем правил эксплуатации, изложенных в руководстве по эксплуатации.
Гарантийный срок эксплуатации персональной ЭВМ ПК-01 "Львов" 12 месяцев со дня продажи через розничную торговую сеть.
При отсутствии даты продажи и штампа магазина в гарантийном и отрывных талонах, гарантийный срок исчисляется со дня выпуска изделия предприятием-изготовителем.
В течение гарантийного срока эксплуатации владелец имеет право в случае отказа изделия ПК-01 "Львов" на бесплатный ремонт по предъявлению гарантийного талона.
При этом за первый ремонт вырезают отрывной талон, соответствующий выполняемой работе. Последующий в течение гарантийного срока ремонт выполняют также бесплатно и записывают данные о виде ремонта в учетно-техническую карточку, которая находится в ремонтном предприятии и на обратной стороне гарантийного талона.
Ремонт изделия ПК-01 "Львов" выполняют ремонтные предприятия, информацию о которых можно получить в магазине радиотоваров.
Без предъявления гарантийного и отрывного талонов и (или) при нарушении сохранности пломб на изделии претензии к качеству работы не принимаются и гарантийный ремонт не производится.
В течение гарантийного срока эксплуатации, установленного на изделие, ремонт производится за счет владельца в случае, если он эксплуатирует его не в соответствии с настоящим руководством по эксплуатации или не выполняет рекомендаций ремонтного предприятия, направленных на обеспечение нормальной работе ПК-01.
Обмен неисправных персональных ЭВМ ПК-01 "Львов" осуществляется через торговую сеть по предъявлении справки ремонтного предприятия и гарантийного талона в соответствии с действующими правилами обмена промышленных товаров, купленных в розничной сети государственной и кооперативной торговли.
Срок хранения персональной ЭВМ ПК-01 "Львов" не должен превышать 12 месяцев.
Примечание. При отказе в изделия отдельного блока (ПК-01 или БП) обмен по желанию владельца может производиться в целом или отдельно отказавшего блока.

Действителен по заполнении ЛЬВОВСКОЕ ПРОИЗВОДСТВЕННОЕ ОБЪЕДИНЕНИЕ им. В.И.ЛЕНИНА Цена 750 руб. Прейскурант № 139-1977/131. поз. 915 и доп. 139 ГАРАНТИЙНЫЙ ТАЛОН
Заполняет предприятие-изготовитель Персональная ЭВМ ПК-01 "Львов" № К04317 (БП № К04003) Дата выпуска 04.1990 г.
Представитель ОТК предприятия-изготовителя ОТК 0321 290601 г.Львов, ГСП, ДПО им. В.И.Ленина
Дата продажи _______________ (число, месяц, год) Продавец __________________ (подпись или штамп) Штамп магазина
Поставлен на гарантийное обслуживание ______________ (наименование ремонтного предприятия, число, месяц, год) Гарантийный номер ____________

Действителен по заполнении ЛПО им. В.И.Ленина
ОТРЫВНОЙ ТАЛОН НА ГАРАНТИЙНЫЙ РЕМОНТ В ТЕЧЕНИЕ ПЕРВОГО ГОДА ГАРАНТИИ Заполняет предприятие-изготовитель Персональная ЭВМ ПК-01 "Львов" № К04317 (БП № К04003) Дата выпуска 04.1990 г.
Представитель ОТК предприятия-изготовителя ОТК 0321 ________________________________________
штамп ОТК
290601 г.Львов, ГСП, ЛПО им. В.И.Ленина Заполняет торговое предприятие
Дата продажи _____________ (число, месяц, год) Продавец _______________________ (подпись или штамп) Штамп магазина

(оборотная сторона)
действителен по заполнении Заполняет ремонтное предприятие Гарантийный номер изделия _________________________ Содержание ремонта. Наименование и номер по схеме замененной детали или узла. Место и характер дефектов:
Дата ремонта _________________ (число, месяц, год) Подпись лица, производившего ремонт _________________ Подпись владельца изделия, подтверждающая ремонт ___________ Штамп ремонтного предприятия с указанием города

ПРИЛОЖЕНИЕ 1
Перечень применяемых в тексте сокращений, условных обозначений, терминов и определений БП - блок питания
ТВ - телевизионный приемник
МАГ - кассетный магнитофон
ОЗУ - оперативное запоминающее устройство, часть памяти ЭВМ, предназначенная для временного хранения программ, данных, промежуточных и окончательных результатов решения задач
ПЗУ - постоянное запоминающее устройство, предназначенное для хранения редко изменяемой (постоянной) информации
ПО - программное обеспечение
АЦП - аналого-цифровой преобразователь. Функциональный узел, который преобразует аналоговую величину в код
ЦАП - цифро-аналоговый преобразователь. Функциональный узел, осуществляющий преобразование кода в аналоговую величину
ПЭВМ - персональная электронно-вычислительная машина
Машинный язык - язык программирования, предназначенный для представления программ в форме, которая позволяет выполнять ее техническими средствами обработки данных Алгоритмический язык - язык, предназначенный для представления алгоритмов Машинно-ориентированный язык - машинно-зависимый язык программирования
Курсор - специальный символ на экране дисплея, указывающий место на экране, где производится та или иная операция ввода или редактирования информации
ИНТЕРПРЕТАТОР - программа или техническое средство, выполняющее интерпретацию Прикладная программа - программа, подготовленная пользователем и предназначенная для решения задач в определенной области.
Язык БЕЙСИК - проблемно-ориентированный язык программирования

ПРИЛОЖЕНИЕ 2
АДРЕСА РЕМОНТНЫХ ПРЕДПРИЯТИЙ
1. 113184 г.Москва, ул. Новокузнецкая, 17/19
2. 195027 г.Ленинград, Свердловская набережная, 64
3. 375090 г.Ереван, Пятый Норгский массив, 13а-13б
4. 480091 г.Алма-Ата, ул.Гоголя, 42
5. 420066 г.Казань, ул.Ибрагимова, 83а
6. 220004 г.Минск, ул.Опанского, 4
7. 173015 г.Новгород, ул. Псковская. 24
8. 290049 г.Львов, ул.Патона, 32
9. 17490. г. Москва, ул. Наметкина, 12, Мосгорремонторгтехниха
10. 220012, г. Минск, переулок К. Черного, 5, Экспериментальное производственное объединение "Триумор"
11. 274005, г.Черновцы, ул. Ленина, 189, ПО "БРТ"
12. 330089, г. Запорожье, ул. Песчаная, 3, Предприятие вычислительной техники и информатики
13. 270057, г. Одесса, ул. Баранове, 27, Предприятие вычислительной техники и информатики
14. 226001, r, Рига, ГСП, ул. А. Барбоса, 9, "Электронас"
15. 340059, г. Донецк, ул. Гутченко, 26, Предприятие бытрадиотехника
16. 252005. г. Киев, уд. Красноармейская, 63, КЗТОРВТ
17. 290024, г. Львов, ул. Богдана Хмельницкого, 157, Предприятие вычислительной техники и информатики
18. 327017. г. Николаев, ул. Советская. 13, ОПО "БРТ"
В случае отсутствия ремонтных мастерских по гарантийному ремонту необходимо обращаться на предприятие-изготовитель ПК: г.Львов, 290040, ПО им. В.И. Ленина.

ПРИЛОЖЕНИЕ 3
ПЕРЕЧНИ РАДИОЭЛЕМЕНТОВ
(приложение в рукописной форме)

ПРИЛОЖЕНИЕ 4
ЭЛЕКТРОМОНТАЖНЫЕ ЧЕРТЕЖИ ПЕЧАТНЫХ ПЛАТ

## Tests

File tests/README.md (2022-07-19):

# Test cases

This directory contains simple assembler programs that I used for diagnosing the machine. 

Note: 

* assemble with https://github.com/Megatokio/zasm
  * I use `zasm` with `--8080` flag (i.e. Z80 syntax, but 8080 instructions only), because I'm much more familiar with Z80 assembler mnemonics. 
  * `make` should just work on Linux

* tests use no stack, no variables in RAM - the idea was to run anything, before being sure RAM works at all.

Tests:

* [01_hello_pio.asm](01_hello_pio.asm) 
  * outputs `0xAA, 0x55, 0xAA, 0x55... ` on PA port of the on-board 8255 
* [02_dump_roms.asm](02_dump_roms.asm)
  * dumps EPROMs address space, i.e. `0xC000..0xFFFF` via `PA` port, `PB2` is used as strobe signal, so it can be captured using a logic analyzer
  * of course, the first EPROM is replaced with the one containing the test code itself
* [03_test_ram.asm](03_test_ram.asm)
  * note: I needed some way to test RAM without actually using it for stack / variables.
  * RAM (all 64kB) is first filled  with a pseudo-random sequence, then it's dumped via `PA` port (`PB2` as strobe, as before)
  * 16-bit [LFSR](https://en.wikipedia.org/wiki/Linear-feedback_shift_register) is used to generate pseudo-random (but deterministic) sequence of bytes, table for LFSR was generated using [pycrc](https://pycrc.org/)
  * Python code in [gen](gen) generates the very same sequence 
  * it can be compared with whatever was captured with logic analyzer to check if RAM operates properly
* [04_video.asm](04_video.asm)
  * generate simple skewed color bars to verify, that the video output works properly

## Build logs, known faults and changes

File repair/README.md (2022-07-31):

# Repair process

Below is my (informal) repair logbook.

## Hardware debugging 

#### 1. Power supply rails

   * all OK

#### 2. Clocks at D4 (8224)

   * `Φ1`, `Φ2`, `Φ2TTL` - all OK

     This is how `Φ1`, `Φ2` clocks look like (see the voltages? it's not TTL!) :

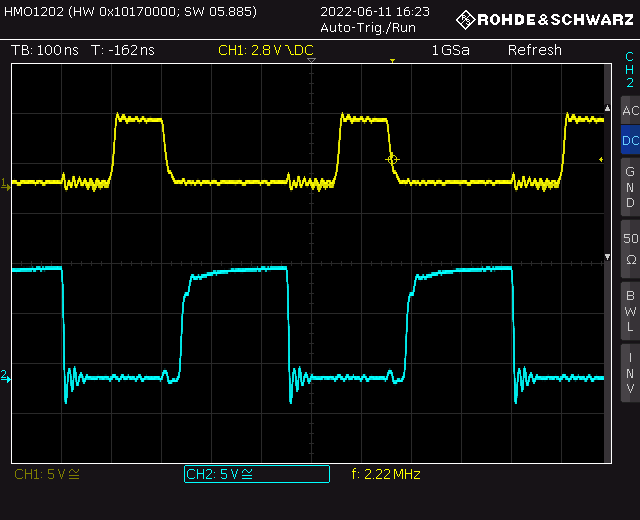
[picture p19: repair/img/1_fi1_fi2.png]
     

   * `OSC` - 20MHz - OK
     
     At 20 MHz it doesn't look like square wave anymore ;)
     
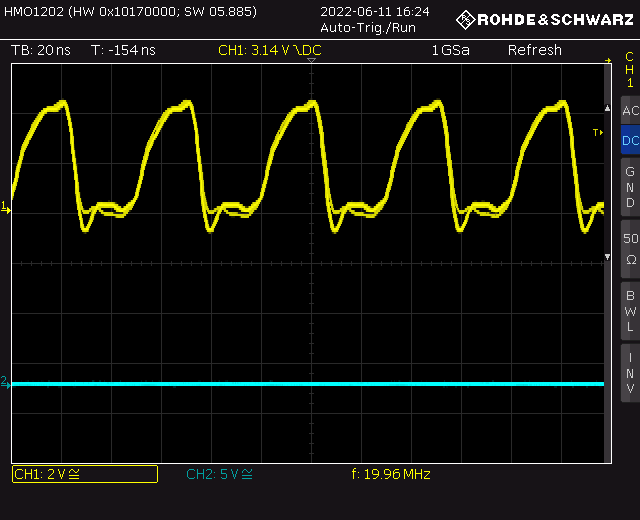
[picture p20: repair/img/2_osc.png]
     

   * `RESET` signal - OK

#### 3. STSTB - fault #1 

* I've checked `~MEMR`, `~MEMW`, etc. signals. It looked like the CPU is alive, but one signal looked invalid - `STSTB` (yellow trace):

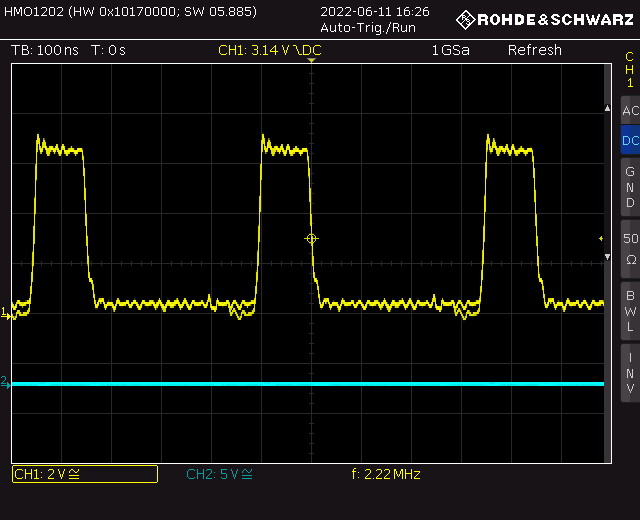
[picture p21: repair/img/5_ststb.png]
  

  * Most notably it exceeds 5V. Looking around I've found a short to Φ1 on the PCB. 

  * I guess it's the first time ever I **fix a problem with a toothbrush** :)

* with short removed, `STSTB` signal looked correctly:

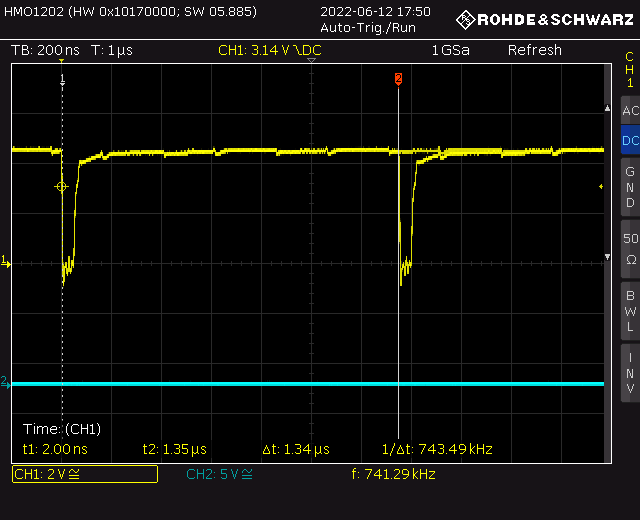
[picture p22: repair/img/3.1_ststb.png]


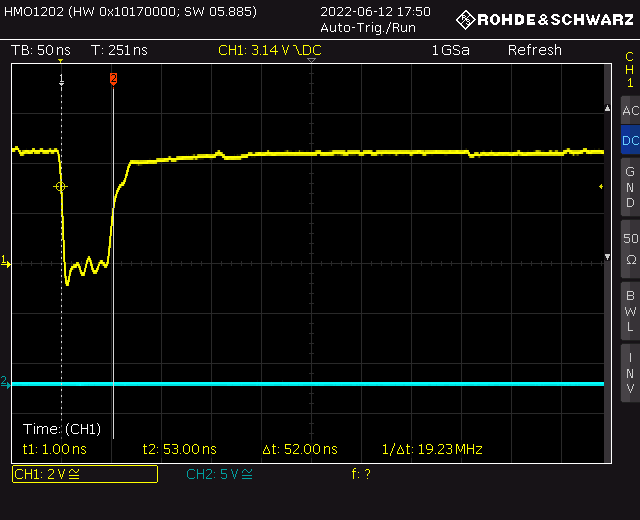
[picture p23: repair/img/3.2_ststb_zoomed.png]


* believe it or not, the problem is inside the red circle :)

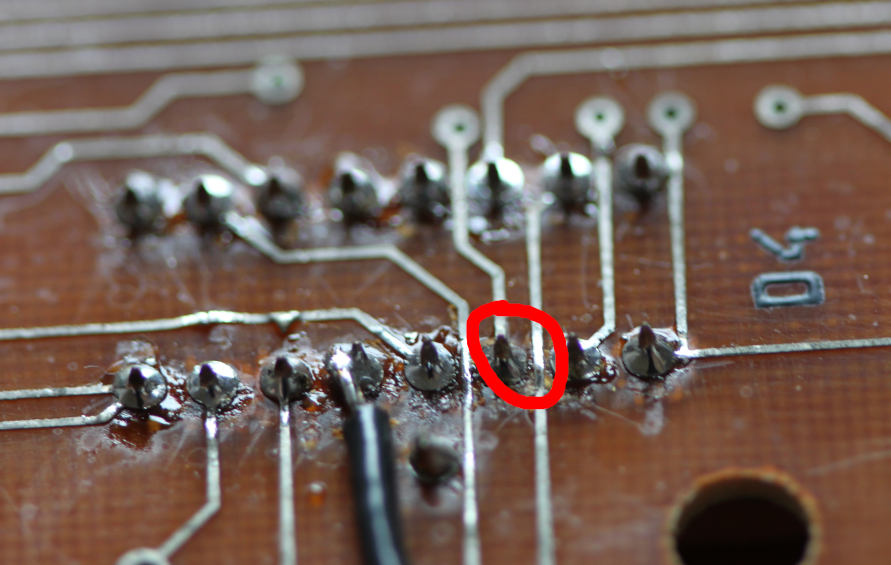
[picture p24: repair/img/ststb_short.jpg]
  

#### 4. Timing block

* `D34` - in @ 20MHz OK, T3 at 1.25Mhz OK

* `mod 80` counting block

  * `T_RST1` is high for 16 cycles, i.e. `16 / 1.25MHz = 12.8μs`- OK

  * full cycle `1.25MHz / 80 = 15 625 Hz` - OK

  * below `A` (i.e. `T_RST1`) and `~Q` of `D43A`

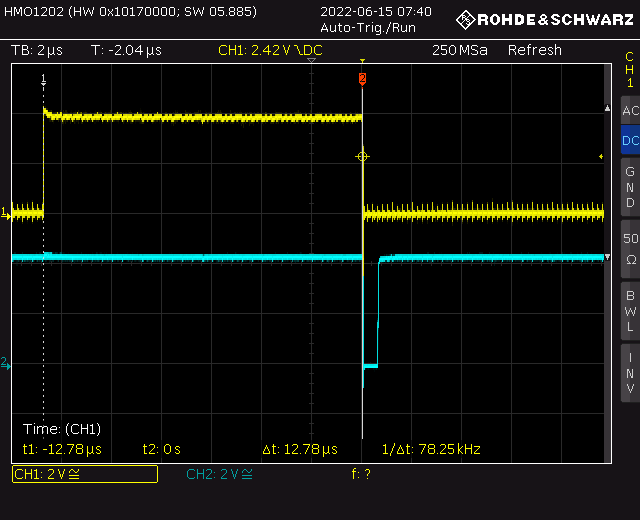
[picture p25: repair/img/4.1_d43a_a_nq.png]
    

  * below zoomed on  `~Q`output negative pulse:

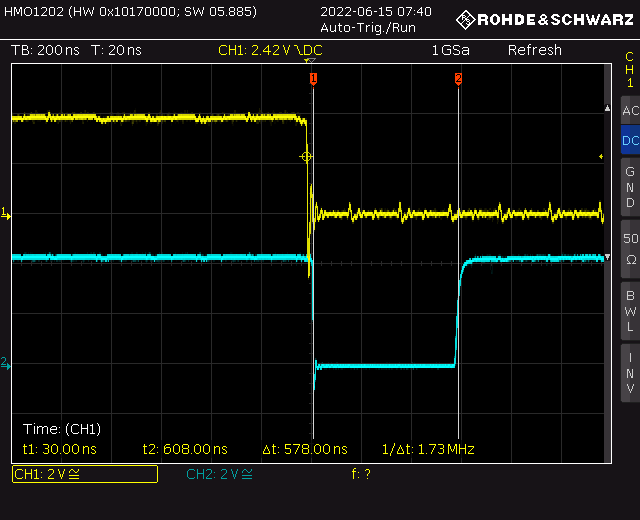
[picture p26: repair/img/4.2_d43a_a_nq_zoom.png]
    

* `mod 320` counter

  * full cycle: `15 625 / 320 = 48.82Hz` (this is vertical video sync frequency)

  * `T_RST2` - high for  64 cycles, i.e.  `64 / 15 625 = 4.096ms`

  * below: `A` and `~Q` of `D43B`:

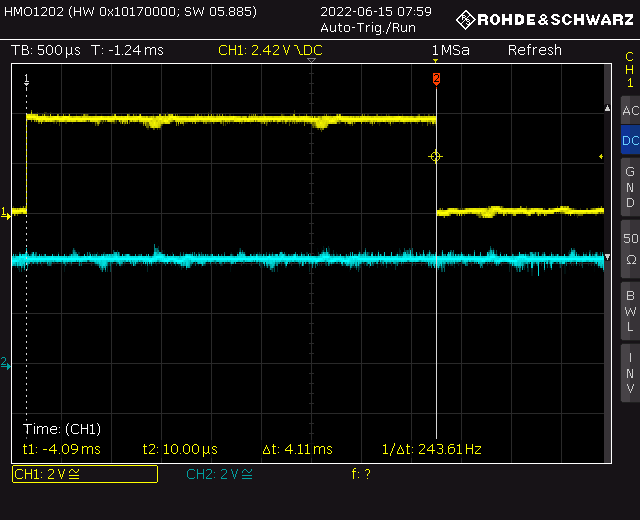
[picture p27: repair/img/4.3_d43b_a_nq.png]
    

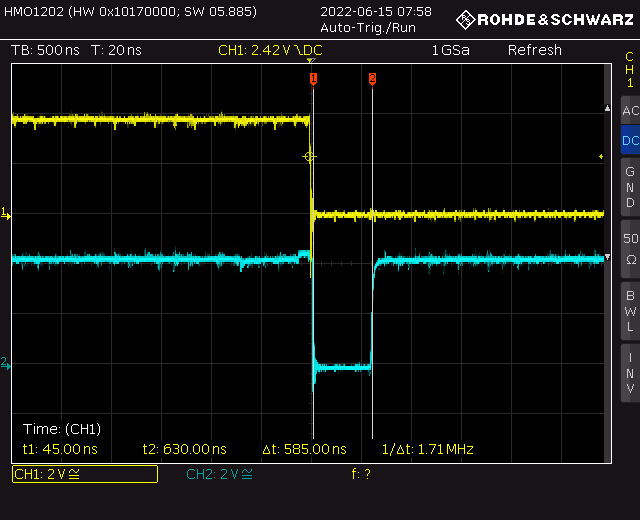
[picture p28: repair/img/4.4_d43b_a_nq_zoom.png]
    

#### 5. RAM controller - fault #2

* given that timing counters are working fine, there should be proper RAM cycles generated (`RAS`, `CAS`, address mux control signals, etc.)

  * nope..

* narrowed to a broken `D49` (`74138`) chip (3 bits to 1-of-8 decoder)

* after replacing `D49` it appeared to work, but I've decided to leave it as is and move on to other blocks, assuming I will get back to RAM later

  * spoiler: all was fine in this block

#### 6. Video block

* given that timing generator and RAM controller works, I decided to take a look at video block

* horizontal sync pulses looked as expected:

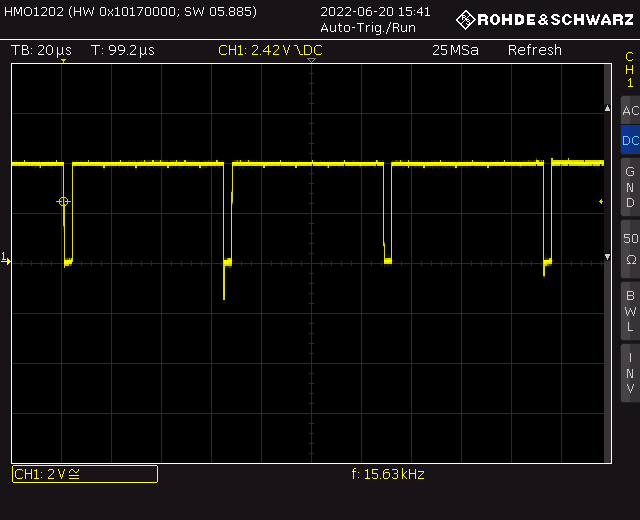
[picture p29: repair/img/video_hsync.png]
  

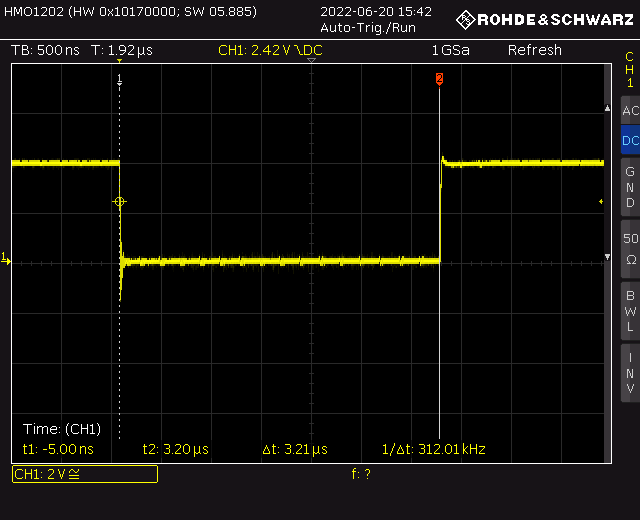
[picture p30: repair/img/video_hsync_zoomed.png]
  

* vertical sync pulses also looked fine:

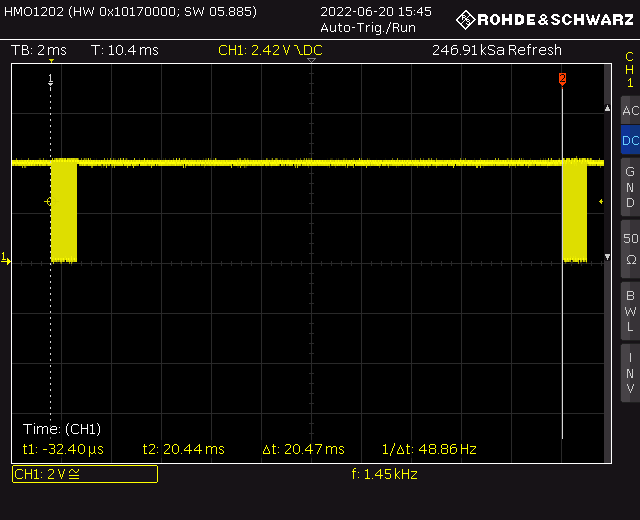
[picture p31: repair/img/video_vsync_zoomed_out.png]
  
  
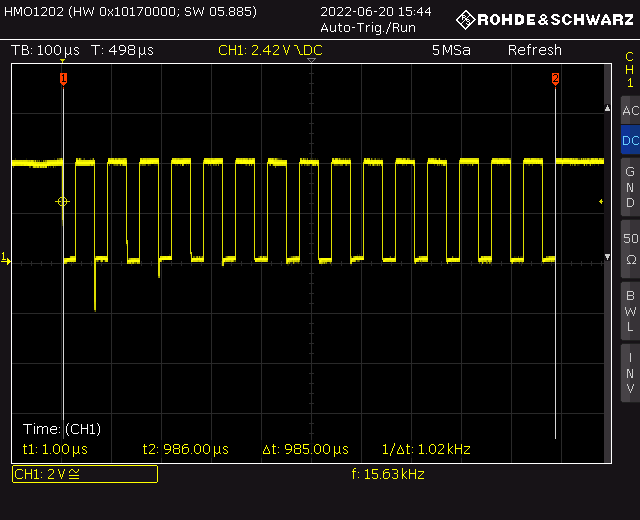
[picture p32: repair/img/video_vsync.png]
  
  
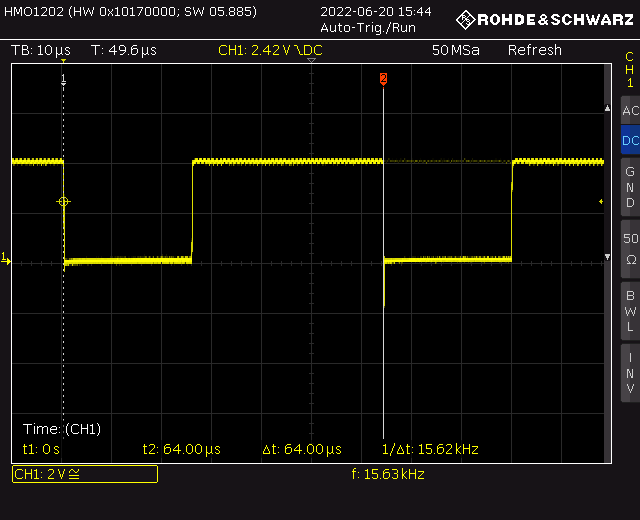
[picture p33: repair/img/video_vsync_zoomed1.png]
  
  
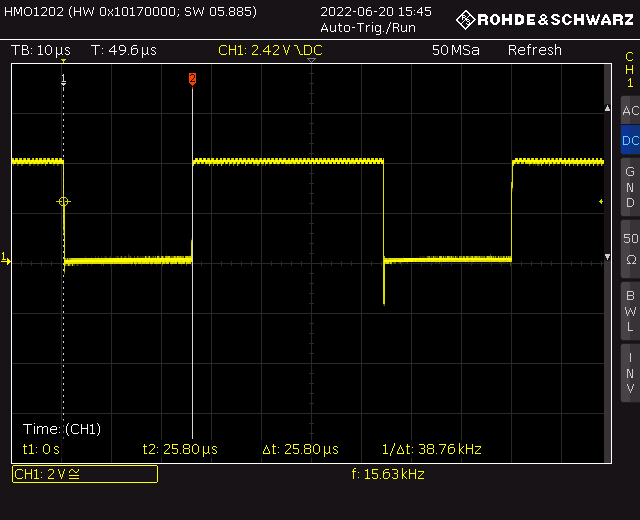
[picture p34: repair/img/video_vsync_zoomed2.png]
  

* I've also checked the pixel shift register (`D55`) input signals:

  * parallel load strobe (blue one, yellow is timing signal for reference):

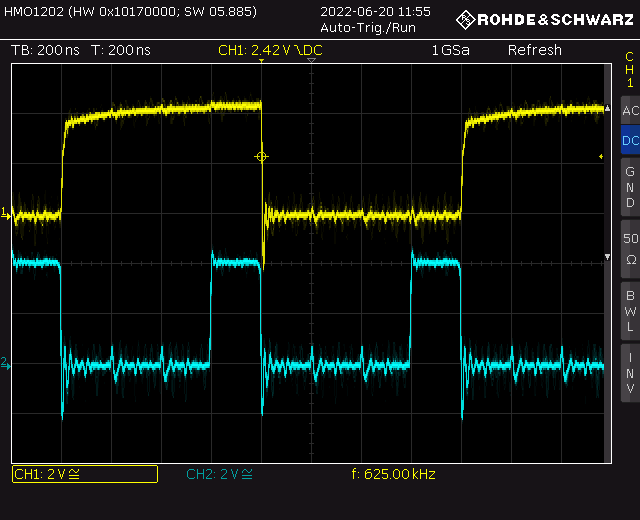
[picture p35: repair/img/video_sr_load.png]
    

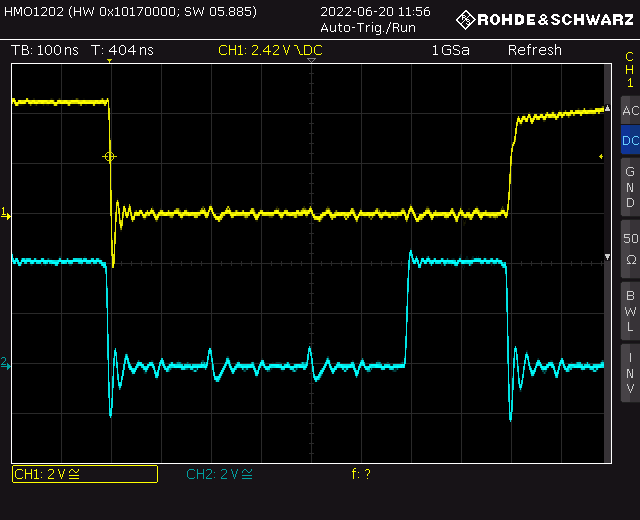
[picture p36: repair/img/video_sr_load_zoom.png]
    

  * pixel shift clock
  
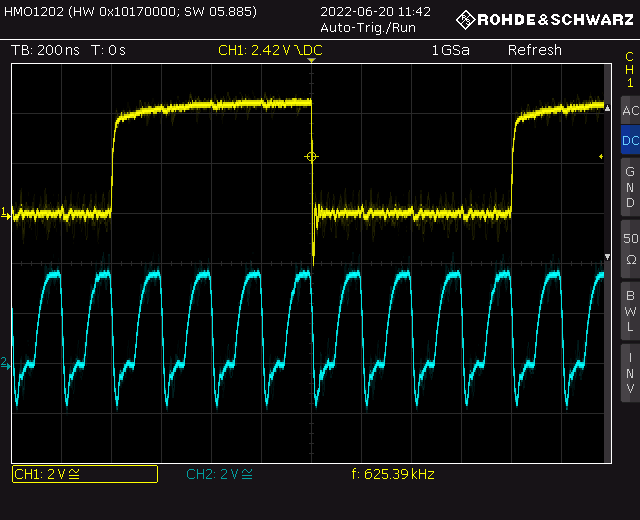
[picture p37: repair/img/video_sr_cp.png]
    
  
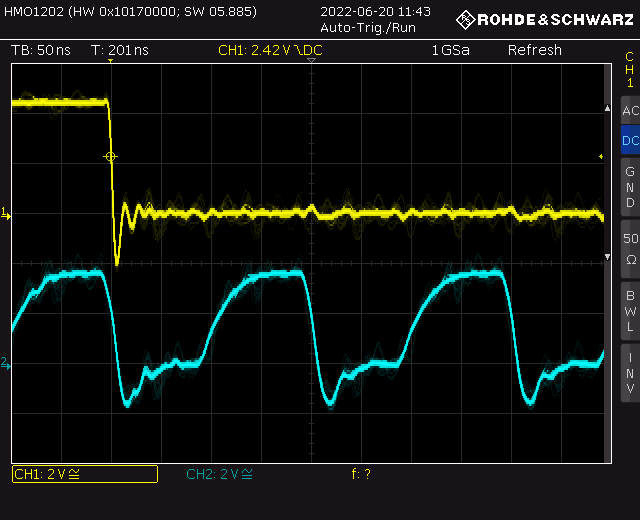
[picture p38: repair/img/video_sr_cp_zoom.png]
    

* all perfectly fine, with load triggered every 4 pixels (there are 4 pixels per byte, remember?)
* I've also poked with my scope at analog outputs, all were alive, so I decided to hook up a TV 
  * yay! there was some random garbage on the screen, but sync was OK, and video was stable, indicating, that RAM / video circuits were working!

#### 7. EPROMs address decoder - fault #3

* at that point I decided to look closely at the CPU activity - to see if it is actually executing any code at all (with assumption that most likely it does, as I've seen memory and I/O reads/writes before, when poking around for other things).

* what I saw at `D0` line was sort of surprise:

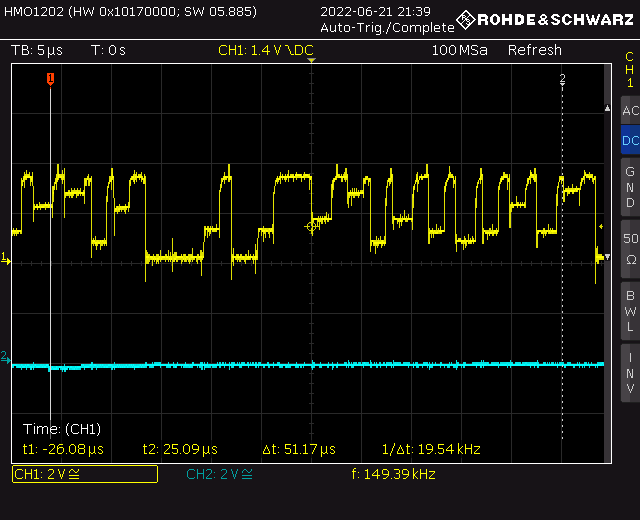
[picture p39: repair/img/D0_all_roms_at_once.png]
  

  It doesn't even look like a digital signal at all. The root cause was `D9` 1-of-8 decoder (`74138`), which generates *Chip Enable* signals selecting 1 of 8 EPROMs, depending on the values of the `A11..A13`address lines. This chip was broken with all outputs low - effectively all EPROMs were **driving the data bus at the same time**. What you see above are the EPROMs fighting :) Replacing the chip solved it.

## Software tests

As I had no more ideas about simple tests I could perform, so I decided to do the following:

* extract all RAM from its sockets
* replace first EPROM with my own test code (unfortunately, only the first EPROM was socketed)
* try to run some absolute minimum code to see if the CPU is actually alive and sane

Note:

* I've used https://github.com/Megatokio/zasm assembler, which has a great feature - 8080 mode with Z80 mnemonics. Z80 syntax is much more familiar to me.
* I've used 2732 EPROMs, I have no spare 2716- it's fine, you only need to program same data twice. The MSB address line of 2732 is connected to 5V const.

That's how we get to...

#### Test #1: output 0xAA / 0x55 pattern via 8255 port A

* this test basically outputs `55/AA` pattern on the on-bard 8255 port A, which is easily accessible via `X2` connector. 

  * source code: [01_hello_pio.asm](../tests/01_hello_pio.asm)

  * remember: no RAM, so no variables, no stack (and thus no jump-to-subroutine)

* I've poked around with my logic analyzer (16 channel) - address bus, data bus, `MEMR`, etc.

* to my surprise,  there were perfectly repeatable EPROM read errors - occasional flips od `D0` from `0` to `1`, leading to wrong code executing 

* on the diagram below, yellow trace is `MEMR`, blue one is `D0` - as you can see at the rising edge of the 3rd read, `D0` slowly goes from 0 to 1, while it should remain 0 for the `MEMR` pulse duration.

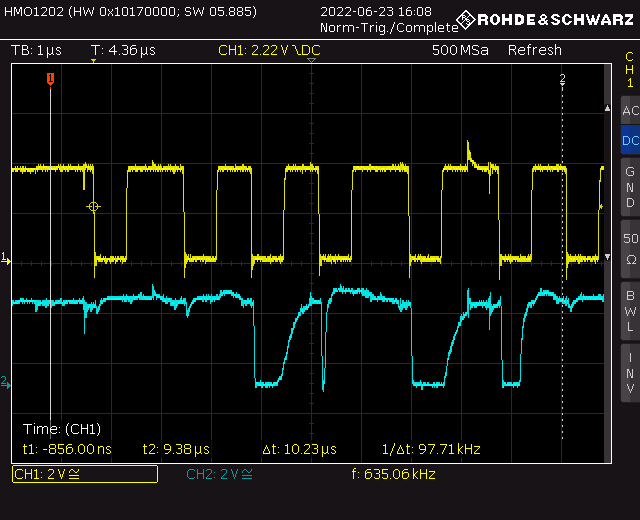
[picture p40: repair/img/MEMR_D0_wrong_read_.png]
  

  * I've decided to eliminate potential `D0` drivers, by cutting `D0` trace / wire leading to both `8255` chips - no change

  * at that point I suspected `D8` (`8228`) being broken (spoiler: I was wrong here)

  * I've decided to desolder all the EPROMs (I suspected a borken EPROM can mess with `D0`), but **nothing changed**, which was sort of puzzling 

  * I've replaced my test EPROM with another one and... everything worked! Which leads to **epic fail story**:

    * my EPROM, Nec `μPD2732`, was OK, but not programmed properly - it requires much longer `Vpp` pulse (`50ms`), than the default I used
    * **lesson #1:** even if verification done right after programming passes OK, it doesn't mean that the EPROM will behave as expected in real application!
    * **lesson #2**: always check your EPROM's datasheet

  * after re-programming the test worked as expected! 

    * so we have **working CPU** and **ability to output bytes to outside world** - that's a great milestone

#### Test 2: dump EPROM contents via 8255 port A - fault #4

* this test basically outputs all the EPROM address space via port A, using `PB2` as strobe signal
  * source code: [02_dump_roms.asm](../tests/02_dump_roms.asm)

* the data can the be grabbed with logic analyzer and compared with expectations (of course one of 8 EPROMs is replaced with my own test code)
  * I've used [DSLogic](https://sigrok.org/wiki/DreamSourceLab_DSLogic) + [PulseView](https://sigrok.org/wiki/PulseView) + [parallel decoder](https://sigrok.org/wiki/Protocol_decoder:Parallel) to grab the data
* so, after soldering the sockets and putting the EPROMs back, I've detected one broken chip, confirmed with EPROM programmer

#### Test 3: test RAM memory

* everything before was done without using RAM - no variables, no call stack
* how can we test RAM without using any variables, relying on CPU registers only?
  * [Linear-feedback shift register](https://en.wikipedia.org/wiki/Linear-feedback_shift_register) to the rescue
  * we can easily implement table-driven LFSR using only registers and 512-bytes const table
  * we can then fill all 64kB of RAM with LFSR-generated pseud-random sequence, then dump it via port A (as in case of EPROM tests), and compare with the same sequence generated on the PC (it is pseudo-random - which means it's perfectly deterministic, the same every time you run the LFSR generator).
  * table was generated using [pycrc](https://pycrc.org/)
  * [03_test_ram.asm](../tests/03_test_ram.asm) is the code fills all the RAM using LFSR, and dumps it back via port A
  * the [lfsr16.py](../test/gen/lfsr16.py) script generates reference [pattern](../test/gen/pattern) to compare against 
* data grabbed via logic analyzer + sigrok compared perfectly! RAM is fine!

#### Test 4: video output

* CPU, ROM and RAM OK - why not try to display something?
* [04_video.asm](../tests/04_video.asm) displays simple slanted bars, with all 4 colors repeating 
* it passed!

## Summary

At this point I decided to put back original EPROM - and Basic prompt appeared! Mission accomplished.

To summarize the faults:

* one short on the PCB (`STSTB` and clock signal)

* 2 broken `74138` chips (one in RAM timing block, one in EPROM chip selection circuitry) 

* one broken EPROM

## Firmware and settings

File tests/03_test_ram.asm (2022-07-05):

;
; Test RAM memory.
;
; The code writes whole RAM with pseudorandom pattern,
; then dump it back via PIO.
;
; Note: when PC1 is set to 1, RAM is mapped in the CPU address space 
;   "as is", which means that address space chunk 0xC000..0xFFFF 
;   (last 16kB) is shadowed by ROM. 
;   If PC1 is set to 0, A15 is always set to 1, thus RAM area 
;   0x8000..0xFFFF is available starting at 0x0000.
;

.org    0xC000

    JP      l1
l1: NOP

    ; configure 8255 - all outputs, mode 0, set PB2 = 0
    LD      A, 0x80
    OUT     (0xC3), A
    LD      A, 0x00
    OUT     (0xC1), A

    ; disable RAM mapping
    LD      A, 0x02
    OUT     (0xC2), A

    ; fill first half of RAM with pattern
    LD      HL, 0x0000  ; target address
    LD      DE, 0xFFFF  ; LFSR
fill1:
    LD      BC, tab

    ; BC += E twice, so BC points to lower byte of tab[E]
    LD      A, E
    ADD     C
    LD      C, A
    LD      A, B
    ADC     0
    LD      B, A
    
    LD      A, E
    ADD     C
    LD      C, A
    LD      A, B
    ADC     0
    LD      B, A
    
    ; A = tab[E] ^ D
    LD      A, (BC) ; A = lower byte from tab
    XOR     D
    LD      (HL), A ; it becomes first output byte
    INC     HL      ;
    LD      E, A    ; ..and new lower byte of the LFSR

    INC     BC      ; next byte...
    LD      A, (BC) ; .. from the table ..
    LD      (HL), A ; .. is next output byte
    INC     HL      ; .. and also ..
    LD      D, A    ; .. becomes new higher byte of the LFSR.

    LD      A, H
    CP      0x80
    JP      NZ, fill1
    LD      A, L
    CP      0x00
    JP      NZ, fill1

    ; switch memory mapping, so second half of RAM is
    ; mapped from address 0
    LD      A, 0x00
    OUT     (0xC2), A

    ; fill second half of RAM
    LD      HL, 0x0000  ; target address
fill2:
    LD      BC, tab

    ; BC += E twice, so BC points to lower byte of tab[E]
    LD      A, E
    ADD     C
    LD      C, A
    LD      A, B
    ADC     0
    LD      B, A
    
    LD      A, E
    ADD     C
    LD      C, A
    LD      A, B
    ADC     0
    LD      B, A
    
    ; A = tab[E] ^ D
    LD      A, (BC) ; A = lower byte from tab
    XOR     D
    LD      (HL), A ; it becomes first output byte
    INC     HL      ;
    LD      E, A    ; ..and new lower byte of the LFSR

    INC     BC      ; next byte...
    LD      A, (BC) ; .. from the table ..
    LD      (HL), A ; .. is next output byte
    INC     HL      ; .. and also ..
    LD      D, A    ; .. becomes new higher byte of the LFSR.

    LD      A, H
    CP      0x80
    JP      NZ, fill2
    LD      A, L
    CP      0x00
    JP      NZ, fill2

    ; switch memory mapping back, so first half of RAM
    ; is available
    LD      A, 0x02
    OUT     (0xC2), A

    ; dump first half of RAM
    LD      HL, 0x0000
    LD      BC, 0x8000
dump_l1:
    LD      A, (HL)
    OUT     (0xC0), A

    ; pulse strobe (PB2)
    LD      A, 0x04
    OUT     (0xC1), A
    LD      A, 0x00
    OUT     (0xC1), A
    NOP
    NOP

    INC     HL
    DEC     BC               
    LD      A, B
    CP      0x00
    JP      NZ, dump_l1
    LD      A, C
    CP      0x00
    JP      NZ, dump_l1


    ; switch mapping
    LD      A, 0x00
    OUT     (0xC2), A

    ; dump first half of RAM
    LD      HL, 0x0000
    LD      BC, 0x8000
dump_l2:
    LD      A, (HL)
    OUT     (0xC0), A

    ; pulse strobe (PB2)
    LD      A, 0x04
    OUT     (0xC1), A
    LD      A, 0x00
    OUT     (0xC1), A
    NOP
    NOP

    INC     HL
    DEC     BC               
    LD      A, B
    CP      0x00
    JP      NZ, dump_l2
    LD      A, C
    CP      0x00
    JP      NZ, dump_l2

    ; endless loop when done
done:
    JP      done


tab:
    incbin "gen/crc_table"

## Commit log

2022-04-27 Bootstrapping schematics
    [lviv.kicad_pcb, lviv.kicad_sch]
2022-05-01 CPU block schematics
    [cpu.kicad_sch, lviv.kicad_sch]
2022-05-02 Schematic: ROM block
    [cpu.kicad_sch, lviv.kicad_sch, rom.kicad_sch]
2022-05-02 Added RAM block schematic placeholder
    [cpu.kicad_sch, lviv.kicad_sch, ram.kicad_sch]
2022-05-06 Chip list fix (К155ИД4 matches 74155, not 74151)
2022-05-07 Schematic: video part w.i.p.
    [lviv.kicad_sch, video.kicad_sch]
2022-05-08 Video part schematic almost complete
    No output connector added, also it needs some review / reality check.
    [lviv.kicad_sch, video.kicad_sch]
2022-05-10 Fixed chip list - К155ИД4 is 74155 not 74151 equivalent
2022-05-10 Sch: added PIO sheet
    [lviv.kicad_sch, pio.kicad_sch, video.kicad_sch]
2022-05-11 Sch: PIO part completed
    [lviv.kicad_sch, pio.kicad_sch]
2022-05-11 ch: PIO fixes
    [pio.kicad_sch]
2022-05-11 Sch: CPU sheet - corrected address buffer pin assignment
    [cpu.kicad_sch]
2022-05-13 Sch: RAM part w.i.p.
    Data path completed, address MUX to be done.
    [lviv.kicad_sch, ram.kicad_sch]
2022-05-16 Sch: RAM sheet completed
    [lviv.kicad_sch, ram.kicad_sch]
2022-05-16 Sch: started timing block
    [lviv.kicad_sch, ram.kicad_sch, timing.kicad_sch]
2022-05-18 Sch: timing sheet - added all elements
    [lviv.kicad_sch, ram.kicad_sch, timing.kicad_sch]
2022-05-19 SCH: timing block - work in progress
    [lviv.kicad_sch, ram.kicad_sch, timing.kicad_sch]
2022-05-23 Extracted RAM controller
    [lviv.kicad_sch, ram.kicad_sch, ram_ctrl.kicad_sch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]
2022-05-23 RAM ctrl updates
    [lviv.kicad_sch, ram_ctrl.kicad_sch]
2022-05-26 RAM controller - rework
    [ram_ctrl.kicad_sch]
2022-05-27 RAM ctrl schematic cleanup completed
    [lviv.kicad_sch, ram_ctrl.kicad_sch]
2022-05-29 Sch: timing counters block completed
    [lviv.kicad_sch, ram_ctrl.kicad_sch, timing.kicad_sch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]
2022-05-30 Minor renames
    [cpu.kicad_sch, ram.kicad_sch]
2022-05-30 Sch: mem remapping circuit moved to ROM sheet
    [cpu.kicad_sch, lviv.kicad_sch, rom.kicad_sch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]
2022-05-30 Sch: video block rework
    [lviv.kicad_sch, ram_ctrl.kicad_sch, timing.kicad_sch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]
2022-05-31 Sch: video block cleanup in progress
    [cpu.kicad_sch, ram_ctrl.kicad_sch, rom.kicad_sch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]
2022-06-02 Connector pinouts
2022-06-02 Sch: CPU block cleanup
    [cpu.kicad_sch]
2022-06-02 Sch: timing block completed
    [timing.kicad_sch]
2022-06-04 Sch: CPU - added wait state injection FF
    [cpu.kicad_sch]
2022-06-04 Sch: timing - part annotations
    [timing.kicad_sch]
2022-06-04 Sch: CPU - part annotations
    [cpu.kicad_sch]
2022-06-04 Sch: PIO block completed
    Added X2 connector.
    [pio.kicad_sch]
2022-06-04 Sch: CPU - add R10 value
    [cpu.kicad_sch]
2022-06-04 VSch: video block completed
    [lviv.kicad_sch, video.kicad_sch]
2022-06-09 Schematics complete
    Todo:
    - part values
    - full review
    [connectors.kicad_sch, lviv.kicad_sch, pio.kicad_sch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]
2022-06-10 Schematics completed with values
    Visual corrections pending
    [connectors.kicad_sch, cpu.kicad_sch, lviv.kicad_sch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]
2022-06-10 Sch: visual corrections
    [connectors.kicad_sch, lviv.kicad_sch, pio.kicad_sch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]
2022-06-22 Implemented first test case
    It continuously outputs 0x55 / 0xAA on PIO port A, using no RAM.
2022-06-28 Sch: fixed 8224 symbol (missing +12V power pin)
    [cpu.kicad_sch, lviv.kicad_sch]
2022-06-28 Added schematic PDFs
2022-07-04 Added pseudo-random test data generator.
    It's a 16-bit table driven LFSR pseudo-random data generator, assembly
    version of it will be used to generate RAM test data.
2022-07-04 RAM test - added address space switching
2022-07-04 RAM test - LFSR code wirtten, ready for review
2022-07-05 Test 03 - looping fix
    [03_test_ram.asm]
2022-07-05 Added video output test case
2022-07-06 Regenerated schematic PDFs with better quality
    Lessone learnt - plot to PDF from KiCAD, don't print.
2022-07-08 SCART cable docs
2026-06-17 Scart cable
